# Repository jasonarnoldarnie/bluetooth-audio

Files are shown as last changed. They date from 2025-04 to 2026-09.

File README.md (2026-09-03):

# bluetooth-audio
Hardware and firmware for bluetooth audio adaptor

## Repo setup

Hooks live in `.githooks/` (version controlled), so each clone needs one command to enable them:

```bash
git config core.hooksPath .githooks
```

The `pre-commit` hook re-stamps the "Updated" date in [`docs/design-overview.tex`](docs/design-overview.tex)
and renders [`docs/design-overview.pdf`](docs/design-overview.pdf) into the same commit. It runs only
when that document is staged, never blocks a commit, and needs [Tectonic](https://tectonic-typesetting.github.io/)
(XeTeX) on `PATH` or in `%LOCALAPPDATA%\Programs\Tectonic` (Python is used only for the date stamp).
The diagrams render in the Consolas monospace font (a Windows system font); on other platforms swap it
for another mono font with box-drawing glyphs in the document preamble.

- `git config hooks.designpdf false` — disable without deleting the hook
- `git config hooks.designpdf.snapshot true` — also keep a dated copy under `docs/snapshots/`

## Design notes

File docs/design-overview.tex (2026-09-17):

% Bluetooth Audio Adaptor — Design Overview
% Rendered with Tectonic (XeTeX).  Build:  tectonic design-overview.tex
% The "Updated" date on the stamp line below is refreshed by the pre-commit hook.
\documentclass[11pt]{article}

\usepackage[a4paper,margin=2cm]{geometry}
\usepackage{fontspec}
% Latin Modern is served from Tectonic's bundle by filename (by-name lookup is unreliable here).
\setmainfont{lmroman10-regular.otf}[
  BoldFont       = lmroman10-bold.otf,
  ItalicFont     = lmroman10-italic.otf,
  BoldItalicFont = lmroman10-bolditalic.otf,
]
% Consolas is a Windows system font, resolved by name; it has the box-drawing glyphs the
% ASCII diagrams need (Latin Modern Mono does not).
\setmonofont{Consolas}[Scale=0.85]
\usepackage{textcomp}
\usepackage{amssymb}
\usepackage[table,dvipsnames]{xcolor}
\usepackage{tabularx}
\usepackage{booktabs}
\usepackage{longtable}
\usepackage{array}
\usepackage{enumitem}
\usepackage{fancyvrb}
\usepackage{newunicodechar}
\usepackage{parskip}
\usepackage[hidelinks]{hyperref}
\usepackage{underscore} % must load late: lets SIGNAL_NAMEs be typed with a literal _

\setcounter{secnumdepth}{2}
\setcounter{tocdepth}{2}
\fvset{fontsize=\footnotesize}
\newcolumntype{L}[1]{>{\raggedright\arraybackslash}p{#1}}

% --- Unicode glyphs used in prose/tables (verbatim blocks bypass these) ----------
\newunicodechar{≈}{\ensuremath{\approx}}
\newunicodechar{≤}{\ensuremath{\le}}
\newunicodechar{≥}{\ensuremath{\ge}}
\newunicodechar{→}{\ensuremath{\rightarrow}}
\newunicodechar{←}{\ensuremath{\leftarrow}}
\newunicodechar{↔}{\ensuremath{\leftrightarrow}}
\newunicodechar{×}{\ensuremath{\times}}
\newunicodechar{−}{\ensuremath{-}}
\newunicodechar{±}{\ensuremath{\pm}}
\newunicodechar{·}{\textperiodcentered}
\newunicodechar{°}{\textdegree}
\newunicodechar{µ}{\textmu}
\newunicodechar{μ}{\textmu}
\newunicodechar{Ω}{\ensuremath{\Omega}}
\newunicodechar{Ω}{\ensuremath{\Omega}} % U+2126 ohm sign
\newunicodechar{θ}{\ensuremath{\theta}}
\newunicodechar{Δ}{\ensuremath{\Delta}}
\newunicodechar{τ}{\ensuremath{\tau}}
\newunicodechar{π}{\ensuremath{\pi}}
\newunicodechar{‖}{\ensuremath{\|}}
\newunicodechar{∥}{\ensuremath{\|}}
\newunicodechar{✓}{\ensuremath{\checkmark}}
\newunicodechar{✅}{\ensuremath{\checkmark}}
\newunicodechar{⁴}{\textsuperscript{4}}
\newunicodechar{✗}{\ensuremath{\times}}

% Callout box for notes / accepted risks
\newenvironment{callout}
  {\par\medskip\noindent\begin{minipage}{\linewidth}\color{black}%
   \setlength{\parskip}{4pt}\leftskip=1.5em \rightskip=1em\relax}
  {\end{minipage}\par\medskip}

% Document stamp (hook updates the date)
\newcommand{\docrev}{Rev B (in design)}
\newcommand{\docdate}{2026-09-17}
\newcommand{\docauthor}{Jason}

\begin{document}

\begin{center}
  {\LARGE\bfseries Bluetooth Audio Adaptor — Design Overview}\\[6pt]
  {\large\textbf{\docrev} · Updated \docdate\ · \docauthor}
\end{center}

Describes the \textbf{target design}. Deltas from as-built Rev~A are listed in §10.

\begin{callout}
Living document. Every confirmed design change lands here. Planning, open questions and review
findings live in \texttt{requirements-design.md} and \texttt{design-review-v1.md} — not here.
\end{callout}

\hrule
\section{Function}

Bluetooth audio adaptor for a car AUX input. Powered from USB-C or an internal Li-ion cell.

\begin{tabularx}{\linewidth}{@{}l X l@{}}
\toprule
\textbf{Mode} & \textbf{Path} & \textbf{Status} \\
\midrule
\textbf{RX} (primary) & Phone → Bluetooth A2DP → codec DAC → 3.5 mm out & Rev A hardware complete \\
\textbf{TX}           & 3.5 mm in → codec ADC → Bluetooth → headphones/speaker & Rev B addition \\
\textbf{HFP} handsfree & On-board mic → codec ADC → BT; BT → DAC → jack & Rev B addition \\
\bottomrule
\end{tabularx}

\textbf{Key constraint:} must work with all phones, not just recent ones → \textbf{Bluetooth Classic
(A2DP/HFP), not BLE Audio}. This single requirement determines the MCU (§5).

\textbf{Out of scope:} amplified speaker output, multipoint pairing, app control.

\section{Architecture}

\textbf{Power tree}

\begin{Verbatim}
                      ┌──────────────────┐
                      │  Li-ion cell     │──── NTC ──► TS   temperature qualification
                      │  + 10 k NTC      │
                      └────────▲─────────┘
                               │ BAT ──[100k]──┬── BAT_ADC ──► ADC1
                               │               └──[100k]── GND
  USB-C ── VBUS 5 V ──► ┌──────┴───────┐
    ├─ USBLC6 (ESD)     │   BQ24074    │  power path · DPPM
    ├─ CC1/CC2 ──► ADC1 │   charger    │  SYS clamped ≤ 4.4 V
    └─ C47 10 µF        └──┬───────┬───┘
                           │       ├── EN1 / EN2  ◄── GPIO   input-limit select
       ILIM ISET ──────────┘       ├── /PGOOD, /CHG ──► GPIO
       ITERM TMR                   │
                               SYS │ 3.0 – 4.4 V
                     ┌─────────┴─────────┐
                     ▼                   ▼
              ┌─────────────┐     ┌─────────────┐
              │   LDO A     │     │   LDO B     │
              │  AP7361C    │     │  LP5907     │
              │  SOT-89 1 A │     │  low noise  │
              └──────┬──────┘     └──────┬──────┘
                     │ 3V3_A             │ 3V3_B
                     │                   │
         ESP32 · flash · CH340K       ES8388 · MEMS mic
              · LEDs  (280 mA pk)          (20 mA)
\end{Verbatim}

\textbf{Signal chain}

\begin{Verbatim}
   40 MHz XTAL ──┐        ┌── W25Q32JV 4 MB flash
                 │        │
   PCB antenna   │        │ SPI          USB-C ── USBLC6 ── CH340K
   + C-L-C match─┤        │                                    │
                 ▼        ▼                                    │ UART
              ┌──────────────────────────┐                     │ + DTR/RTS
              │     ESP32-D0WD-V3        │◄────────────────────┘
              │  BT Classic + BLE        │
              └──────┬────────────┬──────┘
                 I2C │        I2S │  (MCLK/SCLK/LRCK/DSDIN/ASDOUT)
                     ▼            ▼
              ┌──────────────────────────┐
              │   ES8388 stereo codec    │
              └───▲──────────┬───────▲───┘
             LIN1 │  LOUT1/  │       │ LIN2/RIN2
                  │  ROUT1   ▼       │
                  │      ┌───────────┴───────┐
                  │      │  TS5A23159 SPDT   │  TX / RX select
                  │      └─────────┬─────────┘
                  │                │ 47 µF coupling (jack side)
                  │                ▼
          on-board MEMS mic   3.5 mm TRS jack
          (ZTS6216 single-ended)
\end{Verbatim}

\textbf{Rails}

\begin{tabularx}{\linewidth}{@{}l l X X@{}}
\toprule
\textbf{Rail} & \textbf{Source} & \textbf{Loads} & \textbf{Why separate} \\
\midrule
SYS 3.0–4.4 V & BQ24074 & Both LDOs & Power path: USB when present, battery when not \\
3V3_A & LDO A & ESP32, flash, CH340K, LEDs & Carries RF current bursts \\
3V3_B & LDO B (LP5907) & ES8388, mic & Isolates a 96 dB codec from those bursts \\
\bottomrule
\end{tabularx}

\section{Power subsystem}

Linear regulation throughout. A switching converter was rejected: this is a mixed-signal audio
board and the efficiency gain does not pay for the noise.

\begin{tabularx}{\linewidth}{@{}l l X@{}}
\toprule
\textbf{Part} & \textbf{Function} & \textbf{Key spec} \\
\midrule
\textbf{BQ24074RGTR} (C54313) & Power-path charger & 1.5 A, SYS clamped ≤4.4 V, DPPM, NTC input, 10.5 V OVP \\
\textbf{AP7361C-33Y5-13} (C460397) & LDO A — digital/RF & SOT-89-5, 1 A, ultra-low dropout \\
\textbf{LP5907MFX-3.3} (C80670) & LDO B — codec analog & 6.5 µV\textsubscript{RMS}, high PSRR, no bypass cap needed \\
\textbf{USBLC6-2SC6} & USB ESD & In-line on D+/D−; its \texttt{VBUS} pin stays at the connector, upstream of the charger \\
Li-ion cell + 10 k NTC & Energy & Removable. NTC bonded to cell, not PCB \\
\bottomrule
\end{tabularx}

\textbf{VBUS reaches exactly three things:} the ESD array, the charger's \texttt{IN} pin, and
\texttt{C47}. Every other load in the system hangs off \texttt{SYS}, including both LDOs. That is what
makes the board behave identically on USB and on battery.

\subsection{Power path — the five loops}

In priority order. The system load always outranks the battery.

\begin{tabularx}{\linewidth}{@{}l l X@{}}
\toprule
\textbf{Loop} & \textbf{Trips at} & \textbf{Behaviour} \\
\midrule
Input current limit & \texttt{EN1}/\texttt{EN2} + \texttt{R_ILIM} & Hard ceiling on total current into \texttt{IN}. Everything else lives inside this budget \\
VIN-DPM & V\textsubscript{IN} falls to 4.5 V & Reduces input current so a weak source cannot be crashed. \textbf{Active only in USB100/USB500 modes} \\
DPPM & V\textsubscript{SYS} falls to V\textsubscript{O(REG)} − 100 mV ≈ 4.3 V & Cuts \textit{charge} current to hold SYS up. Charge termination is disabled while active \\
Battery supplement & V\textsubscript{SYS} < V\textsubscript{BAT} − 40 mV & Charge current already zero and the load still exceeds the input limit — BATFET turns fully on and the cell supplements. Exits above V\textsubscript{BAT} − 20 mV \\
Thermal regulation & T\textsubscript{J} ≥ 125 °C & Folds back charge current regardless of the above \\
\bottomrule
\end{tabularx}

The last three slow the safety timers \textbf{in proportion to the charge-current reduction}. A
deliberately low \texttt{R_ISET} gets no such slowdown — the timer would run at full speed while the
cell trickled. This is why \texttt{R_ISET} is set \textit{above} anything the input can deliver, and
DPPM is left to mediate (§3.3).

\subsection{Input current limit — mode strapping}

\texttt{EN2}/\texttt{EN1} select the limit. Datasheet Table 7-2 orders the columns EN2, EN1:

\begin{tabularx}{\linewidth}{@{}c c l X@{}}
\toprule
\textbf{EN2} & \textbf{EN1} & \textbf{Limit} & \textbf{When} \\
\midrule
0 & \textbf{1} & \textbf{475 mA (USB500)} & \textbf{Power-on default} — and any unknown or default-USB source \\
1 & 0 & 1.073 A (\texttt{R_ILIM}) & Firmware has confirmed a ≥1.5 A source (§3.4) \\
0 & 0 & 95 mA (USB100) & Strict compliance on an un-enumerated host port \\
1 & 1 & — & Standby / USB suspend \\
\bottomrule
\end{tabularx}

\textbf{The default must be USB500, not USB100.} Both pins floating gives USB100 through the chip's
285 kΩ internal pulldowns, and 100 mA cannot run a 171 mA system: with a flat cell the board would
brown out before firmware ran and could never raise the limit. USB500 boots the system, matches what
a PC port allows after enumeration, and is a mode that has VIN-DPM behind it.

\begin{Verbatim}
   SYS ──[R30 100k]──┬── EN1 ──► GPIO (drive open-drain)     default HIGH (3.26 V)
                     │
                (285k internal pulldown)

   GND ──[R31 100k]──┴── EN2 ──► GPIO (push-pull)            default LOW
\end{Verbatim}

\textbf{100 kΩ, not 0 Ω} — the GPIO must be able to override the resistor. Against the internal
285 kΩ, EN1 sits at 4.4 × 285/385 = 3.26 V, comfortably over the 1.4 V V\textsubscript{IH}.

\textbf{Pull up to \texttt{SYS}, not \texttt{3V3_A}} — \texttt{3V3_A} does not exist until the system
has booted, and the whole point of the default is to be defined before that. \texttt{SYS} is present
whenever either source is, and at 4.4 V max sits inside the EN pin's 1.4–6 V window (7 V absolute
max).

Drive \texttt{EN1} open-drain: the pull-up is to 4.4 V and the GPIO drives 3.3 V. Leave both pins
alone whenever \texttt{/PGOOD} is high-Z — the EN inputs are ignored in power-down mode, and driving
EN1 low would only burn cell current through R30.

\subsection{Charge programming}

\begin{tabularx}{\linewidth}{@{}l l X l@{}}
\toprule
\textbf{Resistor} & \textbf{Value} & \textbf{Formula} & \textbf{Result} \\
\midrule
\texttt{R_ISET} & 1.2 kΩ \textbf{1 \%} & I\textsubscript{CHG} = K\textsubscript{ISET}/R, K = 890 & \textbf{742 mA} (664–812 over spread) \\
\texttt{R_ILIM} & 1.5 kΩ & I\textsubscript{IN(max)} = K\textsubscript{ILIM}/R, K = 1610 & \textbf{1.073 A} \\
\texttt{R_ITERM} & 3.0 kΩ & I\textsubscript{TERM} = 0.03 × R\textsubscript{ITERM}/R\textsubscript{ISET} & \textbf{75 mA} (≈C/27 on a 2000 mAh cell) \\
\texttt{R_TMR} & 56 kΩ & t\textsubscript{MAXCHG} = 10 × K\textsubscript{TMR} × R, K = 48 s/kΩ & \textbf{7.5 h} (5.6 h worst case) \\
\bottomrule
\end{tabularx}

Pre-charge falls out of the same ISET resistor: K\textsubscript{PRECHG}/R\textsubscript{ISET} =
88/1200 = \textbf{73 mA}, the conventional 10 \% of fast charge.

742 mA is 0.37C on a 2000 mAh cell and 0.25C on a 3000 mAh one — safe for either, so this resistor
does not depend on the cell decision. Use 1 \% on \texttt{R_ISET}: TI calls this out specifically to
avoid tripping the internal RISET short-circuit test.

\textbf{\texttt{ILIM} must never be left open — an open \texttt{ILIM} pin disables all charging.}
Worth an explicit bring-up check.

\texttt{R_NTC_LIN} is fitted \textbf{DNP} by design: it stands in for the pack NTC if a cell without
one is used, or can be replaced by a high-value linearising resistor. It must not be populated
alongside a real NTC — see §3.6.

\subsection{Source capability detection}

The default is USB500, so detection only ever has to answer one question: \textbf{is this a ≥1.5 A
charger?} Everything else falls back safely.

\textbf{CC sensing (C-to-C only).} \texttt{R36}/\texttt{R37} tap CC1/CC2 through 1 kΩ into ADC1. With
Rd = 5.1 kΩ:

\begin{tabularx}{\linewidth}{@{}l l X@{}}
\toprule
\textbf{Source Rp} & \textbf{V\textsubscript{CC}} & \textbf{Advertised} \\
\midrule
56 kΩ & 0.42 V & Default USB \\
22 kΩ & 0.94 V & 1.5 A \\
10 kΩ & 1.69 V & 3.0 A \\
\bottomrule
\end{tabularx}

Thresholds: >0.2 V attached, >0.66 V ≥ 1.5 A, >1.23 V = 3.0 A. Read \textbf{both} pins — only one
carries the Rp, the other is open or is VCONN, and the pair also gives plug orientation. \textbf{No
filter capacitor on the CC nodes:} the spec caps sink CC capacitance at ≈200 pF. Multisample in
software instead. Re-read periodically; a source may change its advertisement at any time.

\textbf{The limitation that shapes the architecture:} a USB-A-to-C cable is \textit{required} by the
spec to contain a 56 kΩ Rp, so CC always reports Default USB no matter how large the charger behind
it. For the expected majority case — an A-to-C cable — CC sensing tells you nothing.

\textbf{BC1.2 (not fitted).} The only mechanism that unlocks a USB-A wall charger, by detecting that
D+ is shorted to D− through ≤200 Ω (a Dedicated Charging Port). Needs a detector IC — BQ24392 or
MAX14636 — whose integrated D+/D− isolation switch also solves the problem that the CH340K sits on
that bus. Deferred; the EN1/EN2 GPIO control above is what keeps it a firmware-plus-one-IC change
rather than a respin.

\textbf{Guard rail.} ILIM mode has no VIN-DPM, so a wrong detection has no graceful foldback.
\texttt{R38}/\texttt{R39} (100 k / 47 k) divide VBUS to \texttt{USB_VBUS_SENSE} — 5.0 V → 1.60 V,
5.5 V → 1.76 V — with \texttt{C53} 100 nF at the tap. Firmware reverts to USB500 if VBUS sags below
≈4.5 V. The divider only draws (34 µA) when USB is present, so it costs nothing on battery.

100 nF rather than the 1 µF used on \texttt{BAT_ADC}: this is a protection function with a deadline.
Against the divider's 32 kΩ Thévenin impedance it gives τ = 3.2 ms, so a 100 ms poll sees a collapse
≈30 τ after it happens. A larger cap would average over a third of the reaction window.

\textbf{Do not} probe adaptively — stepping up to ILIM mode and watching what happens. Without
VIN-DPM the failure mode is a brownout, not a graceful foldback.

\begin{callout}
\textbf{Accepted risk — CC pins have no ESD protection.} The USBLC6 covers D+/D− and VBUS only. CC1
and CC2 are exposed contacts in the receptacle and are directly touchable, so IEC 61000-4-2 contact
discharge is a live threat. The 1 kΩ series resistors (\texttt{R36}/\texttt{R37}) protect the ADC
pins but not \texttt{R4}/\texttt{R5} or the connector node itself. They also bound a VBUS-to-CC
short — which the USB-C spec requires sinks to survive — to (5 − 3.6)/1 k ≈ 1.4 mA of clamp injection
at the ESP32, which the pin tolerates; a faulty 20 V source would push 16 mA, which it does not.

\textbf{Decision (2026-08-30): not mitigated in Rev B.} The fix, if it is ever wanted, is a
low-capacitance TVS array on CC1/CC2 placed at the connector ahead of \texttt{R36}/\texttt{R37} —
sub-pF against the ≈200 pF sink CC budget, and low leakage so it does not corrupt the resistive
advertisement. TPD4E05U06 is the obvious candidate. Revisit if field units show USB-C detection
failures.
\end{callout}

\subsection{Safety timers}

\texttt{R_TMR} = 56 kΩ gives a 7.5 h fast-charge timer (5.6 h worst case) and a 45 min pre-charge
timer. Leaving \texttt{TMR} floating selects the internal default of 5 h typ / 4 h min; grounding it
disables the timers entirely.

The timer must outlast the slowest legitimate charge. Worst case is a 3000 mAh cell charging in
USB500 mode while playing: ≈304 mA of charge current against 742 mA programmed is a 0.41 reduction,
so the 5.6 h timer counts at 0.41× and covers 13.7 h of wall clock against an 8.9 h charge.

On expiry the part latches a fault and \textbf{\texttt{/CHG} flashes at ≈2 Hz}. Firmware should
decode that — it is also how a TS fault surfaces, and it is otherwise invisible.

\subsection{Battery temperature qualification}

Mandatory in hardware, not firmware. \texttt{TS} sources 75 µA into the pack thermistor and compares:

\begin{Verbatim}
V_HOT  = 300 mV   →  R_TS ≤ 4.0 kΩ   →  too hot    (≈50 °C on a 10 k 103AT-2)
V_COLD = 2100 mV  →  R_TS ≥ 28 kΩ    →  too cold   (≈ 0 °C)
\end{Verbatim}

The valid window is therefore \textbf{4.0 kΩ – 28 kΩ}, which a bare 10 k Type-2 NTC maps onto
0–50 °C with 3 °C hysteresis. Any added network shifts those trip points: a 10 kΩ resistor in
parallel with the NTC moves the hot trip to ≈33 °C, and a 1 kΩ resistor pins R\textsubscript{TS}
below 1 kΩ permanently, inhibiting all charging. \textbf{Fit the pack NTC or \texttt{R_NTC_LIN},
never both.}

\subsection{Status and state of charge}

\texttt{/PGOOD} and \texttt{/CHG} are open-drain, pulled up to \textbf{\texttt{3V3_A}} (not
\texttt{SYS}) so both nets are clean 3.3 V logic a GPIO can read directly — pulling them to the 4.4 V
SYS rail would exceed the ESP32's input rating.

\begin{tabularx}{\linewidth}{@{}l l X@{}}
\toprule
\textbf{/PGOOD} & \textbf{/CHG} & \textbf{State} \\
\midrule
Hi-Z & Hi-Z & Running on battery \\
Low & Low & Charging \\
Low & Hi-Z & Charge complete, or suspended \\
Low & \textbf{2 Hz flash} & Fault — safety timer expired, or TS out of range \\
\bottomrule
\end{tabularx}

\texttt{R28}/\texttt{R29} are 330 Ω, giving ≈2.7 mA per LED at 3.3 V — visible, and inside the 5 mA
the \texttt{/PGOOD} and \texttt{/CHG} open-drain outputs are specified to sink. Both LEDs are dark on
battery, since the pins go high-impedance with no input present.

\textbf{State of charge} is voltage-based: \texttt{R34}/\texttt{R35} form a 100 k / 100 k divider
from \texttt{BAT} to ground, tapped as \texttt{BAT_ADC} (4.2 V → 2.1 V, inside ADC1's usable
150–2450 mV window at 11 dB attenuation). It costs 21 µA continuously, ≈15 mAh/month — negligible
against the cell.

\textbf{\texttt{C52} 100 nF at the tap is not optional, and it is not impedance matching.} It does
two jobs:

\begin{itemize}[leftmargin=1.4em]
\item \textbf{Charge reservoir.} The ESP32's ADC is successive-approximation: closing the sampling
  switch requires an internal sample-and-hold capacitor of a few pF to charge to the input voltage
  \textit{through the external source impedance}, in a few microseconds. The divider's Thévenin
  impedance is 100 k ‖ 100 k = \textbf{50 kΩ}, five times Espressif's <10 kΩ guideline, so without a
  local cap each conversion drags the node down and the converter digitises the droop. At ≈10⁴ times
  the S/H capacitance, \texttt{C52} supplies that charge with no measurable sag and refills through
  the 50 kΩ between samples.
\item \textbf{Low-pass filter.} f_c = 1/(2π × 50 k × 100 nF) = \textbf{31.8 Hz}, τ = 5 ms.
  \texttt{BAT_ADC} is a high-impedance trace crossing the board — exactly the node that collects
  switching and RF noise — and cell voltage moves over minutes, so heavy filtering is free accuracy.
  Allow ≈25 ms after power-up before trusting a reading.
\end{itemize}

The alternative was a lower-impedance divider: 10 k / 10 k needs no cap but draws 210 µA from the
cell permanently instead of 21 µA. The capacitor is the cheaper trade.

Calibrate with \texttt{esp_adc_cal} and the eFuse Vref, and multisample; raw ADC error is ±6 \%,
which is ±250 mV of cell voltage and useless.

Two limits define what this can deliver. The reading is meaningless while charging — the charger is
driving V\textsubscript{BAT} toward 4.2 V — so firmware uses the \texttt{/PGOOD}+\texttt{/CHG} state
instead and snaps to 100 \% on termination. And the Li-ion OCV curve is flat from roughly 20 \% to
80 \% SoC, so voltage alone gives ±10–15 \% there. \textbf{This is a four-segment gauge and a
dependable low-battery warning, not a trustworthy percentage.} If a real percentage is ever needed
over AVRCP, add a MAX17048 to the existing I²C bus.

\subsection{ESP32 GPIO map (committed 2026-08-31, netlist-verified)}

Complete map. The budget is \textbf{full}: one spare (\texttt{GPIO33}). \textbf{S} marks an ESP32
strapping pin — its level is latched at reset, so anything on it must present the right level at boot
(see the implications list below). All analog is on \textbf{ADC1} because ADC2 is dead whenever the
radio is on.

\footnotesize
\begin{longtable}{@{}c c L{3.4cm} c c L{6.2cm}@{}}
\toprule
\textbf{GPIO} & \textbf{Pin} & \textbf{Signal} & \textbf{Dir} & \textbf{S} & \textbf{Boot level / notes} \\
\midrule
\endfirsthead
\toprule
\textbf{GPIO} & \textbf{Pin} & \textbf{Signal} & \textbf{Dir} & \textbf{S} & \textbf{Boot level / notes} \\
\midrule
\endhead
0 & 23 & \texttt{MCLK} (I²S) & out & \textbf{S} & Must be HIGH at boot. Internal PU; codec MCLK input is Hi-Z at reset. Auto-boot pulls it low for download. \\
1 & 41 & \texttt{UART_TX} (U0TXD → CH340 RXD) & out & & Boot-log UART. \\
2 & 22 & \texttt{CHARGE_EN} (→ charger \texttt{/CE}) & out & \textbf{S} & Must be LOW/float at boot — and \texttt{R32} (1 k→GND) holds it low, which also = \textbf{charging enabled}. FW drives HIGH to pause charging; any reset re-enables (fail-safe). Keeps TP4. \\
3 & 40 & \texttt{UART_RX} (U0RXD ← CH340 TXD) & in & & \\
4 & 24 & \texttt{AUDIO_VCC_EN} (→ LDO B EN) & out & & \texttt{R33} pulldown → codec rail \textbf{off at boot}; FW raises to power codec. \\
5 & 34 & \texttt{AUDIO_SW} (→ TS5A23159 IN1+IN2) & out & \textbf{S} & Internal PU → HIGH at boot = \textbf{TX} by default. \textbf{Do not add an external pull.} FW sets \textbf{LOW = RX}, HIGH = TX. \\
6–11 & 31,32,33,28,29,30 & SPI flash (\texttt{CLK}/\texttt{SD0-3}/\texttt{CMD}) & — & & Reserved for \texttt{VDD_SDIO} flash. Not available. \\
12 & 18 & \texttt{MTDI} (JTAG TDI) & I/O & \textbf{S} & \textbf{VDD_SDIO voltage select — must be LOW at boot for 3.3 V flash.} Pull-up \texttt{R26} is \textbf{DNP — do not populate.} A debugger driving TDI high across reset bricks boot. \\
13 & 20 & \texttt{MTCK} (JTAG) & I/O & & J4 DNP header. \\
14 & 17 & \texttt{MTMS} (JTAG) & I/O & & J4 DNP header. \\
15 & 21 & \texttt{MTDO} (JTAG TDO) & I/O & \textbf{S} & Must be HIGH at boot (enables boot log). Internal PU. \\
16 & 25 & \texttt{EN1} (charger limit) & out (OD) & & Drive \textbf{open-drain} (pull-up is to 4.4 V SYS). Ext 100 k→SYS = USB500 default at boot. \\
17 & 27 & \texttt{EN2} (charger limit) & out & & Ext 100 k→GND = default LOW at boot. \\
18 & 35 & \texttt{I2C_CLK} & I/O & & To ES8388 + codec bus. \\
19 & 38 & \texttt{LED_GREEN} & out & & \\
21 & 42 & \texttt{CH340_EN} (→ Q2 gate) & out & & \texttt{R40} pulldown → \textbf{default ON} so the bridge is powered for flashing; FW drives HIGH to disable on battery. \\
22 & 39 & \texttt{LED_BLUE} & out & & \\
23 & 36 & \texttt{I2C_DATA} & I/O & & \\
25 & 14 & \texttt{LRCK} (I²S) & I/O & & \\
26 & 15 & \texttt{DSDIN} (I²S) & out & & \\
27 & 16 & \texttt{SCLK} (I²S) & I/O & & \\
32 & 12 & \texttt{/CHG} (charger status) & in & & ADC1_CH4 used as digital in. \\
33 & 13 & \textbf{spare} & — & & ADC1_CH5. Fit a no-connect flag. \\
34 & 10 & \texttt{BAT_ADC} & in & & ADC1_CH6, input-only. \\
35 & 11 & \texttt{ASDOUT} (I²S data in) & in & & ADC1_CH7, input-only — correct home for an input-only signal. \\
36 & 5 & \texttt{USB_CC1} & in & & ADC1_CH0, input-only. \\
37 & 6 & \texttt{USB_CC2} & in & & ADC1_CH1, input-only. \\
38 & 7 & \texttt{/PGOOD} (charger status) & in & & ADC1_CH2, input-only. \\
39 & 8 & \texttt{USB_VBUS_SENSE} & in & & ADC1_CH3, input-only. \\
\bottomrule
\end{longtable}
\normalsize

\textbf{Strapping-pin implications (the ones that bite):}

\begin{itemize}[leftmargin=1.4em]
\item \textbf{GPIO0 / GPIO2} — the boot-mode pair. Normal boot needs GPIO0 high, GPIO2 low. GPIO0
  doubles as MCLK (codec input Hi-Z at reset, so safe) and the auto-boot circuit pulls it low to
  flash. GPIO2 = \texttt{CHARGE_EN}, held low by \texttt{R32} — which satisfies both "low at boot"
  \textit{and} "charging enabled by default." FW must only drive GPIO2 high (pause charge)
  \textit{after} boot.
\item \textbf{GPIO12 (MTDI)} — sets flash voltage at reset. It \textbf{must be low} (→ 3.3 V);
  \texttt{R26} is the 1.8 V pull-up and is \textbf{DNP by design}. HW: never populate \texttt{R26}.
  FW/bench: an attached JTAG debugger can drive TDI high across reset and select 1.8 V, bricking
  boot — either detach during power-up or burn the \texttt{XPD_SDIO_*} eFuses to force 3.3 V
  (irreversible).
\item \textbf{GPIO15 (MTDO)} must be high at reset (internal PU handles it); leave it undriven at
  boot.
\item \textbf{GPIO5 (AUDIO_SW)} samples high at reset (SDIO-timing strap, irrelevant here).
  Consequence: the audio switch defaults to \textbf{TX} at boot. Harmless (no audio yet); FW drives
  it \textbf{low = RX} on init. The only HW rule: \textbf{do not tie an external pull to GPIO5}, or
  it fights the strap.
\item General FW rule: every strapping pin used as an output must be left as an input (Hi-Z) through
  reset and only driven once the app starts — external pulls (or the internal strap pull) set the
  boot state.
\end{itemize}

\textbf{Safety.} Charging is inhibited outside the cell's temperature window in hardware via the NTC
on \texttt{TS} — not in firmware. Cell is removable; device is not stored in the vehicle.

\textbf{Why not LFP:} 3.2 V nominal sits below the 3.3 V rail for most of its discharge, forcing a
boost converter in front of the codec.

\section{Audio subsystem}

\textbf{ES8388} stereo codec — 24-bit, 96 dB DAC dynamic range, −83 dB THD+N. Chosen over the ESP32's
internal DAC for quality, and over a DAC-only part because HFP needs an ADC.

\begin{tabularx}{\linewidth}{@{}l X@{}}
\toprule
\textbf{Signal} & \textbf{Connection} \\
\midrule
Control & I²C, address \textbf{0x20} (\texttt{CE} pulled to DGND) \\
Audio & I²S, codec as \textbf{slave}; full duplex for HFP \\
Clocks & MCLK, SCLK, LRCK from ESP32 \\
Output (RX) & LOUT1/ROUT1 → analog switch → 47 µF → 10 Ω → jack \\
Input (TX) & Jack → 10 Ω → 47 µF → analog switch → LIN2/RIN2 \\
Input (mic) & ZTS6216 → 100 nF C0G (C41) → LIN1 (+). Pseudo-diff ready: RIN1 (−) → 100 nF C0G (C42) → GND, enabled by fitting R41 (DNP) + \texttt{LINSEL=11} \\
\bottomrule
\end{tabularx}

\textbf{All four codec rails run at 3.3 V.} DVDD/PVDD at 1.8 V would put the codec's I/O in a
different logic domain from the 3.3 V ESP32 — see §7.

\begin{tabularx}{\linewidth}{@{}l l X@{}}
\toprule
\textbf{Part} & \textbf{Function} & \textbf{Key spec} \\
\midrule
\textbf{ES8388} & Stereo codec & QFN-28, 0.4 mm; AVDD/HPVDD/DVDD/PVDD all 3V3 \\
\textbf{ZTS6216} (ZillTek) & MEMS microphone & LGA top-port, self-biased single-ended, 65 dB PSRR + EMI filter, SNR 65 dB(A), 1.5–3.6 V \\
\textbf{TS5A23159DGS} (C42751) & TX/RX path switch & Dual SPDT, ~1 Ω R\textsubscript{on}, break-before-make \\
\textbf{PJ-3537S} (C2689709) & 3.5 mm TRS jack & 3-pole (T/R/S) + detect switch \\
\textbf{EEEFT1E470AR} (C336270) & Coupling caps C1/C21 & Panasonic 47 µF 25 V, D5×5.8 mm electrolytic \\
\textbf{GRM31C5C1H104JA01L} (C97946) & Mic coupling C41/C42 & Murata 100 nF C0G 50 V 1206 — Class-1, non-microphonic (ZTS6216 requires it) \\
\bottomrule
\end{tabularx}

\textbf{Output coupling.} 47 µF electrolytic (C1/C21) blocks the VMID bias. \textbf{One pair sits on
the jack side of the switch and serves both directions} (RX out and TX in) — the switch stays on the
codec side where both throws are at VMID, inside its 0–VCC range. Into a ≈10 kΩ AUX load that is a
≈0.34 Hz corner. The \textbf{+ terminal faces the codec/VMID side}; R22/R23 (100 kΩ) bleed the jack
side to 0 V to suppress insertion pops. The large value lengthens VMID settling (τ ≈ 2 s), so
firmware mutes across power-up and TX/RX switching. \textbf{The mic coupling caps C41/C42 are C0G}
(Murata C97946) — the ZTS6216 forbids Class-2 dielectrics near the mic; sizing in §8.

\textbf{TX-input protection — removed (2026-09-17).} D7/D8 (2× BAT54S dual series Schottky) formerly
clamped LIN2/RIN2 to AVDD/GND. They were pulled: \texttt{LIN2}/\texttt{RIN2} are internal line-level
nets with no external connector, so the codec's own ESD structures suffice, and the BAT54S junction
capacitance ($\sim$10 pF) and reverse leakage only degraded the high-impedance analog input.
\textbf{TX input is line-level-only} (≤ ~1 V\textsubscript{RMS}, PGA at 0 dB): no attenuator is
fitted — cutting the level would only degrade the common quieter sources, and the codec clips softly
on an over-range source rather than faulting.

\textbf{Ground loop.} Chassis ground (USB charger) and head-unit audio ground form a loop →
alternator whine. R7/R8 are plain 10 Ω series resistors — \textbf{no transformer footprint is
provisioned} — so \textbf{battery-only playback (USB unplugged) is the ground-loop plan of record}.
Transformer isolation, if ever wanted, is a footprint change on a future spin.

\section{Microcontroller \& RF}

\textbf{ESP32-D0WD-V3.} QFN-48, 0.35 mm pitch, dual-core Xtensa LX6.

\textbf{Selected for firmware capability, not silicon features:} it is the only Espressif part whose
radio hardware supports \textbf{Bluetooth Classic}, and the only one whose SDK provides an \textbf{A2DP
sink} and \textbf{HFP}. ESP32-S3/C3/C6/H2 and the entire Nordic nRF range are BLE-only. This choice
follows directly from §1's compatibility requirement.

\begin{tabularx}{\linewidth}{@{}l l X@{}}
\toprule
\textbf{Part} & \textbf{Function} & \textbf{Key spec} \\
\midrule
\textbf{ESP32-D0WD-V3} & MCU + radio & BT Classic + BLE + Wi-Fi; needs external flash \\
\textbf{W25Q32JV} & Program store & 4 MB, 3.3 V (\texttt{JV} not \texttt{JW}), on VDD_SDIO \\
40 MHz crystal & Reference & ±10 ppm required; load caps per §7 \\
PCB inverted-F antenna + C-L-C match & 2.4 GHz & 50 Ω controlled impedance, 4-layer \\
\bottomrule
\end{tabularx}

\textbf{RF front end is a deliberate learning exercise.} A pre-certified module would remove the
matching network, crystal trim and impedance routing — that is precisely the work being kept.
Requires a NanoVNA (antenna S11) and a frequency-offset measurement to close.

\textbf{Stackup:} 4-layer. Signal / GND / PWR / Signal, with a solid ground plane under the RF
section.

\section{Programming \& debug}

No USB peripheral on this ESP32 variant, and no SWD (Xtensa, not ARM).

\begin{tabularx}{\linewidth}{@{}l l X@{}}
\toprule
\textbf{Path} & \textbf{Parts} & \textbf{Use} \\
\midrule
USB auto-program & CH340K + UMH3N dual transistor on DTR/RTS & Day-to-day flashing \\
Off-board serial & J3 header (DNP) & Fallback \\
JTAG & J4 2×5 header (DNP), ESP-PROG & Debugging \\
\bottomrule
\end{tabularx}

Headers are DNP — fit before a debug session. 13 test points cover I²C, mic, audio out, boot, GPIO
and rails.

\section{Key calculations}

\textbf{Power budget}

\begin{tabularx}{\linewidth}{@{}X l r@{}}
\toprule
\textbf{Load} & \textbf{Rail} & \textbf{Current} \\
\midrule
ESP32, BT Classic streaming (avg) & A & 130 mA \\
ESP32 transmit peak & A & 250 mA \\
SPI flash & A & 5 mA \\
CH340K (USB attached only) & A & 10 mA \\
2× LED @ 330 Ω & A & 8 mA \\
\textbf{Rail A} & & \textbf{155 mA avg · 280 mA peak} \\
ES8388 @ 3.3 V, playback + record & B & 18 mA \\
MEMS mic & B & 0.4 mA \\
\textbf{Rail B} & & \textbf{≈20 mA} \\
\bottomrule
\end{tabularx}

\textbf{LDO A thermal.} Bluetooth bursts last 1–2 ms; package time constant is seconds, so the
junction integrates to the average, not the peak.

\begin{Verbatim}
P_avg = (4.4 − 3.3) × 0.155 = 0.17 W
SOT-89, θJA ≈ 100 °C/W  →  ΔT = 17 °C  →  Tj ≈ 87 °C at 70 °C ambient      ✓
SOT-23-5, θJA ≈ 200 °C/W →  ΔT = 34 °C  →  Tj ≈ 104 °C                     ✓ but tight
\end{Verbatim}

\textbf{LDO A dropout → usable battery.} Dropout, not current, is the binding spec.

\begin{Verbatim}
Cutoff = 3.3 V + V_dropout(280 mA)

  150 mV → 3.45 V → ~87 % of cell
  250 mV → 3.55 V → ~83 %
  400 mV → 3.70 V → ~75 %
  1.2 V  → 4.50 V → will not run on battery       (NCP1117, Rev A — removed)
\end{Verbatim}

\textbf{Runtime} (LDO path, ≈83 \% usable): 1000 mAh ≈ 4.8 h · 2000 mAh ≈ 9.7 h · 3000 mAh ≈ 14.5 h.

\textbf{Charge current and time.} \texttt{R_ISET} programs 742 mA, but the input limit is what
actually binds in every mode except ILIM. CC delivers ≈85 \% of capacity; the CV tail to a 75 mA
termination adds ≈0.5 h.

\begin{tabularx}{\linewidth}{@{}l l l l l l@{}}
\toprule
\textbf{Mode} & \textbf{Input} & \textbf{System} & \textbf{Charge} & \textbf{2000 mAh} & \textbf{3000 mAh} \\
\midrule
USB500, idle & 475 mA & ≈20 mA & 455 mA & 4.2 h & 6.1 h \\
USB500, playing & 475 mA & 171 mA & 304 mA & 6.1 h & 8.9 h \\
ILIM, either & 1.073 A & 20–171 mA & \textbf{742 mA} (ISET binds) & 2.8 h & 3.9 h \\
\bottomrule
\end{tabularx}

\textbf{Charger thermal.} Linear, so the charger burns (V_IN − V_BAT) × I_CHG plus the pass-FET loss.
Worst case is the start of fast charge, V_BAT ≈ 3.0 V, in ILIM mode:

\begin{Verbatim}
P = (5.0 − 4.4) × 0.913  +  (4.4 − 3.0) × 0.742  =  0.55 + 1.04  =  1.59 W
VQFN-16 RGT, θJA = 44.5 °C/W  →  ΔT = 71 °C  →  Tj ≈ 96 °C at 25 °C ambient     ✓
                                                Tj ≈ 116 °C at 45 °C ambient    ✓ (reg. point 125 °C)
USB500 mode: P = 0.71 W  →  ΔT = 32 °C  →  Tj ≈ 57 °C                           ✓
\end{Verbatim}

The input current limit is what guarantees this — raising \texttt{R_ISET} cannot overheat the part,
because \texttt{ILIM} caps the current before it gets there.

\textbf{Crystal load capacitance.}

\begin{Verbatim}
CL = (C1 × C2)/(C1 + C2) + C_stray        C_stray ≈ 2–5 pF

Rev A: 18 pF ‖ 18 pF → 9 + 3 ≈ 12 pF against a 10 pF crystal → over-loaded, frequency low
Rev B: ≈ 15 pF ‖ 15 pF → 7.5 + 3 ≈ 10.5 pF, then trim on measured offset (±10 ppm required)
\end{Verbatim}

\textbf{Logic-level compatibility (why all codec rails are 3.3 V).}

\begin{Verbatim}
ESP32   VIH(min) = 0.75 × 3.3 = 2.475 V     VIL(max) = 0.825 V
Codec at PVDD 1.8 V: VOH ≈ 1.8 V  →  lands between VIL and VIH = undefined
Codec abs-max input = DVDD + 0.3 V = 2.1 V  →  3.3 V drive exceeds it
\end{Verbatim}

\textbf{Audio coupling-capacitor sizing.} Every audio path is AC-coupled around the codec's VMID
(≈1.65 V) bias; each blocking cap forms a high-pass with the impedance it works into,
f\textsubscript{−3dB} = 1/(2π R C). Two families:

\emph{Jack DC-blocking caps — C1/C21, 47 µF.} One shared pair on the jack side of the TX/RX switch
carries \textbf{both} directions, so it is sized for the \emph{lowest} impedance it ever sees:

\begin{Verbatim}
RX (codec → jack): load = car head-unit AUX/line input ~10–20 kΩ  (10 kΩ = worst case)
                   f = 1/(2π · 10 kΩ · 47 µF) = 0.34 Hz
TX (source → codec): load = ES8388 line input 20 kΩ (external source Z is low)
                   f = 1/(2π · 20 kΩ · 47 µF) = 0.17 Hz
   bleed R22/R23 = 100 kΩ ∥ load → negligible shift
\end{Verbatim}

The 10 kΩ AUX case binds; 47 µF puts even that at 0.34 Hz — no audible bass rolloff, with headroom
for a head unit nearer 5 kΩ. (1 µF would be ≈16 Hz into 10 kΩ — audibly thin; hence the
electrolytic.) + terminal to the codec/VMID side; slow settling → mute across mode switches.

\emph{Mic DC-blocking caps — C41/C42, 100 nF C0G.} These work into the \textbf{ES8388 ADC/PGA input
impedance of 20 kΩ} (datasheet §8.3, Analog Input):

\begin{Verbatim}
f = 1/(2π · 20 kΩ · 100 nF) = 79.6 Hz ≈ 80 Hz
\end{Verbatim}

80 Hz is well below the HFP voice band (300 Hz–3.4 kHz) — only ≈−0.3 dB at 300 Hz — so speech is
unaffected, with margin if the PGA input impedance falls below 20 kΩ at gain. Both legs (C41 on +,
C42 on −) use the \emph{same} 100 nF part so the pseudo-differential high-pass stays balanced.
Dielectric is \textbf{C0G} (Murata C97946): Class-1 ceramic is non-microphonic and voltage-linear,
as the ZTS6216 requires ("no Class-2 dielectrics near the microphone").

\section{Conceptual circuits}

\textbf{Microphone — single-ended default, pseudo-differential-ready (ZTS6216).} The ZTS6216 has one
internally self-biased output, 65 dB PSRR and an on-die RF/EMI filter, so even single-ended it is
defensible next to the radio (the old differential rationale was for a −45 dB-PSRR part). The board
also provisions a \textbf{pseudo-differential} option: the mic drives LIN1 (+) while a matched C0G
cap references RIN1 (−) to ground, so the ES8388's differential ADC (\texttt{LINSEL=11}; default
pair LINPUT1-RINPUT1) rejects common-mode supply/ground noise. SNR 65 dB(A) — adequate for HFP voice.

\begin{Verbatim}
   AVDD ──┬── MIC VDD (pin 4)        C41, C42 = 100 nF C0G (Class-1, non-microphonic;
   [100 nF‖10 µF] C43/C44             ZTS6216 forbids Class-2 near the mic). See §8 for sizing.
          │
         GND
   mic OUT ──╫ C41 ─────────────► LIN1 (+)

   GND ──╫ C42 ──[ R41 ]── RIN1 (−)   R41 (0 Ω) DNP → default single-ended (RIN1 open;
                                       keep right ADC powered down). Fit R41 + set
                                       LINSEL=11 → pseudo-differential. C54 = DNP
                                       alternate position for C42 (near codec).
\end{Verbatim}

\textbf{TX/RX switch — placement is critical.}

\begin{Verbatim}
              ┌──────────────┐
  LOUT1 ──────┤ NC (RX)      │
              │   TS5A23159  ├── COM ──╫ 47 µF ──► jack tip
  LIN2  ──────┤ NO (TX)      │
              └──────┬───────┘
                     │ IN ── ESP32 GPIO
\end{Verbatim}

Switch sits on the \textbf{codec side} of the coupling capacitor. Both throws are at VMID (≈1.65 V),
inside the switch's 0–3.3 V supply rails. On the jack side the signal is centred at 0 V and every
negative half-cycle would clip.

\textbf{RF match — C-L-C Pi, per Espressif.}

\begin{Verbatim}
  ESP32 LNA_IN ──┬──[ L series ]──┬────── PCB antenna
                 │                │
              [C shunt]        [C shunt]        Values tuned on measured S11.
                 │                │             50 Ω controlled-impedance trace.
                GND              GND
\end{Verbatim}

\section{Firmware dependencies}

Hardware choices that constrain firmware, or vice versa.

\footnotesize
\begin{longtable}{@{}L{3.2cm} L{\dimexpr\linewidth-3.9cm}@{}}
\toprule
\textbf{Item} & \textbf{Note} \\
\midrule
\endfirsthead
\toprule
\textbf{Item} & \textbf{Note} \\
\midrule
\endhead
\textbf{Bluetooth Classic} & Only the original ESP32 has Classic radio hardware. A2DP sink + HFP come from ESP-IDF/ESP-ADF. Drives the entire MCU selection. \\
\textbf{Pairing persistence} & Bluedroid writes bonding keys to \textbf{NVS in flash} automatically. Survives power-off with no battery. Requires an initialised NVS partition. \\
\textbf{MCLK pin} & ESP32 can emit MCLK only on GPIO0/1/3. GPIO1/3 are the UART, so \textbf{GPIO0} — which is also the BOOT strapping pin. Safe: the codec's MCLK input is high-Z at reset. \\
\textbf{ADC} & Use \textbf{ADC1 only} (battery sense). ADC2 is unusable while the radio is active. GPIO32–39 free. \\
\textbf{Flash mode} & Either works: IO2/IO3 uncrossed on the schematic 2026-08-31 (delta \#4 applied), so QIO is now safe. DIO remains a fine default. \\
\textbf{JTAG + GPIO12} & MTDI is the VDD_SDIO strapping pin. A debugger driving TDI high across reset selects 1.8 V and the 3.3 V flash fails. Fix: burn \texttt{XPD_SDIO_*} eFuses to force 3.3 V. \textbf{Irreversible.} \\
\textbf{Codec I²C address} & 0x20 (\texttt{CE} low). ESP-ADF's ES8388 driver default. \\
\textbf{I²S full duplex} & Required for HFP. Configure both TX and RX channels. \\
\textbf{TX/RX switch} & \texttt{AUDIO_SW} (GPIO5) drives both TS5A23159 control inputs (IN1+IN2 tied — the two switches are the L/R channels of one select). \textbf{LOW = RX} (jack ← LOUT1/ROUT1), \textbf{HIGH = TX} (jack → LIN2/RIN2). GPIO5 is a strapping pin: boot default is HIGH (=TX); FW must set LOW for playback on init. \\
\textbf{Charge enable} & \texttt{CHARGE_EN} (GPIO2) → charger \texttt{/CE}, active-low. \texttt{R32} holds it low = charging enabled at boot; FW drives HIGH to pause charging. GPIO2 is a strapping pin (must be low at boot) — the pulldown satisfies both. A reset re-enables charging (fail-safe); the NTC still guards temperature regardless. \\
\textbf{Deep sleep} & If used for battery standby, populate the CAP2 RC network. \\
\textbf{Charger limit sequencing} & Boot default is USB500 (§3.2). Firmware may raise to ILIM mode only after confirming a ≥1.5 A source. Drive \texttt{EN1} open-drain; leave both pins alone when \texttt{/PGOOD} is high-Z. \\
\textbf{CC read} & \texttt{USB_CC1}/\texttt{USB_CC2} on \textbf{ADC1}. Read both, take the one in a valid band. An A-to-C cable always reports Default USB — do not treat that as a fault. \\
\textbf{\texttt{/CHG} fault} & A ≈2 Hz flash is a latched fault (timer expiry or TS out of range), not "charging". Decode it; clear by toggling \texttt{CE} or the input. \\
\textbf{SoC blindness} & \texttt{BAT_ADC} is meaningless while charging. Report charger state instead, and snap to 100 \% when \texttt{/CHG} releases. \\
\textbf{Codec rail} & \texttt{AUDIO_VCC_EN} is pulled low, so LDO B is \textbf{off at reset}. Firmware must enable it before touching the codec on I²C/I²S, or the ESP32 will back-power the ES8388 through its ESD diodes. \\
\textbf{CH340K gate} & Bridge is on a GPIO-controlled switch. Keep it off when USB is absent (≈10 mA of battery budget) and during any BC1.2 detection. \\
\bottomrule
\end{longtable}
\normalsize

\section{Deltas from Rev A (as built)}

\footnotesize
\begin{longtable}{@{}c L{\dimexpr0.5\linewidth-1cm} L{\dimexpr0.5\linewidth-1cm}@{}}
\toprule
\textbf{\#} & \textbf{Change} & \textbf{Reason} \\
\midrule
\endfirsthead
\toprule
\textbf{\#} & \textbf{Change} & \textbf{Reason} \\
\midrule
\endhead
1 & Codec rails 1.8 V → 3.3 V; delete 1.8 V LDO, add dedicated codec LDO & Logic-level incompatibility + supply noise \\
2 & \texttt{CE} pulled to DGND & Was floating — indeterminate I²C address \\
3 & Add 10 nF on ESP32 \texttt{CAP1} & Required by datasheet; was absent \\
4 & Swap flash IO2/IO3 & Crossed; corrupts QIO reads \\
5 & Delete mic bias network (R21/R22/R23/C43/C44); add RC on mic VDD & Electret circuit on a self-biased part \\
6 & Mic → ZTS6216 (self-biased single-ended, top-port) & ICS-40720 discontinued; ZTS6216's 65 dB PSRR + on-die EMI filter makes a single-ended connection viable next to the radio \\
7 & LED resistors 1 kΩ → 330 Ω & ≈0.3 mA was invisible \\
8 & TRRS → 3-pole TRS jack (PJ-3537S, T/R/S + detect switch) & 4th pole unused \\
9 & Add TX input path + analog switch & TX mode now in scope \\
10 & Add battery charger, NTC, cell connector, VBAT sense & Battery in scope \\
11 & NCP1117 → low-dropout LDO in SOT-89 & 1.2 V dropout cannot run from a cell \\
12 & Crystal load caps 18 pF → ≈15 pF, then trim & Over-loaded; ±10 ppm required \\
13 & Charger input limit made firmware-selectable (\texttt{EN1}/\texttt{EN2} on GPIOs, 100 kΩ pulls) & Fixed strap cannot adapt to source capability; default USB500 boots on a flat cell \\
14 & \texttt{/PGOOD}, \texttt{/CHG} pull-ups moved SYS → 3V3_A and routed to GPIOs & 4.4 V exceeds the ESP32 input rating; status was LED-only \\
15 & Add \texttt{BAT_ADC} divider, CC1/CC2 sense taps & State of charge (REQ-PWR-10) and source detection \\
16 & Gate the CH340K on a GPIO & ≈10 mA of battery budget with USB absent \\
17 & Output coupling 1 µF MLCC → 47 µF electrolytic (C1/C21, Panasonic C336270) on the jack side; add 100 kΩ jack-side bleed (R22/R23) & Deep bass margin, one shared bidirectional cap, pop suppression \\
18 & TX-input clamps D7/D8 (2× BAT54S) added, then \textbf{removed 2026-09-17} & Net: no clamps (as Rev A). LIN2/RIN2 are internal line-level nets; the BAT54S capacitance/leakage degrade the input for no ESD benefit \\
19 & Mic coupling → 100 nF C0G (C41/C42, Murata C97946, 1206); provision pseudo-diff (R41 0 Ω + C54 alt, both DNP) & ZTS6216 forbids Class-2 near the mic; option to reject common-mode noise later \\
20 & ES8388 OUT2 → TP6 test-output couplers 1 µF MLCC → 47 µF electrolytic (C24/C26, Panasonic C336270), matching C1/C21; + terminal to the codec/VMID side & Removes Class-2 ceramic coupling distortion; one shared coupler part across the board \\
\bottomrule
\end{longtable}
\normalsize

\textbf{Still open:} cell choice (2000 mAh pouch vs 3000 mAh 18650) and therefore charge time; whether
to fit BC1.2 detection; ground-loop mitigation (transformers vs battery-only playback); crystal
offset measurement; RF match tuning; BOM line consolidation.

\textbf{Accepted risks:} CC pins carry no ESD protection (§3.4) — decided 2026-08-30, not mitigated
in Rev B.

\textbf{Micro-sheet status} (§3 describes the target). Tracking the 2026-08-31 micro-sheet review
(\texttt{design-review-micro.md}) and the fixes applied since.

\textit{Applied on the schematic (verified against netlist 2026-08-31):}
\begin{itemize}[leftmargin=1.4em]
\item ✅ \textbf{UART TX/RX crossover fixed} — \texttt{UART_RX} = \{ESP32 U0RXD, CH340 TXD\},
  \texttt{UART_TX} = \{U0TXD, CH340 RXD\}. Board can now be flashed. (was S1)
\item ✅ \textbf{Flash IO2/IO3 uncrossed} — SPIWP(GPIO9)→IO2, SPIHD(GPIO10)→IO3. QIO-safe now.
  (delta \#4, was S1)
\item ✅ \textbf{Digital rail unified} — micro \texttt{+3V3} renamed to \texttt{+3V3_SYS}, tied to the
  LDO A output (U7.5). The stray \texttt{+3V3} symbol on the ESP32 \texttt{EN} pull-up (R11) was also
  switched to \texttt{+3V3_SYS}, so \texttt{EN} is no longer floating.
\item ✅ \textbf{CH340K load switch drawn} (delta \#16) — \texttt{Q2} AO3401A (SOT-23, LCSC C15127)
  high-side P-FET: source \texttt{+3V3_SYS} → drain \texttt{CH340_VCC} → CH340 VCC/V3 + C19. Gate
  \texttt{CH340_EN} on \textbf{GPIO21}, with \texttt{R40} 100 kΩ \textbf{pull-down = default-ON} (so
  the ROM bootloader is powered for flashing with no firmware). Firmware drives GPIO21 \textbf{high to
  disable} the bridge on battery. Note: when off, the bridge's UART/DTR/RTS pins can still back-feed
  its dead VCC through clamp diodes — tristate the ESP32 UART pins when disabling, or accept the small
  leakage.
\item ✅ \textbf{Full ESP32 interface wired} (§3.8) — \texttt{EN1}/\texttt{EN2}/\texttt{/PGOOD}/%
  \texttt{/CHG}/\texttt{BAT_ADC}/\texttt{USB_CC1}/\texttt{USB_CC2}/\texttt{USB_VBUS_SENSE}/%
  \texttt{AUDIO_VCC_EN}/\texttt{CHARGE_EN} all land on GPIOs; all four analog senses on ADC1. The
  TX/RX switch (\texttt{AUDIO_SW}, GPIO5) drives both TS5A23159 control inputs (delta \#9 now
  controllable). Charge enable (\texttt{CHARGE_EN}, GPIO2) is now firmware-controllable.
\end{itemize}

\textit{Still to do on the micro sheet:}
\begin{itemize}[leftmargin=1.4em]
\item \textbf{Crystal load caps still 18 pF} (delta \#12 not applied; target ≈15 pF then trim).
\item \textbf{Firmware LEDs D1/D3 still 1 kΩ} (delta \#7 hit the power LEDs only; blue ≈ 0.3 mA,
  invisible).
\item \textbf{\texttt{GPIO33} spare} — fit a no-connect flag so it doesn't ERC.
\item \textbf{Schematic hygiene:} stale library-symbol caches, off-grid endpoints, annotation
  errors — ERC cleanup due.
\end{itemize}

\textbf{Rev A→B deltas still unapplied:} \#7 (LED resistors — micro sheet only), \#12 (crystal caps).
Deltas \#4, \#9, \#13–17 are now on the schematic.

\textbf{Audio-sheet status} (§6 describes the target). Tracking the 2026-09-07 audio review
(\texttt{design-review-audio.md}), re-audited from a fresh netlist 2026-09-08.

\textit{Applied on the schematic (verified against netlist 2026-09-08):}
\begin{itemize}[leftmargin=1.4em]
\item ✅ \textbf{I²C pull-ups moved to +3V3\_AUDIO}, dropped to 1 kΩ (R19/R20) — they die with the
  codec rail, so gating \texttt{AUDIO\_VCC\_EN} no longer back-powers the ES8388. (was S2)
\item ✅ \textbf{L/R un-swapped} — COM1→ROUT1/RIN2 (Right)→Ring, COM2→LOUT1/LIN2 (Left)→Tip, matching
  J1's \texttt{TIP\_LEFT}/\texttt{RING\_RIGHT}. Standard stereo orientation in both RX and TX. (was S2)
\item ✅ \textbf{Jack → PJ-3537S 3-pole TRS} with detect switch (delta \#8). (was S3)
\item ✅ \textbf{47 µF electrolytic couplers} (C1/C21) on the jack side of the switch, correct
  polarity (+ to VMID side), with 100 kΩ jack-side bleed (R22/R23) (delta \#17).
\item \textbf{TX-input clamps D7/D8 removed} (2026-09-17) — were added 2026-09-08 (series-clamp
  geometry, common→signal / anode→GND / cathode→AVDD) then pulled: LIN2/RIN2 are internal line-level
  nets, so the BAT54S capacitance/leakage bought no ESD benefit (delta \#18 reversed).
\item ✅ \textbf{Mic coupling → 100 nF C0G} (C41/C42, Murata C97946, 1206), sized in §8; pseudo-diff
  option provisioned with R41 (0 Ω) and C54 both DNP (delta \#19, \#6).
\end{itemize}

\textit{Open / notes on the audio sheet:}
\begin{itemize}[leftmargin=1.4em]
\item ✅ \textbf{TX input level — decided line-level-only} (2026-09-08). Expect ≤ ~1 V\textsubscript{RMS}
  with the PGA at 0 dB; ES8388 full-scale in = AVDD/3.3 ≈ 1.0 V\textsubscript{RMS}. No attenuator — it
  would halve the common quieter sources (0.316 V\textsubscript{RMS} line-out → 0.16 V) and cost SNR.
  An over-range source clips softly at the codec input rather than faulting. (A7 closed)
\item \textbf{RIN1 floats in the default build} — with R41 DNP, the mic − reference is unconnected.
  Benign as long as firmware keeps the right ADC powered down; fitting R41 (which also enables
  pseudo-diff) removes it. Deliberate provisioning choice, not a defect.
\item \textbf{Firmware mute} across power-up and TX/RX switching — the 47 µF couplers give slow
  ($\sim$1–5 s) VMID settling. (A8)
\end{itemize}

\section{Manufacturing}

\textbf{JLCPCB}, 4-layer, \textbf{Economic PCBA} with the ESP32 excluded from assembly and
hand-populated (it is the only Standard-Only part). All other parts verified Economic-tier.

Constraints: single-sided placement (satisfied — nothing on the back is assembled), 0402 minimum
passive, 0.4 mm minimum IC pitch.

Build: 5 assembled + 5 bare. Target \$20 USD landed per unit.

Hand assembly: 0.35 mm-pitch QFN requires a laser-cut stencil, plugged/capped via-in-pad on the
thermal pad (open vias wick solder and degrade the RF ground), and ≈50–70 \% paste coverage on the
exposed pad.

\section{References}

\textbf{Local} (\texttt{hw/datasheets/}, \texttt{hw/app notes/})
\begin{itemize}[leftmargin=1.4em]
\item ESP32 datasheet · ESP32 Hardware Design Guidelines · ESP32 Technical Reference Manual
\item ES8388 datasheet rev 5.0 · ES8388 User Guide
\item W25Q32JV datasheet rev G
\item WCH CH340 datasheet v3B (\texttt{WCH-CH340-datasheet-v3B.pdf}) — TXD=output, RXD=input; V3→VCC at 3.3 V
\item ESP32-LyraT v4.3 schematic — reference design for the codec section
\item AN043 2.4 GHz PCB Antenna · Antennas for IoT
\end{itemize}

\textbf{External}
\begin{itemize}[leftmargin=1.4em]
\item \href{https://jlcpcb.com/capabilities/pcb-assembly-capabilities}{JLCPCB PCB assembly capabilities}
\item \href{https://docs.espressif.com/projects/esp-adf/en/latest/api-reference/abstraction/es8388.html}{ESP-ADF ES8388 driver}
\item \href{https://docs.espressif.com/projects/esptool/en/latest/esp32/espefuse/set-flash-voltage-cmd.html}{esptool — set flash voltage eFuses}
\end{itemize}

\textbf{Project}
\begin{itemize}[leftmargin=1.4em]
\item \texttt{requirements-design.md} — requirements, constraints, traceability
\item \texttt{design-review-v1.md} — netlist audit and findings (initial)
\item \texttt{design-review-micro.md} — micro-sheet review, 2026-08-31
\item \texttt{battery-power-proposal.md} — battery architecture
\item \texttt{mems-microphone-primer.md} — mic theory and selection
\end{itemize}

\section{Revision history}

\footnotesize
\begin{longtable}{@{}c c L{\dimexpr\linewidth-4.2cm}@{}}
\toprule
\textbf{Rev} & \textbf{Date} & \textbf{Change} \\
\midrule
\endfirsthead
\toprule
\textbf{Rev} & \textbf{Date} & \textbf{Change} \\
\midrule
\endhead
A & 2025-04-05 & As-built schematic, commit \texttt{369c5f9} \\
B & 2026-08-24 & This document created. Scope decisions resolved; 12 deltas in §10 \\
B & 2026-08-30 & §3 expanded to cover the full charger configuration: power-path loops, EN1/EN2 strapping, charge programming, source detection, safety timers, TS qualification, SoC and GPIO map. Deltas 13–16 \\
B & 2026-08-30 & Power sheet complete: \texttt{R_ITERM}/\texttt{R_TMR} populated, LEDs to 330 Ω, ADC anti-droop caps and VBUS sense divider added. CC ESD recorded as an accepted risk \\
B & 2026-08-31 & Micro-sheet review (\texttt{design-review-micro.md}): found UART TX/RX swap (S1) and confirmed flash IO2/IO3 still crossed; corrected the §9 "flash fixed" claim and the §3.8 GPIO map (added TX/RX switch, fixed the free-output count); expanded §10 with the undrawn micro↔power interface and unapplied deltas \\
B & 2026-08-31 & Micro-sheet fixes landed: UART crossover, flash IO2/IO3, rail unified to \texttt{+3V3_SYS} (EN pull-up reconnected), and CH340K high-side load switch drawn (Q2 AO3401A + R40 100 kΩ pull-down, gate \texttt{CH340_EN} on GPIO21, default-ON). Netlist-verified. \\
B & 2026-08-31 & Full ESP32 GPIO map committed (§3.8) with strapping-pin FW/HW implications: interface signals wired to the ESP32 (EN1/EN2, /PGOOD, /CHG, ADC senses, AUDIO_VCC_EN, CHARGE_EN→GPIO2), \texttt{AUDIO_SW}→GPIO5 driving both TS5A23159 inputs (LOW=RX, HIGH=TX). Verified TS5A23159 pinout against TI datasheet — COM=jack/NC=codec-out/NO=codec-in, both channels symmetric (a prior review note claiming asymmetry was wrong, now withdrawn). \\
B & 2026-09-03 & Design overview converted from Markdown to LaTeX (Tectonic/XeTeX build) for easier manual editing. Content unchanged. \\
B & 2026-09-07 & Audio sheet re-reviewed from a fresh netlist (\texttt{design-review-audio.md}). Folded confirmed audio decisions into §2/§6/§8/§9/§10: single-ended ZTS6216 mic (was differential SPH8878), 47 µF electrolytic jack-side couplers C1/C21 + R22/R23 bleed (was 1 µF MLCC), PJ-3537S TRS jack, L/R and I²C-pull-up-rail fixes. Corrected the stale "isolation-transformer footprints provisioned" claim — R7/R8 are plain 10 Ω, battery-only is the ground-loop plan. Also recorded the earlier withdrawal of the ES8388 OUT1-vs-OUT2 line/headphone distinction (no such split in the datasheet). \\
B & 2026-09-08 & Audio caps + clamps finalized against the netlist: TX-input clamps to 2× BAT54S (D7/D8, common→signal / anode→GND / cathode→AVDD); mic DC-blocking caps to 100 nF C0G (Murata C97946, 1206) with a provisioned pseudo-differential option (R41 0 Ω + C54 alt, both DNP). Added §8 coupling-cap sizing calculations — jack couplers vs the car-AUX load (0.34 Hz into 10 kΩ) and mic caps vs the ES8388 20 kΩ ADC input (80 Hz). I²C pull-ups noted at 1 kΩ. TX input level decided \textbf{line-level-only} (PGA 0 dB, no attenuator; clamps = damage protection) — A7 closed. \\
B & 2026-09-16 & Pre-layout BOM pass on the audio sheet: ES8388 OUT2 → TP6 test-output couplers C24/C26 → 47 µF electrolytic (Panasonic C336270, matching C1/C21, + to codec/VMID side), removing Class-2 ceramic coupling distortion (delta \#20); \texttt{C53} VBUS-sense filter 1206 → 0402 (house part C1525); \texttt{C41}/\texttt{C42} mic couplers footprint aligned to plain \texttt{C\_1206\_3216Metric} (matching C54). Decided to remove the D7/D8 TX-input clamps (\texttt{LIN2}/\texttt{RIN2} are internal line-level nets, no external exposure). All PCB footprints now placed in initial positions; V1 routing pending. \\
B & 2026-09-17 & Removed the D7/D8 TX-input clamps (2× BAT54S) from the audio sheet — LIN2/RIN2 are internal line-level nets with no external exposure, so the codec's own ESD structures suffice and the Schottky capacitance/leakage were a net cost (delta \#18 reversed; §6/§9 clamp text removed). Library housekeeping: dropped the orphaned in-project symbol/footprint copies and re-based the project on the \texttt{kicad-library} submodule; verified every custom symbol and footprint reference resolves to it. \\
\bottomrule
\end{longtable}
\normalsize

\end{document}

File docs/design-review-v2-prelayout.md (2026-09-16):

# System Design Review — Bluetooth Audio Adaptor, Rev B (pre-layout)

**Date:** 2026-09-14
**Reviewer:** netlist-level audit against primary datasheets
**Scope:** Final schematic review before starting PCB layout.
**Verdict:** One blocking S1 (board cannot power up as drawn), plus a small cluster of
integration/value defects. **The three S1 defects from [`design-review-v1.md`](design-review-v1.md)
are all now correctly fixed.** Fix the items in §6 "before layout" and the board is ready.

---

## 0. How this review was done

Connectivity was taken from the **exported netlist**, not the schematic PDF or memory:
`bluetooth-audio.kicad_sch` (root + `micro`/`power`/`audio` sheets) exported to KiCad XML via the
IPC backend at commit `9141db3`, then parsed pin-by-pin. Every finding below is stated against a
net and, where a pin function was in doubt, verified against the datasheet in `hw/datasheets/`.

| Checked against | Document (local) | Used for |
|---|---|---|
| ESP32-D0WD-V3 | `esp32_datasheet_en.pdf` | Flash SDIO pin functions, strapping-pin internal pulls |
| W25Q32JV | referenced (Winbond rev G) | Flash IO0–IO3 pinout |
| ES8388 | `..._ES8388_C365736.pdf` | Codec supply pins, CE, I²S/I²C |
| TS5A23159 | `TI-TS5A23159-SCDS201H.pdf` | Dual-SPDT channel pin grouping |
| ERC | KiCad IPC `run_erc` | Corroboration (10 errors / 82 warnings) |

Confidence labels: **Confirmed** = verified against netlist + cited datasheet; **Estimated** =
calculated, arithmetic shown; **Needs bench/library check** = cannot be settled from the netlist.

**Not re-verified this pass** (trusted as-is): CH340K auto-program transistor network (Q1/Q2 detail),
exact RF match values (a known NanoVNA bring-up task), thermal figures (unchanged from the overview).

---

## 1. Corrections to previous reviews

**The old flash IO2/IO3 finding is fixed — and I nearly re-flagged it wrongly.** Reasoning from
memory, "SPIHD should go to the flash /HOLD pin" looks like a swap. It is not. Espressif's own
recommended flash connection table (ESP32 datasheet, Pin Definitions) maps `SD_DATA_2/SPIHD → IO2`
and `SD_DATA_3/SPIWP → IO3`, and the schematic now matches it exactly. Recorded as **confirmed
correct** in §3. The lesson the skill warns about held: the datasheet, not recall, settled it.

**WITHDRAWN — the audio L/R "swap" (this review's own finding #2). It was my error; the design is
correct.** I paired C1 with R8 by adjacent ref-des numbering instead of following the net. The
actual path is: codec **right** (ROUT1/RIN2) → U3 COM1 (pin10) → C1 → **R7** → jack RING (right);
codec **left** (LOUT1/LIN2) → U3 COM2 (pin6) → C21 → **R8** → jack TIP (left). Left↔left,
right↔right — correct in both directions, RX and TX. The trap: on a dual-SPDT the COM-to-jack
routing crosses the ref-des order (C1→R7→ring, not C1→R8→tip), so eyeballing the pairing inverts the
conclusion. Following the net, not the numbering, is the only reliable read.

---

## 2. Headline findings

| # | Sev | Finding | Affects | Status |
|---|-----|---|---|---|
| 1 | **S1** | **U9 (BQ24074) was marked DNP** and nothing else sources `+V_SYS` → whole board unpowered. Confirmed a stray flag. | REQ-PWR-01/02/03/04, all | ✅ **Fixed** — DNP cleared (owner confirmed) |
| 2 | ~~S2~~ | ~~Audio L/R swapped through the TX/RX switch.~~ | — | ❌ **WITHDRAWN** — reviewer error, design is correct (§1) |
| 3 | **S2** | `R39 = 100k`, should be **47k**: VBUS-sense tap = VBUS/2 = 2.5 V, above ADC1's 2.45 V ceiling. | source-detect guard-rail | ✅ **Fixed** — R39 → 47k |
| 4 | **S2** | Crystal load caps still **18 pF** (Rev A); overview's Rev B target is 15 pF → 10 pF crystal over-loaded. | REQ-MCU-06 | ⏳ Owner will recalc; not blocking |
| 5 | **S3** | **C53 pad 1 floating** — VBUS-sense filter not connected to `USB_VBUS_SENSE`. | source-detect guard-rail | ✅ **Fixed by owner** |
| 6 | **S3** | **D1 is a WHITE LED** on 3.3 V/330 Ω → ~0.3–0.9 mA, dim. | REQ-MCU-07 | ✔️ Accepted by owner |
| 7 | **S3** | ERC: U3 units had **different footprints** (TSSOP vs MSOP). Datasheet package is **VSSOP (DGS) = MSOP-10**, not TSSOP. | manufacturability | ✅ **Fixed** — all units → MSOP-10 |
| 8 | **S3** | ERC: `JACK_DET` sheet pin has no matching label inside its sheet (+ associated unconnected pin). | — | ⏳ Open — hierarchy cleanup |
| 9 | verify | **BAT54S (D7/D8) clamp orientation** — pin 3 is the series midpoint. | codec input protection | ✅ Confirmed correct by owner |
| 10 | — | 82 ERC "symbol doesn't match library" warnings (submodule consolidation). | ERC hygiene | ⏳ Run *Update Symbols from Library* |
| 11 | **S3** | **R1/R2 (10k) redundant** — Q1 (UMH3N) is a *pre-biased* digital transistor (LCSC C62892: "2 NPN pre-biased", DTC143-type dice with internal base + base-emitter resistors), so the external base resistors stack on the internal ones. Circuit still works. | REQ-DEV-01, BOM | ⏳ Owner to remove (wire DTR→Q1.2, RTS→Q1.5 direct) — *owner-found* |

---

## 3. Subsystem reviews

### 3.1 Power — one blocking defect, and a broken guard-rail

**What is right.** Two-LDO split is built as designed: U7 (AP7361C-33Y5, SOT-89) → `+3V3_SYS`
(digital/RF), U11 (LP5907, SOT-23-5) → `+3V3_AUDIO` (codec). U7's EN is tied to its own input
(always-on when SYS present); U11's EN is on `AUDIO_VCC_EN` (GPIO4, held low by R33 → codec off at
boot) — correct. Charge-programming resistors match the overview (R_ISET 1k2, R_ILIM 1k5, R_ITERM
3k, R_TMR 56k). EN1/EN2 strapping (R30 100k→SYS, R31 100k→GND) and the CC/BAT dividers are as
documented. **Confirmed.**

**① S1 — the board has no power source as drawn.** `+V_SYS` (which feeds both LDO inputs) connects
only to `U9` pins 10/11 (charger OUT), and **U9 is DNP**. `USB_VBUS` dead-ends at `U9` pin 13 (IN).
There is no 0 Ω link from VBUS to SYS — R3 and R14 (the only DNP 0 Ω parts) are the DTR/RTS
auto-program network, not power bypasses. So with the charger unpopulated, nothing reaches the LDOs
and the board is dead. **This is almost certainly a stray DNP flag** (every document treats the
BQ24074 as populated), but it must be resolved before layout — a DNP charger produces no `+V_SYS`
ratsnest, so the whole power path would go unplaced/unrouted. *Confirmed (netlist).* See §6 for the
decision.

**③ S2 — VBUS-sense divider out of range. [FIXED — R39 → 47k].** `R38/R39 = 100k/100k` gave
`USB_VBUS_SENSE = VBUS/2` = 2.50 V at 5.0 V (2.75 V at 5.5 V). Source: **ESP32 datasheet, ADC
Characteristics** — "Atten = 3, effective measurement range of 150–2450 mV", and the note "When
atten = 3 and the measurement result is above 3000 (voltage at approx. 2450 mV)… measurement errors
may be introduced." So the 2.50 V tap sits just past the atten-3 (11 dB) ceiling and the reading
clips/errors. Overview §3.4 specifies **100k/47k → 1.60 V**, well inside range. R39 changed to 47k.
*Confirmed (netlist + datasheet).*

**⑤ S3 — C53 filter floating.** `C53` pad 2 → GND, pad 1 → *unconnected*. The 100 nF VBUS-sense
filter (overview §3.4, τ = 3.2 ms) has no connection to `USB_VBUS_SENSE`. Pad 1 should tie to that
net. (This is ERC error "Pin not connected".) *Confirmed (netlist + ERC).*

### 3.2 Audio — one functional defect, placement otherwise excellent

**What is right.** The much-emphasised **TX/RX switch placement is correct**: the switch throws are
the codec's LOUT1/ROUT1 and LIN2/RIN2 (all biased at VMID ~1.65 V, inside the switch's 0–AVDD
window), with the 47 µF coupling caps (C1/C21) and 10 Ω (R7/R8) between the switch COM and the jack.
RX/TX selection polarity is right too (IN high = NO = LIN2/RIN2 = TX, matching the GPIO5 boot
strap). J1 is a 3-pole TRS as decided. Mic single-ended path (MK1 → C41 → LIN1) is correct; RIN1
open is the documented single-ended default (R41/C54 DNP). **Confirmed.**

**② WITHDRAWN — L/R is correct.** TS5A23159 channel grouping (datasheet §5):
Ch1 = COM1(10)/NO1(2)/NC1(9), Ch2 = COM2(6)/NO2(4)/NC2(7). Tracing the *nets* (not the ref-des
order):

- COM1 (pin 10) → C1 → **R7** → jack **RING (Right)**; throws NO1→RIN2, NC1→ROUT1 → **right codec**. ✓
- COM2 (pin 6) → C21 → **R8** → jack **TIP (Left)**; throws NO2→LIN2, NC2→LOUT1 → **left codec**. ✓

Left↔left, right↔right, both directions. My original finding paired C1 with R8 by adjacent
numbering instead of following the net — see §1. No change needed.

**⑨ Needs library check — BAT54S clamp orientation.** D7/D8 connect pin1(A)→GND, pin2(K)→AVDD,
pin3(K)→LIN2/RIN2. This is the correct BAT54S *series-clamp* topology **only if the KiCad symbol's
pin 3 is the series midpoint** (anode-D2/cathode-D1 junction). If the symbol is actually
common-anode, the upper clamp (signal→AVDD) is absent and only the negative excursion is clamped. No
rail-short risk either way. Confirm against the BAT54S datasheet before trusting the protection.
*Needs check.*

### 3.3 Microcontroller / RF — clean; one value carried over

**What is right (all confirmed against the ESP32 + Winbond datasheets):**
- **Flash IO0–IO3 exactly match Espressif's recommended connection** (SD_DATA0/SPIQ→IO1/DO,
  SD_DATA1/SPID→IO0/DI, SD_DATA2/SPIHD→IO2, SD_DATA3/SPIWP→IO3). Old S2 fixed correctly.
- **Strapping pins all safe:** MTDI (GPIO12) has an internal pull-down (datasheet: default 0 →
  3.3 V flash), so floating with R26 DNP is correct; GPIO2 held low by R32; GPIO0 internal PU +
  auto-boot; GPIO5 (AUDIO_SW) has no external pull; MCLK correctly on GPIO0 (codec input Hi-Z at
  reset). CAP2 correctly NC; spare GPIO33 flagged NC.
- **RF C-L-C pi match is present:** shunt C38 (3.3 pF) at antenna, series L1 (2.2 nH), shunt C37
  (3.3 pF) at the ESP32 LNA. Values to be tuned with the NanoVNA — a known bring-up task, not a
  defect.

**④ S2 — crystal load caps unchanged from Rev A.** C35/C36 = 18 pF against a 10 pF-CL crystal (Y1):
`CL = 9 pF + ~3 pF stray ≈ 12 pF` > 10 pF → over-loaded, frequency pulled low. The overview's own
Rev B target (§7) is **~15 pF**. Trimmable at bring-up, but it starts off-target and contradicts the
design doc. Move to 15 pF (then trim on measured offset to ±10 ppm). *Confirmed (netlist) + Estimated.*

**⑥ S3 — white LED under-driven.** D1 (LED_WHITE) is driven from GPIO22 through R12 = 330 Ω. With
white Vf ≈ 3.0–3.2 V on a 3.3 V rail, `I = (3.3 − 3.1)/330 ≈ 0.6 mA` (0.3 mA worst case) — dim, the
same headroom problem as the old blue-LED finding. Green (D3, ~3.6 mA) and the rail/charger
indicators are fine at 330 Ω. **Fix:** use a low-Vf colour (red/green/amber) for the user
indicator; white/blue on 3.3 V is fundamentally headroom-starved regardless of resistor. *Estimated.*

### 3.4 Cross-cutting

- **Always-on rail indicators.** D2 (`+3V3_SYS`) and D4 (`+3V3_AUDIO`) draw ~4 mA each continuously
  when lit — not in the power budget (which lists only 2 GPIO LEDs). On battery, an always-on power
  LED is a real drain; consider whether both are wanted, or gate them. *S3.*
- **ERC hygiene (⑦⑧ + warnings).** 10 errors / 82 warnings. Substantive: **U3B/U3C different
  footprints** (a multi-unit part must resolve to one footprint — fix before the PCB sync), and the
  `JACK_DET` sheet-pin/label mismatch. The 82 warnings are dominated by "symbol doesn't match copy
  in library" — fallout from the kicad-library submodule consolidation; run *Update Symbols from
  Library* so ERC is usable going forward. Cosmetic, but clear them before layout.

---

## 4. Part-by-part (key parts only)

| Part | Role | Verdict |
|---|---|---|
| U1 ESP32-D0WD-V3 | MCU + radio | Correct; forced by BT-Classic requirement. Flash + strapping verified. |
| U4 ES8388 | Codec | Correct: all 4 rails 3.3 V, CE→GND (0x20), 10 Ω on AVDD/HPVDD supplies. |
| U6 W25Q32JV | Flash | Correct part (JV/3.3 V) and correct IO mapping (datasheet-verified). |
| U7 AP7361C-33Y5 | LDO A | SOT-89, always-on, as designed. |
| U11 LP5907 | LDO B | Low-noise codec rail, EN on GPIO4. |
| U9 BQ24074 | Charger | **DNP — see S1.** Otherwise wired per overview. |
| U3 TS5A23159 | TX/RX switch | Right placement; **L/R swapped (S2)** + footprint ERC (S3). |
| Y1 40 MHz XTAL | Reference | OK; **load caps need 15 pF (S2)**. |

---

## 5. Requirements impact

- **REQ-PWR-01…04** are marked ✅ but the DNP charger means no rail is actually powered — status is
  currently false. Corrected by fixing S1.
- **REQ-AUD-03/07**: signal path exists and switch placement is right, but channels are reversed (S2).
- **REQ-MCU-06**: crystal loading still off the Rev B target (S2).
- No new requirement gaps surfaced — the overview already covers ambient (REQ-ENV-01, proposed),
  ground loop (REQ-AUD-05), and RF measurability (§2.9).

---

## 6. Prioritised action list

### Applied this pass (schematic files edited on disk — reload eeschema, then *Update PCB from Schematic*)
1. ✅ **U9 DNP cleared** (`power.kicad_sch`) — charger now populates and routes.
2. ✅ **R39 → 47k** (`power.kicad_sch`) — VBUS-sense tap back inside ADC range.
3. ✅ **U3 all units → MSOP-10** (`audio.kicad_sch`) — datasheet-correct (VSSOP/DGS), clears the ERC
   footprint conflict.

### Fixed by owner
- ✅ **C53 pad 1** wired to `USB_VBUS_SENSE` (verified in the re-pulled netlist).

### Still open before/around layout
- ⏳ **Crystal C35/C36** — owner to recalculate (target ~15 pF; not blocking).
- ⏳ **Run *Update Symbols from Library*** (Tools menu) to clear the 82 "doesn't match library"
  warnings, then re-pull the netlist and re-verify — a symbol update *can* move pins, so confirm the
  critical nets afterward.
- ⏳ **`JACK_DET` hierarchy error** — sheet pin with no matching label inside its sheet; clean up.

### Accepted / confirmed by owner (no change)
- ✔️ **D1 white LED** kept as-is.
- ✔️ **D2/D4 always-on** rail indicators — intentional for development, will be disabled for production.
- ✅ **BAT54S (D7/D8)** — pin 3 is the series midpoint; clamps to both AVDD and GND as intended.

---

## 7. Overall assessment

**The pattern: the design content is done and correct — the defects are the last-mile mechanical
ones.** Every hard integration question from v1 (codec logic domain, CE address, CAP1, the 10 Ω
supply resistors, flash IO mapping, strapping) is resolved and verified. What remains is a stray DNP
on the most important IC, a left/right pairing slip, two wrong/omitted passive connections in the
guard-rail, and a crystal value that didn't get updated to its own documented target. None is deep;
all are the kind that hide precisely because the surrounding design is finished and looks trustworthy.
Clear §6 and the board is ready to lay out.

*Confirmed fixes from [`design-review-v1.md`](design-review-v1.md) — recorded so they aren't undone:
codec on a dedicated 3.3 V LDO; ES8388 CE pull-down; ESP32 CAP1 10 nF; flash IO2/IO3; 10 Ω moved
from the codec outputs to between its supply pins.*

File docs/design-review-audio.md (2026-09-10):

# System Design Review — Audio Sheet (`audio.kicad_sch`)

**Reviewer:** Claude (acting as reviewing systems engineer)
**Date:** 2026-09-07
**Design under review:** `hw/bluetooth-audio/audio.kicad_sch` — working tree (uncommitted changes present), netlist re-exported 2026-09-07 from `bluetooth-audio.kicad_sch`.
**Scope:** the audio subsystem only — ES8388 codec (U4), TX/RX analog switch (U3), MEMS microphone (MK1), the 3.5 mm jack (J1) and their support circuitry.

This review **re-audits the sheet from a fresh netlist** and supersedes the 2026-09-04 audio review. The sheet has changed materially since then — the coupling capacitors, the microphone part, and the jack are all different — so every claim below is re-derived from the current netlist, not carried over.

> **Update 2026-09-08 (post-fix re-check).** The four BAT54W discretes were replaced with **2× BAT54S** (D7/D8) — wiring verified correct on the netlist: **common (pin 3) → signal, anode → GND, cathode → AVDD**, off at the VMID idle point, no rail short (§3.4a now describes this). Mic DC-blocking caps set to **100 nF C0G** (Murata **C97946**, 1206); the pseudo-differential − reference (R41 0 Ω / C54 alt) is **DNP by deliberate provisioning** — JLC places both C0G caps (C41 +, C42 −) and R41 is the hand-fit enable — so **A9 is resolved as a design choice**, the only residual being that RIN1 floats in the default build (benign while the right ADC is powered down; fitting R41 removes it). **A3 (mic-cap dielectric) is closed** (now C0G). Cap sizing is written into the design overview §8. **A7 is now decided — line-level-only, PGA 0 dB** (§3.4/§5). Remaining is firmware-only: **A8** (mute across power-up / mode switch).

---

## 0. How this review was done

Connectivity comes from the exported KiCad netlist (`export_netlist` → `parse_netlist.py`, per-component pin maps). Every device claim is checked against the primary datasheet, cited by page/line.

| Evidence source | Revision / location | Used for |
|---|---|---|
| KiCad netlist export | working tree, 2026-09-07 | all connectivity |
| **ES8388 datasheet** | Everest Semiconductor Rev 5.0 — `hw/datasheets/1912111437_…ES8388_C365736.pdf` | pin functions, supply/level, analog I/O |
| **TI TS5A23159 datasheet** | SCDS201H, Feb 2015 — `hw/datasheets/TI-TS5A23159-SCDS201H.pdf` | pinout (§5 Pin Functions), Ron, break-before-make, THD, analog range |
| **ZillTek ZTS6216 datasheet** | DS-1.4 — `hw/datasheets/ZillTek-ZTS6216-DS1.4.pdf` | supply range, self-bias, PSRR, SNR, dielectric note, top-port |
| **XKB PJ-3537S datasheet** | C2689709 — `hw/datasheets/XKB-PJ-3537S-SMT-C2689709.pdf` | jack pinout (T/R/S + switch) |

**Confidence labels:** *Confirmed* = verified against a cited datasheet + the netlist. *Estimated* = my calculation, arithmetic shown. *Needs bench check* = cannot be settled from documents.

**Errata:** ES8388, TS5A23159 and ZTS6216 are analog/fixed-function parts without published errata. Nothing to reconcile.

**Note on the TS5A23159 truth table:** the pin-function table (SCDS201H §5) was extracted cleanly; the IN→NO/NC state table is a figure that did not machine-extract, so the RX/TX direction below is stated *Confirmed* on the basis of the pin functions plus system self-consistency (RX routes the codec's NC-pin outputs to the jack), and matches the datasheet reading in the prior review.

---

## 1. Status of the previous review's findings — four of seven now fixed

The 2026-09-04 review raised A1–A7. Re-audited against the current netlist:

| # | 2026-09-04 finding | Status now | Evidence |
|---|---|---|---|
| **A1** | Codec-rail gating back-powers the ES8388 via I²C pull-ups to +3V3_SYS | **FIXED (HW)** | `R19`/`R20` (4k7) now pull `I2C_CLK`/`I2C_DATA` to **+3V3_AUDIO** — they die with the codec rail. FW tri-state rule for the I²S lines remains (documented in overview §8). |
| **A2** | L/R swapped at the jack | **FIXED** | Left → Tip, Right → Ring — see §3.2. |
| **A4** | `RIN1`/MIC− floating | **Improved** | `U4.23` now carries an explicit **no-connect flag** (ERC-clean). Electrically still an unused input in single-ended mode (acceptable); the net is cosmetically mislabelled `MIC-` — see A4′. |
| **A6** | Jack still 4-pole TRRS | **FIXED** | `J1` is now **PJ-3537S** — a 3-pole TRS with a switched (detect) contact; `SW_NC` NC-flagged. |
| **A3** | Mic coupling cap dielectric (Class-2) | **OPEN** | `C41` still 100 nF **0402** → Class-II MLCC. ZTS6216 forbids it (§3.3). |
| **A5** | Single-ended mic decision undocumented | **OPEN (doc)** | Overview still describes a *differential* SPH8878 mic — now factually wrong; this pass fixes it. |
| **A7** | TX input full-scale ~1.0 V_RMS, no attenuator | **OPEN (decision)** | No divider present; jack → 10 Ω → 47 µF → switch → LIN2/RIN2 (§3.4). |

**And the coupling-capacitor subsystem was redesigned** (1 µF MLCC → 47 µF electrolytic + jack-side bleed) — reviewed as correct in §3.2, because the topology is subtle and worth showing.

---

## 2. Headline findings (current)

| # | Sev | Finding | Requirement | Fix effort |
|---|---|---|---|---|
| A3 | **S3** | Mic coupling `C41` (100 nF 0402) is a Class-II MLCC; the ZTS6216 datasheet (DS-1.4, p.4) states plainly *"Capacitors near the microphone should not contain Class 2 dielectrics."* | REQ-AUD-01/04 | C0G in a larger case, or film |
| **A9** | **S2** | Pseudo-differential mic input: as *populated*, RIN1 (the −) is **floating** — C22 is fitted but the parts that would connect RIN1 to the reference (R41, C23) are both DNP (§3.3a). The intended noise-rejection benefit is absent and an input floats. | REQ-AUD-04 | Populate one of R41 / C23 |
| A7 | **Decided** | TX input is **line-level-only** (≤ ~1 V_RMS), PGA at 0 dB. No attenuator — it would halve the common quieter sources and cost SNR to rescue a rare hot one; the BAT54S clamps are damage protection only (a hotter source clips softly, not a fault). ES8388 full-scale in = AVDD/3.3 ≈ 1.0 V_RMS. | REQ-AUD-07 | ✅ closed 2026-09-08 |
| A5 | **S3 (doc)** | Overview mic description must track the hardware: single-ended (with the pseudo-diff option). Corrected this pass; re-confirm once A9's population is settled. | REQ-AUD-04 | Doc |
| A4′ | **S3 (cosmetic)** | Mic − net now `MIC_N`/`MIC_N_UC` (was `MIC-`). Fine, but see A9 for the population inconsistency. | — | — |
| A8 | **S3 (note)** | 47 µF couplers lengthen turn-on/mode-switch settling (τ ≈ R·C is ~10× the old 1 µF), so the mute-around-transitions rule matters more. Not a defect; a firmware/UX note. | REQ-AUD-06 | FW mute |

**One S2 remains (A9 — a DNP population slip, not an architecture fault).** The prior review's two S2 items (A1, A2) are both fixed. The sheet is layout-ready once A9 is populated correctly, A3 is re-specced and A7 is decided.

---

## 3. Subsystem detail

### 3.1 Codec supply, levels, references — right (unchanged, re-confirmed)

*Confirmed* against the netlist: `DVDD` (pin 2) and `PVDD` (pin 3) on **+3V3_AUDIO**; `AVDD` (17) via **R21 10 Ω**, `HPVDD` (16) via **R16 10 Ω**, both from +3V3_AUDIO (correct per-pin isolation off the shared LP5907 node). `CE` (26) → **R27 10 kΩ → GND** = I²C address **0x20**. Reference decoupling present as 10 µF + 100 nF pairs on VREF, ADCVREF, VMID (C27–C32). Logic levels agree in both directions (all rails 3.3 V). I²C pull-ups 4k7 to +3V3_AUDIO — still a deviation from the user guide's 1 kΩ suggestion, accepted as low-priority.

### 3.2 TX/RX switch + coupling caps (U3, C1/C21) — correct, and the redesign is good

*Confirmed* pinout (TS5A23159 SCDS201H §5): `1 IN1 · 2 NO1 · 3 GND · 4 NO2 · 5 IN2 · 6 COM2 · 7 NC2 · 8 V+ · 9 NC1 · 10 COM1`. Mapped to the netlist:

| Pin | Name | Net | Role |
|---|---|---|---|
| 1, 5 | IN1, IN2 | AUDIO_SW (GPIO5) | ganged L+R select |
| 10 | COM1 | → C1 (47 µF) → R7 → **J1 Ring (Right)** | channel-1 common |
| 9 | NC1 | ROUT1 | RX: right codec out |
| 2 | NO1 | RIN2 | TX: right codec in |
| 6 | COM2 | → C21 (47 µF) → R8 → **J1 Tip (Left)** | channel-2 common |
| 7 | NC2 | LOUT1 | RX: left codec out |
| 4 | NO2 | LIN2 | TX: left codec in |
| 8 | V+ | AVDD | supply |
| 3 | GND | GND | |

**A2 (L/R) is fixed.** RX (IN=LOW → COM–NC): COM1 carries **ROUT1 (Right)** → Ring; COM2 carries **LOUT1 (Left)** → Tip. J1 pins confirm `TIP_LEFT`/`RING_RIGHT`. **Left → Tip, Right → Ring** — standard TRS. TX (IN=HIGH → COM–NO) keeps the same channel-to-contact mapping (Right = RIN2, Left = LIN2). One mapping is correct in both directions. *Confirmed.*

**The coupling redesign is done well** (all *Confirmed* from the netlist):
- **Caps moved to 47 µF electrolytic** (`C1`/`C21`, footprint `CP_Elec_5x5.8`) on the **switch-common/jack side**, so the switch only ever passes VMID-biased signals (≈1.65 V, inside its 0–VCC range). One pair serves both directions.
- **Polarity correct:** `C1`/`C21` Pad 1 (+) → COM (VMID side); Pad 2 (−) → jack side (0 V). VMID > 0, so the + terminal is the more-positive side. ✓
- **Jack-side bleed added:** `R22`/`R23` (100 kΩ) tie the Pad-2/jack nodes to GND, defining them at 0 V when nothing is plugged in (kills insertion/removal pops). Correctly on the jack side, not the codec side.
- **High-pass corner:** *Estimated* 1/(2π·47 µF·10 kΩ) ≈ **0.34 Hz** into a car-AUX load — deep bass margin.

*Estimated / needs bench check (unchanged):* U3.V+ = AVDD ≈ 3.15–3.2 V after R21's drop; at full-scale codec output (VMID + ~1.4 V ≈ 3.0 V) the signal peak nears the switch rail where Ron/THD degrade. Ample margin at line level (~0.3–0.7 V_RMS). Keep the DAC at line level; verify full-scale THD on the bench.

### 3.3 Microphone (MK1, ZTS6216) — single-ended, self-biased, one open note

*Confirmed* from the netlist: `MK1` **ZTS6216**, output `OUT` (1) → **C41 (100 nF) → MIC_P → LIN1** (U4.24). `VDD` (4) on **AVDD**; `IDD` 120 µA typ / 150 µA max (DS-1.4 p.4) — negligible on the analog rail. Supply range **1.5–3.6 V** (abs-max 5 V), so 3.3 V AVDD is in spec. Self-biased single-ended analog output (DC 0.9 V @ VDD 1.5 V), AC-coupled through C41 — the correct front end. The board now wires **RIN1 as a pseudo-differential −** (§3.3a), which — populated correctly — turns the old floating-RIN1 concern (A4) into a used pin and buys common-mode rejection.

- **A3 — coupling-cap dielectric (S3, open).** DS-1.4 p.4: *"Capacitors near the microphone should not contain Class 2 dielectrics."* `C41` is 100 nF in **0402** — necessarily X7R/X5R (Class-II, piezoelectric, voltage-nonlinear). Use **C0G/NP0** (needs ≥0805) or film. *Estimated:* 100 nF into the codec's ~20 kΩ input is an ~80 Hz corner — fine for voice, so keep the value; only the dielectric changes.
- **A5 — single-ended vs differential (record the reasoning).** The ZTS6216's **65 dB PSRR** (DS-1.4 p.4, with internal RF/EMI filtering) is what makes a single-ended connection defensible next to the radio — unlike the older differential rationale in `mems-microphone-primer.md`, which was written for a −45 dB-PSRR part. SNR is **65 dB(A)** — ordinary, but adequate for HFP voice, the mic's only job. Sound trade; now written into the overview so it is not re-litigated.
- **Mechanical:** ZTS6216 is **top-ported** — the enclosure needs an acoustic hole above the part. LGA (do not wash the board). Check the custom footprint's land + port against the datasheet before layout.

### 3.3a Pseudo-differential mic option (MK1 → LIN1/RIN1) — sound idea, wrong population

**Concept — correct.** Driving the mic single-ended into LIN1 (+) while AC-coupling RIN1 (−) to the
mic's ground reference through a *matched* cap gives the ES8388's differential ADC a common-mode to
reject — supply/ground noise picked up between mic and codec cancels, the signal survives. With C41
and its counterpart both 100 nF the two legs high-pass together. This is the right way to get most of
a differential mic's noise rejection from a single-ended MEMS part, and it properly *uses* RIN1
(retiring A4). The pin choice is *confirmed* correct: the ES8388's L-R differential input is
**LINPUT1(+)/RINPUT1(−)** by default (Reg 10 `LINSEL=11`, `DS`/`DSR=0`, datasheet p.17) — exactly
LIN1/RIN1. Firmware dependency: set `LINSEL=11` (not the single-ended `LINSEL=00`).

**A9 — the populated set is inconsistent, so RIN1 floats (S2).** *Confirmed* from the netlist:

| Net | Nodes | Populated? |
|---|---|---|
| `MIC_P` | C41.2, **LIN1** (U4.24) | ✅ mic → C41 → LIN1 (+) |
| `MIC_N` | C22.2 (→GND), R41.1 | C22 ✅ fitted; R41 **DNP** |
| `MIC_N_UC` | **RIN1** (U4.23), C23.1, R41.2 | C23 **DNP**, R41 **DNP** |

RIN1 sits on `MIC_N_UC`, whose only neighbours are **C23 (DNP)** and **R41 (DNP)** — so **RIN1 is not
connected to anything populated. It floats.** Meanwhile the fitted cap C22 couples GND to `MIC_N`, a
stub that dead-ends at R41's unplaced pad — it does nothing. The design provisions three parts for a
one-part job and the fitted subset is the wrong one.

**Fix — populate exactly one reference path to GND, drop the rest:**
- **Simplest:** fit **C23** (100 nF, RIN1 → GND directly); leave C22 and R41 DNP. One cap, matched to C41.
- **Or:** fit **R41** (0 Ω) so RIN1 → MIC_N → C22 → GND; leave C23 DNP.
- Either way, verify C41 and the −-leg cap are the **same value** (100 nF) for a balanced high-pass.

### 3.4 Jack and TX level

- **J1 = PJ-3537S** (3-pole TRS + switch): Sleeve/GND → GND, `RING_RIGHT`, `TIP_LEFT`, `SW_NC` NC-flagged. TRS is the correct, unambiguous choice (A6 fixed).
- **A7 — TX input level: DECIDED line-level-only (2026-09-08).** Jack → R7/R8 (10 Ω) → C1/C21 → switch → LIN2/RIN2, no divider. ES8388 full-scale input = AVDD/3.3 ≈ **1.0 V_RMS**, and the PGA only adds gain (can't cut a hot source). **Decision: expect line level (≤ ~1 V_RMS), PGA at 0 dB.** No attenuator — it would halve the common quieter sources (a 0.316 V_RMS line-out → 0.16 V_RMS) and cost ~6 dB SNR just to rescue a rare over-range source. The BAT54S clamps are **damage protection only**: a source above full-scale clips softly (audible distortion the user fixes by lowering their source), not a fault. A divider is only worth it to cleanly capture a maxed ~2 V_RMS headphone-out — not a use case here.
- LOUT2/ROUT2 → C24/C26 (1 µF) → R9/R10 → TP6: intentional test-point taps. Fine.

### 3.4a TX-input Schottky clamps (D7–D10) — correct and complete

Added to protect the codec's LIN2/RIN2 inputs (and the electrolytic couplers) from a source hot
enough to drive past the rails. *Confirmed* from the netlist — a full clamp pair on each channel:

| Diode | Anode | Cathode | Fires when | Role |
|---|---|---|---|---|
| D7 | LIN2 | AVDD | LIN2 > AVDD + 0.3 V | LIN2 upper |
| D8 | GND | LIN2 | LIN2 < −0.3 V | LIN2 lower |
| D10 | RIN2 | AVDD | RIN2 > AVDD + 0.3 V | RIN2 upper |
| D9 | GND | RIN2 | RIN2 < −0.3 V | RIN2 lower |

**All four correctly oriented, and all reverse-biased at the VMID ≈ 1.65 V idle point** (uppers
because 1.65 < AVDD, lowers because 1.65 > −0.3), so there is **no DC loading of the input bias** —
the fault an earlier single-diode attempt had. Clamp window ≈ −0.3 … +3.5 V (≈ ±1.85 V, ~1.3 V_RMS
around VMID), safely above full-scale (1.0 V_RMS), so normal audio passes untouched and only gross
overdrive conducts. **Part assigned: BAT54W (LCSC C779673, ZRE), SOD-123**, ×4 — JLCPCB *Extended*
(one feeder fee for all four; junction capacitance is a non-issue at audio into 20 kΩ). Confirm
stock at BOM freeze (§2.3). This is protection, not level-setting — A7's attenuator question is
independent.

### 3.5 Cross-cutting

- **Ground loop (REQ-AUD-05):** with a battery in scope, unplugging USB breaks the chassis-ground path — the cleanest whine mitigation. **R7/R8 are plain 0402 10 Ω** — there is **no transformer/link footprint** provisioned (correcting the overview's stale "footprints accept either" claim). Battery-only playback is the plan of record; state it.
- **Settling/pop (A8):** 47 µF lengthens the VMID settling on power-up and on each TX/RX flip; mute the codec across those transitions.

---

## 4. Part-by-part

| Ref | Part | Verdict |
|---|---|---|
| U4 | ES8388 | **Keep.** Correctly supplied and levelled; 95 dB ADC / 96 dB DAC exceeds anything a car AUX resolves. |
| U3 | TS5A23159DGS | **Keep.** Correct dual-SPDT, ~1 Ω, break-before-make, THD 0.004%. Wiring verified pin-by-pin. VSSOP-10 0.5 mm clears the Economic floor. |
| MK1 | ZTS6216 | **Keep, with A3.** Self-biased single-ended, 65 dB PSRR + EMI filter, in spec on 3.3 V. SNR 65 dB(A) is the weakest spec — fine for HFP. Top-ported: needs an enclosure port. |
| J1 | PJ-3537S (TRS) | **Keep.** 3-pole TRS + detect switch; L/R correct. |
| C1, C21 | 47 µF electrolytic, `CP_Elec_5x5.8` | **Keep.** Matches Panasonic **EEEFT1E470AR (C336270)**, 25 V, D5×5.8 mm, in stock. Correct polarity/placement. Extended-tier (one feeder fee); ~6 mm tall — check enclosure height. |
| C41 | 100 nF 0402 | **Re-spec (A3)** — C0G/film. |
| D7–D10 | **BAT54W** (C779673, SOD-123) | **Keep.** Correct TX-input clamp pairs, no DC loading at VMID. Extended-tier, one feeder fee for all four. |
| MK1 − ref | C22 / C23 / R41 | **Fix population (A9)** — fit one of C23 or R41 so RIN1 is referenced, not floating; the fitted subset is currently inconsistent. |

---

## 5. Decisions — resolved

1. **A7 — TX input level:** ✅ **Decided line-level-only (2026-09-08).** Expect ≤ ~1 V_RMS, PGA at 0 dB; no attenuator; BAT54S clamps are damage protection. See §3.4.
2. **A3 — C41 dielectric:** ✅ **Resolved** — mic caps set to 100 nF C0G (Murata C97946, C41/C42).

No open decisions remain on the audio sheet.

## 6. Fix-before-layout list

**Status 2026-09-08 — all pre-layout items resolved:**
1. ~~A9 — mic − reference~~ → **deliberate DNP provisioning**: JLC places both C0G caps (C41 +, C42 −); hand-fit R41 (0 Ω) to enable pseudo-diff. RIN1 floats in the default build — benign while the right ADC is powered down.
2. ~~A3 — C41 dielectric~~ → **100 nF C0G** (Murata C97946) on C41/C42.
3. ~~A7 — TX input level~~ → **decided line-level-only**, PGA 0 dB (clamps = damage protection).

Remaining is firmware-only: **A8** (mute across power-up / TX-RX switch).

**Docs (this pass):** A5 single-ended-mic rationale and the battery-breaks-ground-loop plan folded into the design overview; ZTS6216 top-port enclosure hole flagged for mechanical.

---

## 7. Overall assessment

The audio sheet has closed out the previous review cleanly. **The prior two S2 defects (rail-gating back-power, L/R swap) are fixed, along with the TRRS→TRS jack** — and the coupling network was rebuilt into a genuinely good bidirectional design (47 µF electrolytics on the jack side, correct polarity, jack-side bleed), plus a correct four-diode TX-input clamp and a pseudo-differential mic upgrade. The remaining work is not architecture: **one population slip (A9 — the mic − reference is DNP, so RIN1 floats)**, one datasheet footnote (the mic cap's dielectric, A3), and one scope decision (TX input level, A7). Only A9 needs fixing before layout, and it's a one-part change. The pattern to watch: the audio circuits are now *right by design* but carry a couple of **DNP/population choices that must be made explicit** before the BOM is frozen — a clamp diode array and a mic reference that each provision more than they populate. This subsystem is otherwise the most complete on the board.

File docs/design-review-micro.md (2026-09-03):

# System Design Review — Micro Sheet (`micro.kicad_sch`), Rev B in progress

**Date:** 2026-08-31 · Reviewer: Claude (systems review) · Requested by: Jason

Scope: the microcontroller sheet — ESP32-D0WD-V3 (U1), SPI flash (U6), CH340K USB-UART (U2),
auto-boot transistor (Q1), 40 MHz crystal (Y1), RF match (ANT1/L1/C37/C38), boot strapping, EN/reset
network, I²C pull-ups, and the two firmware LEDs. This pass follows the completion of the power sheet,
so it pays special attention to the **micro↔power interface** the power work created.

---

## 0. How this review was done

Ground truth is the exported netlist, not the schematic PDF or memory.

| Checked | Against | How |
|---|---|---|
| Full-project connectivity | `bluetooth-audio.kicad_sch` → kicad-cli netlist | `kicad-cli sch export netlist --format kicadxml`, then `parse_netlist.py` (comp / nets / floating / bom) |
| ERC state | KiCad 10 ERC | `kicad-cli sch erc` → 92 violations, triaged below |
| ESP32 pin functions / strapping | `hw/datasheets/esp32_datasheet_en.pdf`; `hw/app notes/esp-hardware-design-guidelines-en-master-esp32.pdf` | pin-by-pin against the netlist map |
| Flash IO mapping | `hw/datasheets/...W25Q32JVZPIQ_C571260.pdf` (rev G) | SPIWP/SPIHD ↔ IO2/IO3 |
| CH340 TXD/RXD direction + 3.3 V supply | WCH CH340 datasheet v3B — downloaded to `hw/datasheets/WCH-CH340-datasheet-v3B.pdf` | pin direction and V3/VCC config |

**Confidence labels:** *Confirmed* = verified against netlist or a primary datasheet; *Estimated* =
calculated, arithmetic shown; *Needs bench check* = not settleable from documents.

**Errata:** the ESP32 has published errata (ECO/silicon anomalies). None of the findings below depend
on an erratum-sensitive area (they are connectivity, not silicon corner-cases), so a full errata pass
was deferred to the RF/bring-up review where it matters more. Flagged, not done.

**What I could not do:** local PDF page-rendering is unavailable in this environment, so ESP32/flash
pin-table citations are to the document and table by name, not page number. The connectivity claims do
not depend on that — they come from the netlist.

---

## 1. Corrections to previous conclusions

- **Design overview §9 and Delta #4 state the flash IO2/IO3 swap is "fixed in Rev B." It is not.**
  The netlist still has them crossed (Finding S1-2). The overview is describing an intended change
  that was never applied to the schematic. Corrected in the overview's "not yet on the schematic"
  list in this pass.
- **Session-log open question "what drives Rail A's `EN` pin?" is now answered by the schematic:**
  AP7361C `EN` (U7.1) is tied to `+V_SYS` — LDO A is always on. No firmware control. Recorded as
  resolved.

---

## 2. Headline findings

| # | Sev | Finding | Requirement / doc affected | Fix effort |
|---|---|---|---|---|
| S1-1 | **S1** | **CH340K UART wired straight-through, not crossed.** `UART_TX` ties ESP32 U0TXD (out) to CH340 TXD (out); `UART_RX` ties U0RXD (in) to CH340 RXD (in). Board cannot be flashed or use serial console. ERC misses it (ESP32 pin is bidirectional). | Programming/debug (§6) | Swap two nets |
| S1-2 | **S1**† | **Flash IO2/IO3 still crossed.** ESP32 SPIWP(GPIO9)→flash IO3; SPIHD(GPIO10)→flash IO2. Boots in DIO; corrupts every read in QIO/QOUT. Doc claims this was fixed. | Delta #4, §9 flash mode | Swap two nets |
| S1-3 | **S1** | **Digital rail orphaned.** ESP32/flash/CH340K sit on `+3V3`; LDO A output is `+3V3_SYS`. Two different global nets — the MCU has no regulator. (Known: overview §10.) | Power tree §2 | Rename/merge net |
| S1-4 | **S1** | **Whole micro↔power control/telemetry interface undrawn.** `EN1 EN2 /PGOOD /CHG BAT_ADC USB_CC1 USB_CC2 USB_VBUS_SENSE AUDIO_VCC_EN` and the CH340 gate reach no ESP32 pin. Charger uncontrollable, no SoC, no source detection, **codec rail can never turn on**. (Known: overview §10.) | §3.2–3.8, REQ-PWR-10 | Wire GPIOs; add labels |
| S2-1 | S2 | **TX/RX audio switch control undriven.** TS5A23159 `IN1`/`IN2` (U3.1/U3.5) float — no GPIO. TX mode (delta #9) has no way to select the path. GPIO map (§3.8) omits it. | REQ-AUD-07, §3.8 | 1 GPIO (tie IN1+IN2) |
| S2-2 | S2 | **Crystal load caps still 18 pF.** Delta #12 (→~15 pF) not applied. ~12 pF load on a 10 pF crystal → frequency pulled low, outside ±10 ppm before trim. | Delta #12, §7 | Change 2 values |
| S2-3 | S2 | **Firmware LED resistors still 1 kΩ.** D1 (blue, GPIO22/R12) and D3 (green, GPIO19/R18) at 1 kΩ. Blue draws ~0.3 mA → invisible. Delta #7 was applied to the power LEDs only. | Delta #7, §3.7 | Change 2 values |
| S3-1 | S3 | **Schematic hygiene:** 36 `lib_symbol_mismatch` (cached symbols ≠ library, from the library-repo move), 35 off-grid wire endpoints, 3 unconnected wire endpoints, annotation errors on export. Off-grid/dangling endpoints can silently drop connections. | — | ERC cleanup pass |
| S3-2 | S3 | **Rail naming is inconsistent across three schemes:** doc (`SYS`/`3V3_A`/`3V3_B`) vs schematic (`+V_SYS`/`+3V3_SYS`/`+3V3_AUDIO`) vs micro (`+3V3`). | §2 rails | Pick one; align doc |

† S1-2 is severity-S1 by *impact if QIO is enabled* but hides through bring-up in DIO — the dangerous
kind. Treat as fix-before-order.

---

## 3. Subsystem review

### 3.1 What is RIGHT (record so it is not "optimised" away)

- **ESP32 `CAP1` has its required 10 nF** (`C45`, to GND). Delta #3 / prior-review S1 fix — *applied*.
  Confirmed (netlist). `CAP2` correctly left open (deep-sleep only).
- **Strapping pins handled correctly.** MTDI/GPIO12 (VDD_SDIO select) carries a **DNP** pull-up
  (`R26` to +3V3) — the designer recognised that populating it would select 1.8 V and brick the 3.3 V
  flash. GPIO0/GPIO2/GPIO15 rely on the ESP32's internal pulls in the safe direction. GPIO0 doubles
  as MCLK; the codec's MCLK input is high-Z at reset, so the strap is not disturbed. Confirmed
  (netlist + ESP32 datasheet strapping table). **Recommend annotating `R26 = DNP – 1.8 V select, do
  not populate` on the schematic** so nobody fits it later.
- **Auto-boot circuit topology is the canonical cross-coupled one.** Q1A: collector→`EN`,
  emitter→`RTS`, base←`DTR` (via R1). Q1B: collector→`GPIO0`, emitter→`DTR`, base←`RTS` (via R2). This
  is the standard DTR/RTS reset/boot circuit that avoids the both-asserted deadlock. Confirmed
  (netlist). Exact polarity is a bench/firmware item, but the wiring is right.
- **Flash core SPI lines correct:** CS↔GPIO11, CLK↔GPIO6, IO0(DI)↔GPIO8(SPID), IO1(DO)↔GPIO7(SPIQ).
  Only IO2/IO3 are crossed (S1-2). Confirmed (netlist + W25Q32JV rev G pin table).
- **RF Pi-match topology correct:** LNA_IN — C37 (shunt) — L1 2.2 nH (series) — C38 (shunt) — antenna,
  all shunts to GND. Values are placeholders to be tuned on measured S11. Confirmed (netlist).
- **Codec ADC data (`ASDOUT`) correctly on input-only GPIO35.** Confirmed.
- **I²C:** 4.7 kΩ pull-ups to +3V3 on SDA(GPIO23)/SCL(GPIO18); test points present. Correct.
- **EN/reset:** 10 kΩ pull-up + 1 µF (≈10 ms), test point, DNP manual-reset resistor. Correct.
- **CH340K 3.3 V supply config correct:** V3 tied to VCC with external 3.3 V, per CH340 datasheet v3B.

### 3.2 The micro↔power interface (the seam the power work opened)

The power sheet is complete and internally correct — EN1 pulled to `+V_SYS` via 100 kΩ (`R30`), EN2 to
GND via 100 kΩ (`R31`), `/PGOOD`//`CHG` open-drain, the ADC dividers and VBUS-sense tap all built. But
**none of it lands on the ESP32.** Every one of these is a global label with a single node on the
micro side, or a GPIO left unconnected:

| Power-sheet signal | Netlist state | Intended ESP32 pin (§3.8) | ESP32 pin actual |
|---|---|---|---|
| `+3V3` (should be LDO A out) | separate net from `+3V3_SYS` | — | VDD pins on orphaned `+3V3` |
| `EN1` | R30 + U9.6 only | GPIO16 | GPIO16 unconnected |
| `EN2` | R31 + U9.5 only | GPIO17 | GPIO17 unconnected |
| `/PGOOD` | D5 + U9.7 only | any input | not present on U1 |
| `/CHG` | D6 + U9.9 only | any input | not present on U1 |
| `BAT_ADC` | R34/R35/C52 only | ADC1 | not present on U1 |
| `USB_CC1` | R36 only (1-node) | ADC1 | not present on U1 |
| `USB_CC2` | R37 only (1-node) | ADC1 | not present on U1 |
| `USB_VBUS_SENSE` | R38/R39/C53 only | ADC1 | not present on U1 |
| `AUDIO_VCC_EN` | R33 (pulldown) + U11.3 | any GPIO | **not driven → codec rail dead** |
| CH340 gate | *no switch drawn* | any GPIO | CH340 hard-wired to `+3V3` |

`AUDIO_VCC_EN` is the sharp one: it is pulled low by `R33` so the codec LDO is off at boot (correct
intent), but with no GPIO to raise it the codec rail **can never turn on**. Confirmed (netlist +
ERC `isolated_pin_label` on USB_CC1/CC2, `pin_not_driven` on the switch).
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

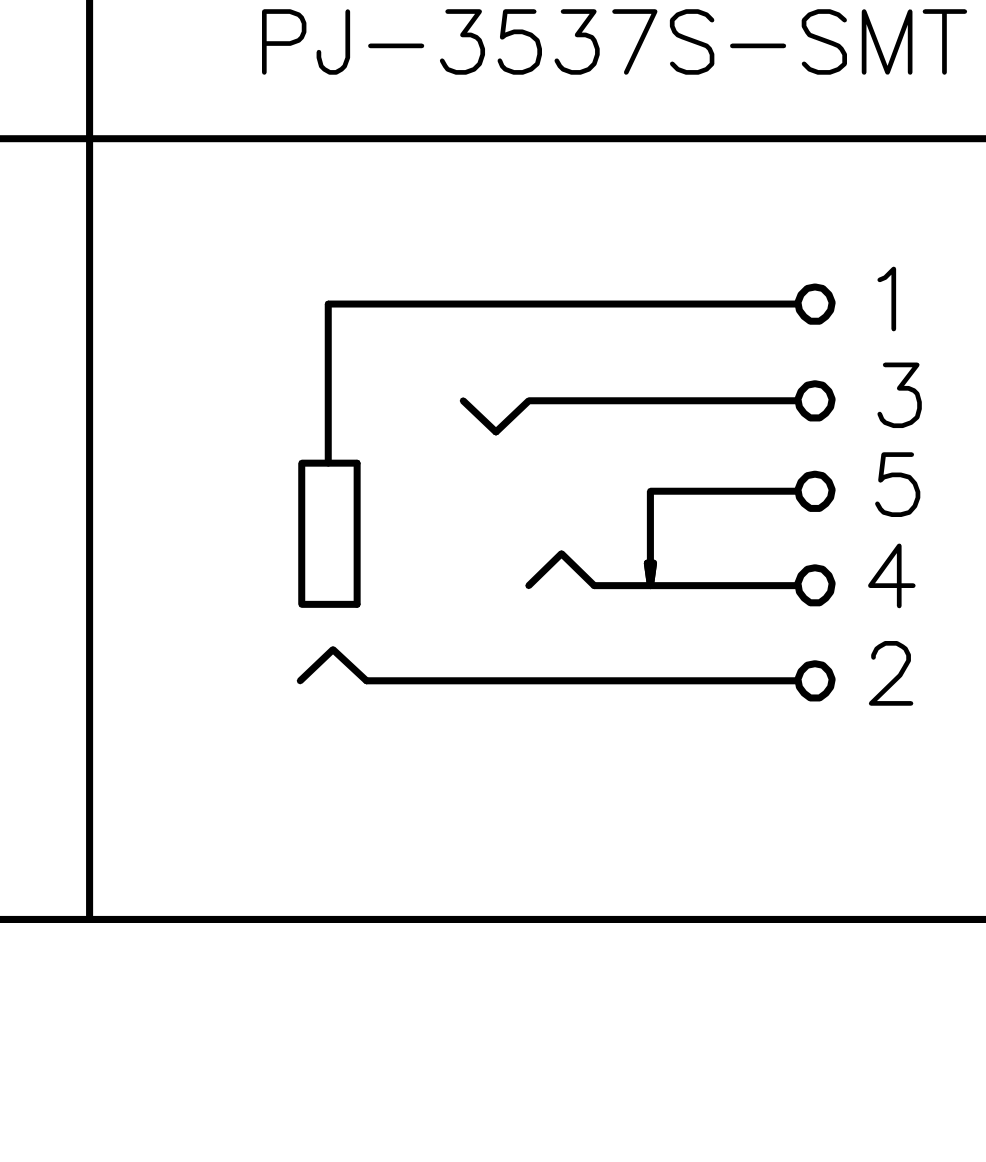
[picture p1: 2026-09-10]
hw/datasheets/schem_hi.png

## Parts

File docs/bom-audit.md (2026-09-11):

# BOM Audit & Cost — bluetooth-audio

**Date:** 2026-09-11 · **Scope:** power, audio, micro sheets · **Sourcing target:** JLCPCB / LCSC

Full footprint + part-number sanity check of the schematic BOM, the corrections applied, the
resulting priced BOM, and the open decisions. Every LCSC code was validated against the local
jlcparts snapshot (CH340K against jlcpcb.com).

## 1. Result summary

- **137 components** audited. Every non-testpoint / non-antenna part carries a consistent
  **Manufacturer + MPN + LCSC** field set. Post-edit verification: no missing LCSC/Manufacturer/MPN,
  no stale `Supplier Part Number` fields.
- Custom parts resolve from the **`kicad-library` git submodule** (`hw/bluetooth-audio/kicad-library`)
  via project-level lib tables using `${KIPRJMOD}` — the project is self-contained on a fresh
  `git clone --recurse-submodules`.
- A **Basic-parts pass** (below) cut JLCPCB Extended parts from 25 → **20** ($75 → $60 one-time).

## 2. Corrections applied

### 2.1 Critical — `C1849` mis-assignment (14 caps)
`C1849` (a 10 µF 16 V 1206 MLCC) had been pasted as a placeholder onto 14 capacitors of
unrelated values (1 µF, 4.7 µF, 47 µF, 4.7 nF, 100 nF, **18 pF crystal load**), several in the
wrong package. All reassigned to the correct part; stale supplier field cleared.

### 2.2 D1 LED
Originally `LED_BLUE` fitted with a **white** LED (`C34499`). Corrected to blue (`C2293`), then —
in the Basic-parts pass — changed to **white (`C34499`, Basic)** since no blue LED is a JLCPCB
Basic part (value relabelled `LED_WHITE`). *The GPIO net is still named `LED_BLUE`; rename in
firmware/schematic if desired. Pick green/yellow instead of white if you prefer — both are Basic.*

### 2.3 Missing passive PNs populated
All resistors, caps and L1 given JLCPCB parts — Basic where available. Dielectric chosen
deliberately: **C0G** for the 18 pF crystal-load caps (C35/C36) and the 3.3 pF RF-match caps
(C37/C38); **C0G preserved** on the audio 100 nF (C41/C42, `C97946`); X7R/X5R for decoupling.

### 2.4 Part / footprint changes
| Ref | Change | Part |
|-----|---|---|
| C48 | 47 µF SYS bulk: MLCC → **tantalum** (footprint `CP_EIA-3528-21_Kemet-B`) | `C22036` Kyocera AVX |
| C27 | 10 µF footprint **0402 → 0603** | `C19702` |
| C51 | USB-shield 4.7 nF: **1206 → 0402**, now **Basic** (generic filter) | `C1538` |
| R_TMR1 / R_ISET1 / R_ITERM1 | charger 56 k / 1.2 k / 3 k: **0402 → 0603** to get **Basic** at the *same values* (charger programming unchanged) | `C23206` / `C22765` / `C4211` |
| U3  | footprint **TSSOP-10 → MSOP-10** (DGS = VSSOP, no pad) | `C42751` |
| Q2  | PN added | `C15127` (Basic) |
| J2  | PN added | `C5143397` GCT USB4110-GF-A |
| J5  | Molex → **JST-PH 3-pin** battery connector | `C157929` JST S3B-PH-K-S |
| D6  | LED_CHG → **amber** | `C2296` |
| U9  | **DNP** (charger not populated) | `C54313` (kept for reference) |

### 2.5 Field normalisation
All ICs/LEDs/discretes migrated from `Supplier Part Number` to `LCSC` + `Manufacturer` + `MPN`
(incl. secondary units of multi-unit symbols D7/D8/Q1).

## 3. MLCC review (power rail)

Roles from the PCB netlist: C47 = VBUS input; C2/C3/C5 = SYS & LDO inputs; **C48 = +V_SYS bulk,
C49 = +BATT bulk**; C4/C20/C50 = 3V3 rails; C51 = USB-shield Y-cap; C52/C53 = ADC / VBUS-sense.

- **Decoupling + all three regulators → MLCC is correct** (low-ESR ceramic by design). Using 1206
  for the rail caps already limits DC-bias loss (50 V parts selected).
- **C48 (SYS bulk) → 47 µF/10 V tantalum** (`C22036`): a 10 V X5R 47 µF 1206 on a 3.0–4.4 V rail
  gives only ~50–65 % of nameplate under bias; the tantalum holds value.
- **C49 (+BATT bulk) left as MLCC** — revisit if battery-node hold-up matters.

## 4. Priced BOM (assembled parts; DNP excluded)

Unit price at the 100-board tier. Lib = JLCPCB Basic (free feeder) vs Extended ($3 one-time each).

| Qty | Value | Refs | Footprint | Manufacturer | MPN | LCSC | Lib | Unit(100) |
|----:|---|---|---|---|-----|---|-----|---:|
| 14 | 100nF | C9,C10,C11,C12,C13,C16,C18,C19,C28,C30,C32,C33,C43,C46 | C_0402_1005Metric | Samsung Electro Mechanics | CL05B104KO5NNNC | C1525 | Basic | $0.0051 |
| 10 | 100k | R17,R22,R23,R30,R31,R34,R35,R38,R39,R40 | R_0402_1005Metric | UNI ROYAL Uniroyal Elec | 0402WGF1003TCE | C25741 | Basic | $0.0033 |
| 8 | 10u | C8,C14,C15,C17,C27,C29,C31,C44 | C_0603_1608Metric | Samsung Electro Mechanics | CL10A106KP8NNNC | C19702 | Basic | $0.0723 |
| 6 | 1k | R19,R20,R32,R33,R36,R37 | R_0402_1005Metric | UNI ROYAL Uniroyal Elec | 0402WGF1001TCE | C11702 | Basic | $0.0011 |
| 6 | 10R | R7,R8,R9,R10,R16,R21 | R_0402_1005Metric | UNI ROYAL Uniroyal Elec | 0402WGF100JTCE | C25077 | Basic | $0.0009 |
| 6 | 330R | R6,R12,R15,R18,R28,R29 | R_0402_1005Metric | UNI ROYAL Uniroyal Elec | 0402WGF3300TCE | C25104 | Basic | $0.0012 |
| 5 | 1uF | C6,C7,C24,C26,C34 | C_0402_1005Metric | Samsung Electro Mechanics | CL05A105KA5NQNC | C52923 | Basic | $0.0122 |
| 4 | LED_PGOOD | D2,D3,D4,D5 | LED_0805_2012Metric | Hubei KENTO Elec | KT-0805G | C2297 | Basic | $0.0163 |
| 4 | 10k | R1,R2,R11,R27 | R_0402_1005Metric | UNI ROYAL Uniroyal Elec | 0402WGF1002TCE | C25744 | Basic | $0.0029 |
| 3 | 10uF | C5,C47,C50 | C_1206_3216Metric | Samsung Electro Mechanics | CL31A106KBHNNNE | C13585 | Basic | $0.1622 |
| 2 | 18pF | C35,C36 | C_0402_1005Metric | FH Guangdong Fenghua Advanced Tech | 0402CG180J500NT | C1549 | Basic | $0.0023 |
| 2 | 4.7uF | C4,C22 | C_0603_1608Metric | Samsung Electro Mechanics | CL10A475KO8NNNC | C19666 | Basic | $0.0209 |
| 2 | 100nF | C52,C53 | C_1206_3216Metric | Samsung Electro Mechanics | CL31B104KBCNNNC | C24497 | Basic | $0.0188 |
| 2 | 4k7 | R24,R25 | R_0402_1005Metric | UNI ROYAL Uniroyal Elec | 0402WGF4701TCE | C25900 | Basic | $0.0011 |
| 2 | 5k1 | R4,R5 | R_0402_1005Metric | UNI ROYAL Uniroyal Elec | 0402WGF5101TCE | C25905 | Basic | $0.0009 |
| 2 | 47uF | C1,C21 | CP_Elec_5x5.8 | PANASONIC | EEEFT1E470AR | C336270 | Ext | $0.3106 |
| 2 | D_Schottky_Dual_Series_AKC_Split | D7,D8 | SOT-23 | MDD Microdiode Semiconductor | BAT54S | C408389 | Ext | $0.0137 |
| 2 | 3.3pF | C37,C38 | C_0402_1005Metric | Murata Electronics | GJM1555C1H3R3BB01D | C76906 | Ext | $0.0318 |
| 2 | 100nF | C41,C42 | C_1206_3216Metric_Pad1.33x1.80mm_HandSolder | Murata Electronics | GRM31C5C1H104JA01L | C97946 | Ext | $0.1513 |
| 1 | AO3401A | Q2 | SOT-23 | Alpha Omega Semicon | AO3401A | C15127 | Basic | $0.0596 |
| 1 | 10nF | C45 | C_0402_1005Metric | Samsung Electro Mechanics | CL05B103KB5NNNC | C15195 | Basic | $0.0035 |
| 1 | 4.7nF | C51 | C_0402_1005Metric | FH Guangdong Fenghua Advanced Tech | 0402B472K500NT | C1538 | Basic | $0.0042 |
| 1 | Conn_01x03 | J5 | JST_PH_S3B-PH-K_1x03_P2.00mm_Horizontal | JST | S3B-PH-K-S(LF)(SN) | C157929 | Ext | $0.0402 |
| 1 | 1uF | C20 | C_0603_1608Metric | Samsung Electro Mechanics | CL10A105KB8NNNC | C15849 | Basic | $0.0297 |
| 1 | 0R | R13 | R_0402_1005Metric | UNI ROYAL Uniroyal Elec | 0402WGF0000TCE | C17168 | Basic | $0.0011 |
| 1 | 1uF | C2 | C_1206_3216Metric | Samsung Electro Mechanics | CL31B105KBHNNNE | C1848 | Basic | $0.0414 |
| 1 | 47uF | C48 | CP_EIA-3528-21_Kemet-B | Kyocera AVX | TAJB476K010RNJ | C22036 | Ext | $0.1847 |
| 1 | 1k2 | R_ISET1 | R_0603_1608Metric | UNI ROYAL Uniroyal Elec | 0603WAF1201T5E | C22765 | Basic | $0.0015 |
| 1 | LED_CHG | D6 | LED_0805_2012Metric | Hubei KENTO Elec | KT-0805Y | C2296 | Basic | $0.0153 |
| 1 | 56k | R_TMR1 | R_0603_1608Metric | UNI ROYAL Uniroyal Elec | 0603WAF5602T5E | C23206 | Basic | $0.0020 |
| 1 | Crystal 40 MHz 10pF | Y1 | Crystal_SMD_SeikoEpson_FA128-4Pin_2.0x1.6mm | Seiko Epson | Q22FA12800101 | C255898 | Ext | $0.2268 |
| 1 | 1k5 | R_ILIM1 | R_0402_1005Metric | UNI ROYAL Uniroyal Elec | 0402WGF1501TCE | C25867 | Basic | $0.0011 |
| 1 | PJ-3537S-SMT | J1 | PJ-3537S-SMT | XKB Connection | PJ-3537S-SMT | C2689709 | Ext | $0.2473 |
| 1 | 4.7uF | C3 | C_1206_3216Metric | FH Guangdong Fenghua Advanced Tech | 1206B475K500NT | C29823 | Basic | $0.0998 |
| 1 | LED_WHITE | D1 | LED_0805_2012Metric | Hubei KENTO Elec | KT-0805W | C34499 | Basic | $0.0202 |
| 1 | ES8388 | U4 | QFN-28-1EP_4x4mm_P0.4mm_EP2.3x2.3mm | Everest Semiconductor | ES8388 | C365736 | Ext | $0.7110 |
| 1 | 3k | R_ITERM1 | R_0603_1608Metric | UNI ROYAL Uniroyal Elec | 0603WAF3001T5E | C4211 | Basic | $0.0014 |
| 1 | TS5A23159DGS | U3 | MSOP-10_3x3mm_P0.5mm | Texas Instruments | TS5A23159DGSR | C42751 | Ext | $0.3531 |
| 1 | AP7361C-33Y5 | U7 | SOT-89-5 | Diodes Incorporated | AP7361C-33Y5-13 | C460397 | Ext | $0.2460 |
| 1 | ZTS6216 | MK1 | ZTS6216 | ZILLTEK | ZTS6216 | C481302 | Ext | $0.4572 |
| 1 | USB_C_Receptacle_USB2.0 | J2 | USB_C_Receptacle_GCT_USB4110 | Global Connector Technology | USB4110-GF-A | C5143397 | Ext | $0.8737 |
| 1 | W25Q32JVZP | U6 | WSON-8-1EP_6x5mm_P1.27mm_EP3.4x4.3mm | Winbond Elec | W25Q32JVZPIQ | C571260 | Ext | $1.3211 |
| 1 | UMH3N | Q1 | SOT-363_SC-70-6 | Jiangsu Changjing Electronics | UMH3N | C62892 | Ext | $0.0438 |
| 1 | USBLC6-2SC6 | U5 | SOT-23-6 | STMicroelectronics | USBLC6-2SC6 | C7519 | Ext | $0.1287 |
| 1 | LP5907MFX-3.3 | U11 | SOT-23-5 | Texas Instruments | LP5907MFX-3.3/NOPB | C80670 | Ext | $0.1102 |
| 1 | 2.2nH | L1 | L_0402_1005Metric | Murata Electronics | LQG15HS2N2S02D | C86061 | Ext | $0.0191 |
| 1 | ESP32D0WD-V3 | U1 | QFN-48-1EP_5x5mm_P0.35mm_EP3.7x3.7mm_ThermalVias | Espressif Systems | ESP32-D0WD-V3 | C967021 | Ext | $2.0515 |
| 1 | CH340K | U2 | SSOP-10-1EP_3.9x4.9mm_P1mm_EP2.1x3.3mm | WCH(Jiangsu Qin Heng) | CH340K | C968586 | Ext | $0.3200 |
*Also on the board but **DNP** (not assembled): U9 (BQ24074 charger), C54, R3/R14/R41 (0 Ω options), R26, R_NTC_LIN1, J3 (prog header), J4 (JTAG pads). ANT1 is a PCB trace antenna. Test points TPx carry no part.*

## 5. Cost

**Component (parts) cost** — from live LCSC tier pricing, DNP excluded, 113 SMT placements/board:

| Boards | Parts cost (order) | Per board | Extended-part setup (one-time) |
|---:|---:|---:|---:|
| 5 | \$66.49 | **\$13.30** | 20 × \$3 = \$60 |
| 30  | \$337.24 | **\$11.24** | \$60 |
| 100 | \$1,004.44 | **\$10.04** | \$60 |

**Main cost drivers / board:** U1 ESP32 \$2.05 · U6 W25Q32 \$1.32 · J2 USB-C (GCT) \$0.87 ·
U4 ES8388 \$0.71 · MK1 mic \$0.46 · 3× 10 µF 1206 \$0.49 · 2× 47 µF elec \$0.62.

**Not included:** BQ24074 charger (DNP — ~\$1.6–2.0/board if populated); battery (off-board,
~\$8–12); PCB fabrication + SMT assembly labour (needs final board dimensions — the `.kicad_pcb`
is stale vs the current schematic).

**Remaining cost-reduction options (optional):**
- **U6** `W25Q32JVZPIQ` (WSON, \$1.32) → `W25Q32JVSSIQ` SOIC-8 / plain W25Q32 (~\$0.30) ≈ −\$1/board.
- **J2** GCT USB4110 (\$0.87) → a JLCPCB-Basic USB-C (~\$0.15) ≈ −\$0.7/board (GCT is more robust).
- **Q1** UMH3N (Extended) — see open items.

## 6. Open items / decisions

1. **Q1 (UMH3N) is the last easily-removable Extended part, but has no Basic drop-in.** There is no
   Basic dual (or single) pre-biased digital transistor at JLCPCB. It is the CH340 auto-reset/boot
   circuit (RTS/DTR → EN/GPIO0). Options: **(a) keep UMH3N Extended** (\$3, proven — recommended), or
   **(b) redesign to 2× MMBT3904 (Basic, `C20526`) + external base resistors** — a change to the
   boot/programming path that needs care and re-verification. Not done pending your call.
2. **C37/C38 (RF antenna-match, 3.3 pF NP0) stay Extended** — no Basic 3.3 pF exists and RF match
   should stay NP0. (The actual crystal-load caps are C35/C36, already Basic C0G.)
3. **Battery (off-board):** removable Li-ion ≥1000 mAh, 3-wire JST-PH (BAT+/NTC/BAT−) with a 10 kΩ
   NTC for the BQ24074 TS pin (e.g. LP504050-class 1200 mAh with PCM + NTC). Confirm NTC β vs R_NTC.
4. **U9 = DNP** disables on-board charging — confirm intended.
5. **PCB is stale** vs the revised schematic (duplicate refs, a `+1V8` net) — re-sync
   schematic → PCB before fab; board dimensions needed to complete a full fab+assembly quote.

*Component pricing from the local jlcparts snapshot; verify live stock/price at order time.*

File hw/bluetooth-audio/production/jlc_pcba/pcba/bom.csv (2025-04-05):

Designator | Footprint | Quantity | Value | JLCPCB Part #
ANT1 | custom_footprints:Antenna 2.4GHz Inverted-F Meandered | 1 | 2.4 GHz
C1 | Capacitor_SMD:C_1206_3216Metric | 1 | 1uF | C1849
C2 | Capacitor_SMD:C_0603_1608Metric | 1 | 1uF | C1849
C3 | Capacitor_SMD:C_1206_3216Metric | 1 | 10uF | C1849
C4 | Capacitor_SMD:C_0603_1608Metric | 1 | 1uF | C1849
C5 | Capacitor_SMD:C_0603_1608Metric | 1 | 1uF | C1849
C6 | Capacitor_SMD:C_0402_1005Metric | 1 | 1uF | C1849
C7 | Capacitor_SMD:C_0402_1005Metric | 1 | 1uF | C1849
C8 | Capacitor_SMD:C_0603_1608Metric | 1 | 10uF | C1849
C9 | Capacitor_SMD:C_0402_1005Metric | 1 | 100nF
C10 | Capacitor_SMD:C_0402_1005Metric | 1 | 100nF
C11 | Capacitor_SMD:C_0402_1005Metric | 1 | 100nF
C12 | Capacitor_SMD:C_0402_1005Metric | 1 | 100nF
C13 | Capacitor_SMD:C_0402_1005Metric | 1 | 100nF
C14 | Capacitor_SMD:C_0603_1608Metric | 1 | 10u
C15 | Capacitor_SMD:C_0603_1608Metric | 1 | 10u
C16 | Capacitor_SMD:C_0402_1005Metric | 1 | 100nF
C17 | Capacitor_SMD:C_0603_1608Metric | 1 | 10u
C18 | Capacitor_SMD:C_0402_1005Metric | 1 | 100nF
C19 | Capacitor_SMD:C_0402_1005Metric | 1 | 100nF
C21 | Capacitor_SMD:C_0402_1005Metric | 1 | 1uF
C22 | Capacitor_SMD:C_0402_1005Metric | 1 | 1uF
C23 | Capacitor_SMD:C_0402_1005Metric | 1 | 1uF
C24 | Capacitor_SMD:C_0402_1005Metric | 1 | 1uF
C25 | Capacitor_SMD:C_0402_1005Metric | 1 | 1uF
C26 | Capacitor_SMD:C_0402_1005Metric | 1 | 1uF
C27 | Capacitor_SMD:C_0402_1005Metric | 1 | 10u
C28 | Capacitor_SMD:C_0402_1005Metric | 1 | 100nF
C29 | Capacitor_SMD:C_0603_1608Metric | 1 | 10u
C30 | Capacitor_SMD:C_0402_1005Metric | 1 | 100nF
C31 | Capacitor_SMD:C_0603_1608Metric | 1 | 10u
C32 | Capacitor_SMD:C_0402_1005Metric | 1 | 100nF
C33 | Capacitor_SMD:C_0402_1005Metric | 1 | 100nF
C34 | Capacitor_SMD:C_0402_1005Metric | 1 | 1uF | C1849
C35 | Capacitor_SMD:C_0402_1005Metric | 1 | 18pF | C1849
C36 | Capacitor_SMD:C_0402_1005Metric | 1 | 18pF
C37 | Capacitor_SMD:C_0402_1005Metric | 1 | 3.3pF
C38 | Capacitor_SMD:C_0402_1005Metric | 1 | 3.3pF
C39 | Capacitor_SMD:C_0402_1005Metric | 1 | 10nF
C40 | Capacitor_SMD:C_0402_1005Metric | 1 | 10nF
C41 | Capacitor_SMD:C_0402_1005Metric | 1 | 100nF
C42 | Capacitor_SMD:C_0402_1005Metric | 1 | 100nF
C43 | Capacitor_SMD:C_0402_1005Metric | 1 | 100nF
C44 | Capacitor_SMD:C_0603_1608Metric | 1 | 10u
D1 | LED_SMD:LED_0805_2012Metric | 1 | LED_BLUE | C34499
D2 | LED_SMD:LED_0805_2012Metric | 1 | LED_3V3 | C2297
D3 | LED_SMD:LED_0805_2012Metric | 1 | LED_GREEN | C2297
J1 | Connector_Audio:Jack_3.5mm_KoreanHropartsElec_PJ-320D-4A_Horizontal | 1 | AudioJack4_Ground | C95562
J2 | Connector_USB:USB_C_Receptacle_GCT_USB4110 | 1 | USB_C_Receptacle_USB2.0
L1 | Inductor_SMD:L_0402_1005Metric | 1 | 2.2nH
MK1 | custom_footprints:ICS40720 | 1 | ICS-40720 | C3171779
Q1 | Package_TO_SOT_SMD:SOT-363_SC-70-6 | 1 | UMH3N | C62892
R1 | Resistor_SMD:R_0402_1005Metric | 1 | 10k
R2 | Resistor_SMD:R_0402_1005Metric | 1 | 10k
R4 | Resistor_SMD:R_0402_1005Metric | 1 | 5k1
R5 | Resistor_SMD:R_0402_1005Metric | 1 | 5k1
R6 | Resistor_SMD:R_0402_1005Metric | 1 | 1k
R7 | Resistor_SMD:R_0402_1005Metric | 1 | 10R
R8 | Resistor_SMD:R_0402_1005Metric | 1 | 10R
R9 | Resistor_SMD:R_0402_1005Metric | 1 | 10R
R10 | Resistor_SMD:R_0402_1005Metric | 1 | 10R
R11 | Resistor_SMD:R_0402_1005Metric | 1 | 10k
R12 | Resistor_SMD:R_0402_1005Metric | 1 | 1k
R13 | Resistor_SMD:R_0402_1005Metric | 1 | 0R
R18 | Resistor_SMD:R_0402_1005Metric | 1 | 1k
R19 | Resistor_SMD:R_0402_1005Metric | 1 | 4k7
R20 | Resistor_SMD:R_0402_1005Metric | 1 | 4k7
R21 | Resistor_SMD:R_0402_1005Metric | 1 | 2k2
R22 | Resistor_SMD:R_0402_1005Metric | 1 | 2k2
R23 | Resistor_SMD:R_0402_1005Metric | 1 | 1k
R24 | Resistor_SMD:R_0402_1005Metric | 1 | 4k7
R25 | Resistor_SMD:R_0402_1005Metric | 1 | 4k7
TP1 | custom_footprints:TestPoint_Pad_2x1_D1.0mm | 1 | TEST_EN
TP2 | TestPoint:TestPoint_Pad_D1.0mm | 1 | TEST_3V3
TP3 | custom_footprints:TestPoint_Pad_2x1_D1.0mm | 1 | TEST_BOOT
TP4 | TestPoint:TestPoint_Pad_D1.0mm | 1 | TEST_GPIO2
TP5 | custom_footprints:TestPoint_Pad_2x1_D1.0mm | 1 | TEST_IN_2
TP6 | custom_footprints:TestPoint_Pad_2x1_D1.0mm | 1 | TEST_OUT_2
TP7 | custom_footprints:TestPoint_Pad_2x1_D1.0mm | 1 | TEST_MIC_1
TP8 | TestPoint:TestPoint_Pad_D1.0mm | 1 | TEST_I2C_DATA
TP9 | TestPoint:TestPoint_Pad_D1.0mm | 1 | TEST_VDD_SDIO
TP10 | TestPoint:TestPoint_Pad_D1.0mm | 1 | TEST_GND
TP11 | TestPoint:TestPoint_Pad_D1.0mm | 1 | TEST_GND
TP12 | TestPoint:TestPoint_Pad_D1.0mm | 1 | TEST_GND
TP13 | TestPoint:TestPoint_Pad_D1.0mm | 1 | TEST_1V8
TP14 | TestPoint:TestPoint_Pad_D1.0mm | 1 | TEST_I2C_AD
TP15 | TestPoint:TestPoint_Pad_D1.0mm | 1 | TEST_I2C_CLK
U1 | Package_DFN_QFN:QFN-48-1EP_5x5mm_P0.35mm_EP3.7x3.7mm_ThermalVias | 1 | ESP32D0WD-V3 | C967021
U2 | Package_SO:SSOP-10-1EP_3.9x4.9mm_P1mm_EP2.1x3.3mm | 1 | CH340K | C968586
U3 | Package_TO_SOT_SMD:SOT-23-5 | 1 | TLV71318PDBV | C2869099
U4 | Package_DFN_QFN:QFN-28-1EP_4x4mm_P0.4mm_EP2.3x2.3mm | 1 | ES8388 | C365736
U5 | Package_TO_SOT_SMD:SOT-23-6 | 1 | USBLC6-2SC6 | C7519
U6 | Package_SON:WSON-8-1EP_6x5mm_P1.27mm_EP3.4x4.3mm | 1 | W25Q32JVZP | C571260
U7 | Package_TO_SOT_SMD:SOT-223-3_TabPin2 | 1 | NCP1117-3.3_SOT223 | C26537
Y1 | Crystal:Crystal_SMD_SeikoEpson_FA128-4Pin_2.0x1.6mm | 1 | Crystal 40 MHz 10pF | C255898

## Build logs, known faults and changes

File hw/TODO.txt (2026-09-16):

Dual power path management - current limit decisions
3v3 regulator - use correct 5 pin step file
Choose molex footprint for battery connector
Fix JLCPCB kicad mcp database (battery connector chat)
Update design overview (change this to a pre-push hook?)

Change to basic parts:
C37,C38 - crystal load. Don't need to be C0G
c51 - this is just for ground loop filtering. can be generic
Blue LED - find a basic part, or change to a colour that can be in basic
R_TMR1, R_ISET1, R_ITERM1 - find basic parts. 
Q1 - find basic, or replace with 2x basic individual BJTs

R_ISET1, R_ITERM, R_TMR change to 0402
\
DONE
------------------------------------------------

C53 can be 0603. Doesn't need to be 1206
Does the 10R audio VDD join resistor need to be a bigger package?
Change caps for C26, C24 to electrolytic

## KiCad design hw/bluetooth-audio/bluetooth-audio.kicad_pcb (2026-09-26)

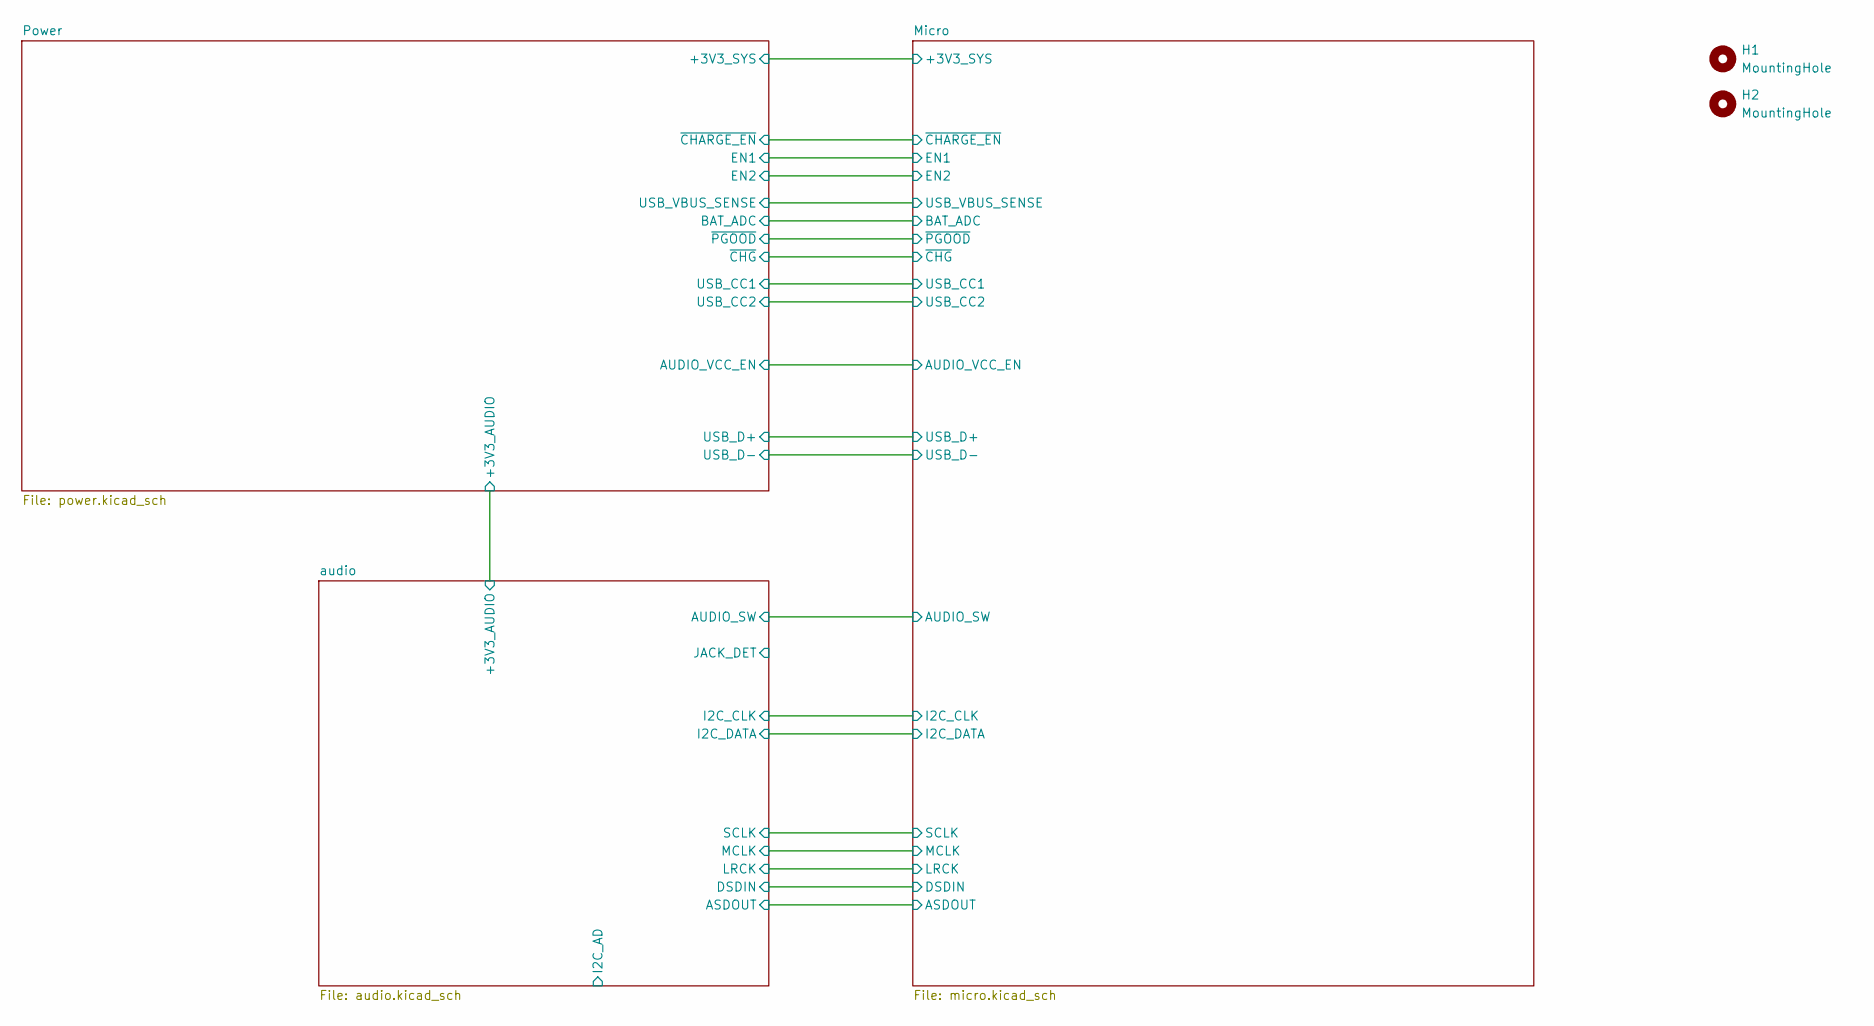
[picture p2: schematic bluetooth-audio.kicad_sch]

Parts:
H1, H2: MountingHole; MountingHole_2.2mm_M2_DIN965_Pad

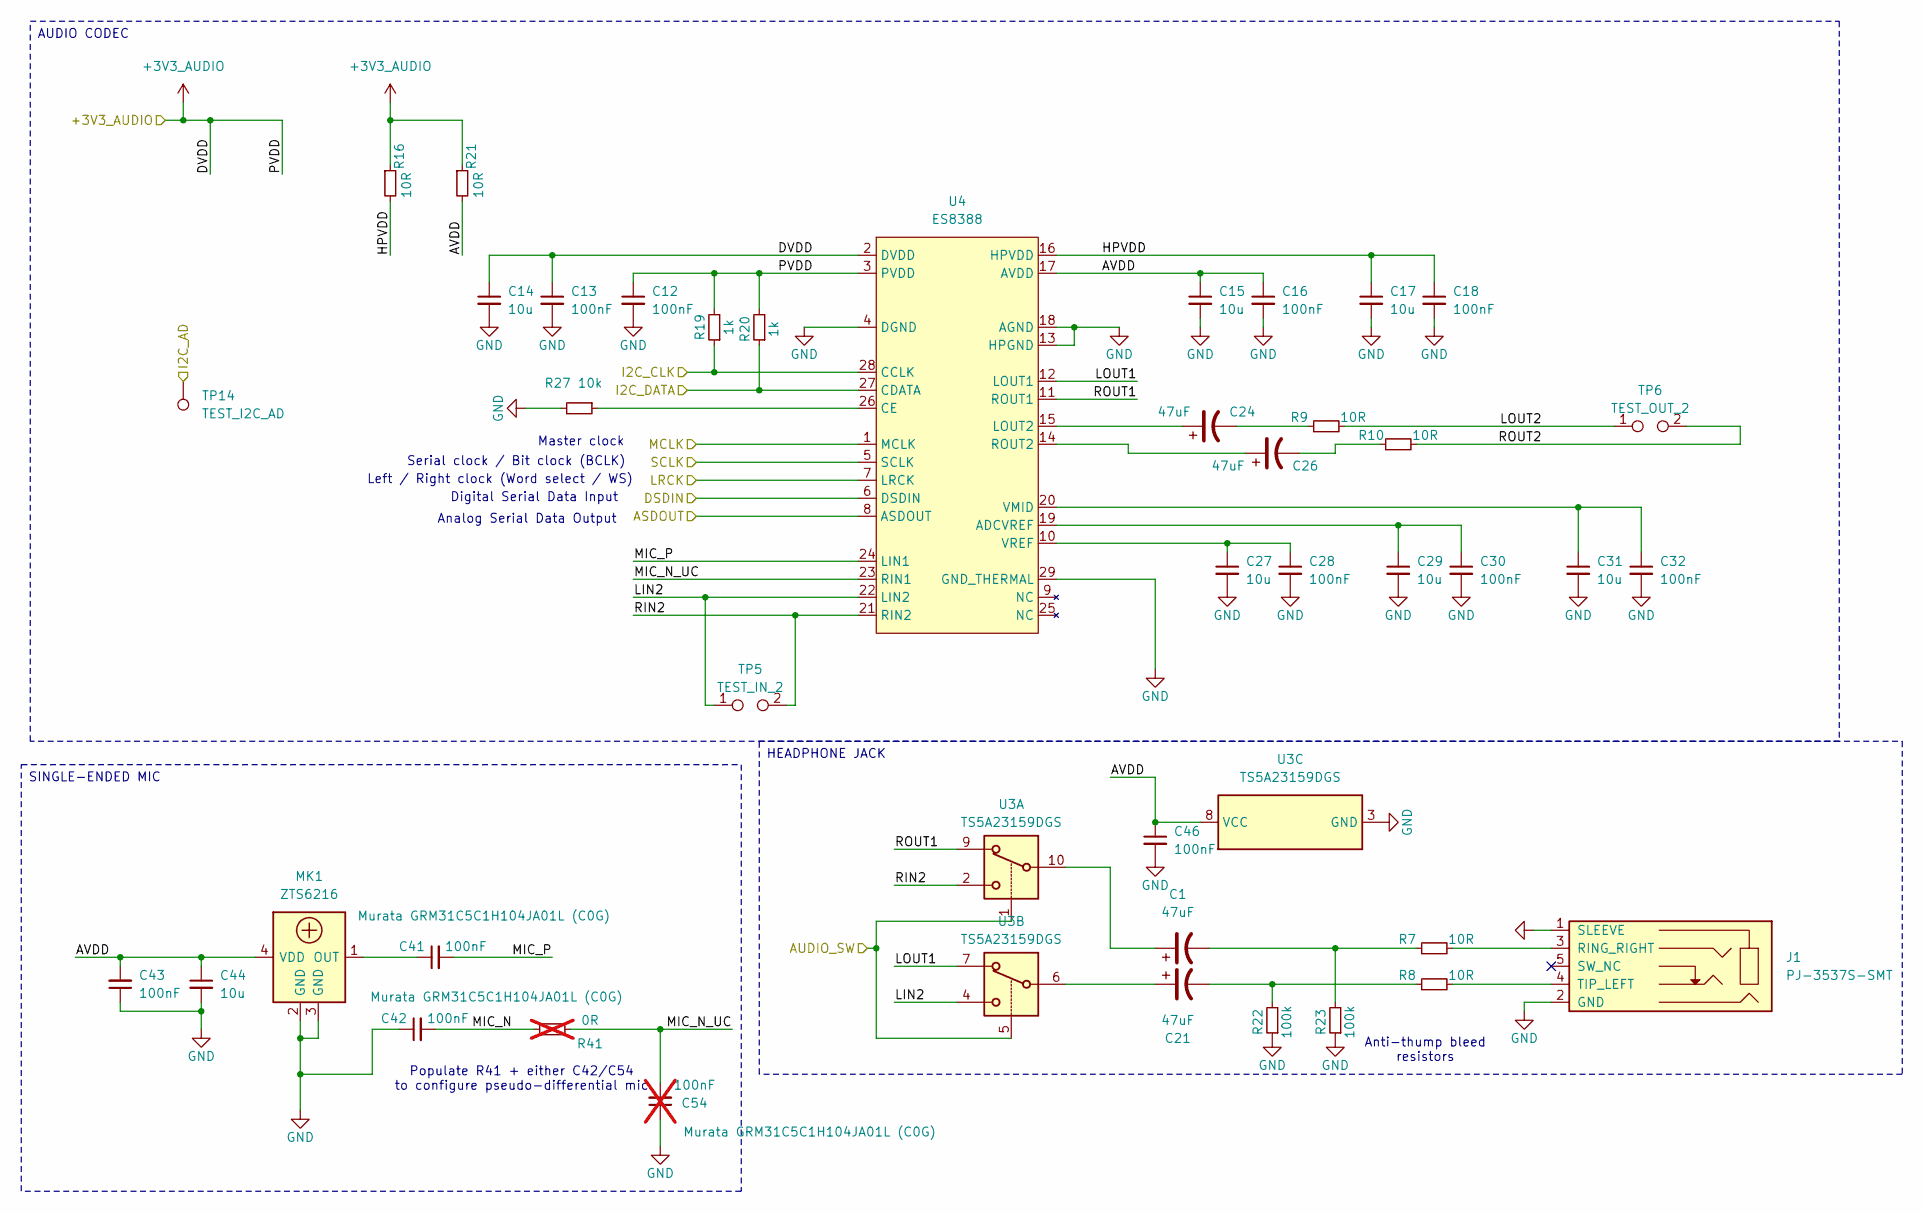
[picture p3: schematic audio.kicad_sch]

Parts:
C1, C21, C24, C26: 47uF; CP_Elec_5x5.8; MPN EEEFT1E470AR; LCSC C336270
C12, C13, C16, C18, C28, C30, C32, C43, C46: 100nF; C_0402_1005Metric; MPN CL05B104KO5NNNC; LCSC C1525
C14, C15, C17, C27, C29, C31, C44: 10u; C_0603_1608Metric; MPN CL10A106KP8NNNC; LCSC C19702
C41, C42: 100nF; C_1206_3216Metric; MPN GRM31C5C1H104JA01L; LCSC C97946
C54: 100nF; C_1206_3216Metric; MPN GRM31C5C1H104JA01L; LCSC C97946; not fitted
J1: PJ-3537S-SMT; MPN PJ-3537S-SMT; LCSC C2689709
MK1: ZTS6216; MPN ZTS6216; LCSC C481302
R7, R8, R9, R10, R16, R21: 10R; R_0402_1005Metric; MPN 0402WGF100JTCE; LCSC C25077
R19, R20: 1k; R_0402_1005Metric; MPN 0402WGF1001TCE; LCSC C11702
R22, R23: 100k; R_0402_1005Metric; MPN 0402WGF1003TCE; LCSC C25741
R27: 10k; R_0402_1005Metric; MPN 0402WGF1002TCE; LCSC C25744
R41: 0R; R_0402_1005Metric; MPN 0402WGF0000TCE; LCSC C17168; not fitted
TP5: TEST_IN_2; TestPoint_Pad_2x1_D1.0mm
TP6: TEST_OUT_2; TestPoint_Pad_2x1_D1.0mm
TP14: TEST_I2C_AD; TestPoint_Pad_D1.0mm
U3: TS5A23159DGS; MSOP-10_3x3mm_P0.5mm; MPN TS5A23159DGSR; LCSC C42751
U4: ES8388; QFN-28-1EP_4x4mm_P0.4mm_EP2.3x2.3mm; MPN ES8388; LCSC C365736

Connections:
+3V3_AUDIO: C12.1, C13.1, C14.1, R16.1, R19.2, R20.2, R21.1, U4.2 (DVDD), U4.3 (PVDD); also elsewhere on the board
/Micro/ASDOUT: U4.8 (ASDOUT); also elsewhere on the board
/Micro/AUDIO_SW: U3.1, U3.5; also elsewhere on the board
/Micro/DSDIN: U4.6 (DSDIN); also elsewhere on the board
/Micro/GPIO_0: U4.1 (MCLK); also elsewhere on the board
/Micro/I2C_CLK: R19.1, U4.28 (CCLK); also elsewhere on the board
/Micro/I2C_DATA: R20.1, U4.27 (CDATA); also elsewhere on the board
/Micro/LRCK: U4.7 (LRCK); also elsewhere on the board
/Micro/SCLK: U4.5 (SCLK); also elsewhere on the board
/audio/AVDD: C15.1, C16.1, C43.2, C44.1, C46.1, MK1.4 (VDD), R21.2, U3.8 (VCC), U4.17 (AVDD)
/audio/HPVDD: C17.1, C18.1, R16.2, U4.16 (HPVDD)
/audio/LIN2: TP5.1, U3.4, U4.22 (LIN2)
/audio/LOUT1: U3.7, U4.12 (LOUT1)
/audio/LOUT2: R9.2, TP6.1
/audio/MIC_N: C42.2, R41.1
/audio/MIC_N_UC: C54.2, R41.2, U4.23 (RIN1)
/audio/MIC_P: C41.2, U4.24 (LIN1)
/audio/RIN2: TP5.2, U3.2, U4.21 (RIN2)
/audio/ROUT1: U3.9, U4.11 (ROUT1)
/audio/ROUT2: R10.2, TP6.2
GND: C12.2, C13.2, C14.2, C15.2, C16.2, C17.2, C18.2, C27.2, C28.2, C29.2, C30.2, C31.2, C32.2, C42.1, C43.1, C44.2, C46.2, C54.1, J1.1 (SLEEVE), J1.2 (GND), MK1.2 (GND), MK1.3 (GND), R22.1, R23.1, R27.2, U3.3 (GND), U4.4 (DGND), U4.13 (HPGND), U4.18 (AGND), U4.29 (GND_THERMAL); also elsewhere on the board
unnamed: C1.1, U3.10
unnamed: C1.2, R7.1, R23.2
unnamed: C21.1, U3.6
unnamed: C21.2, R8.1, R22.2
unnamed: C24.2, R9.1
unnamed: C26.2, R10.1
unnamed: J1.3 (RING_RIGHT), R7.2
unnamed: J1.4 (TIP_LEFT), R8.2
unnamed: C41.1, MK1.1 (OUT)
unnamed: C29.1, C30.1, U4.19 (ADCVREF)
unnamed: R27.1, U4.26 (CE)
unnamed: C24.1, U4.15 (LOUT2)
unnamed: C26.1, U4.14 (ROUT2)
unnamed: C31.1, C32.1, U4.20 (VMID)
unnamed: C27.1, C28.1, U4.10 (VREF)

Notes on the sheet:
Anti-thump bleed resistors
Digital Serial Data Input
Left / Right clock (Word select / WS)
Populate R41 + either C42/C54 to configure pseudo-differential mic
Analog Serial Data Output
Master clock
Serial clock / Bit clock (BCLK)
SINGLE-ENDED MIC
HEADPHONE JACK
AUDIO CODEC

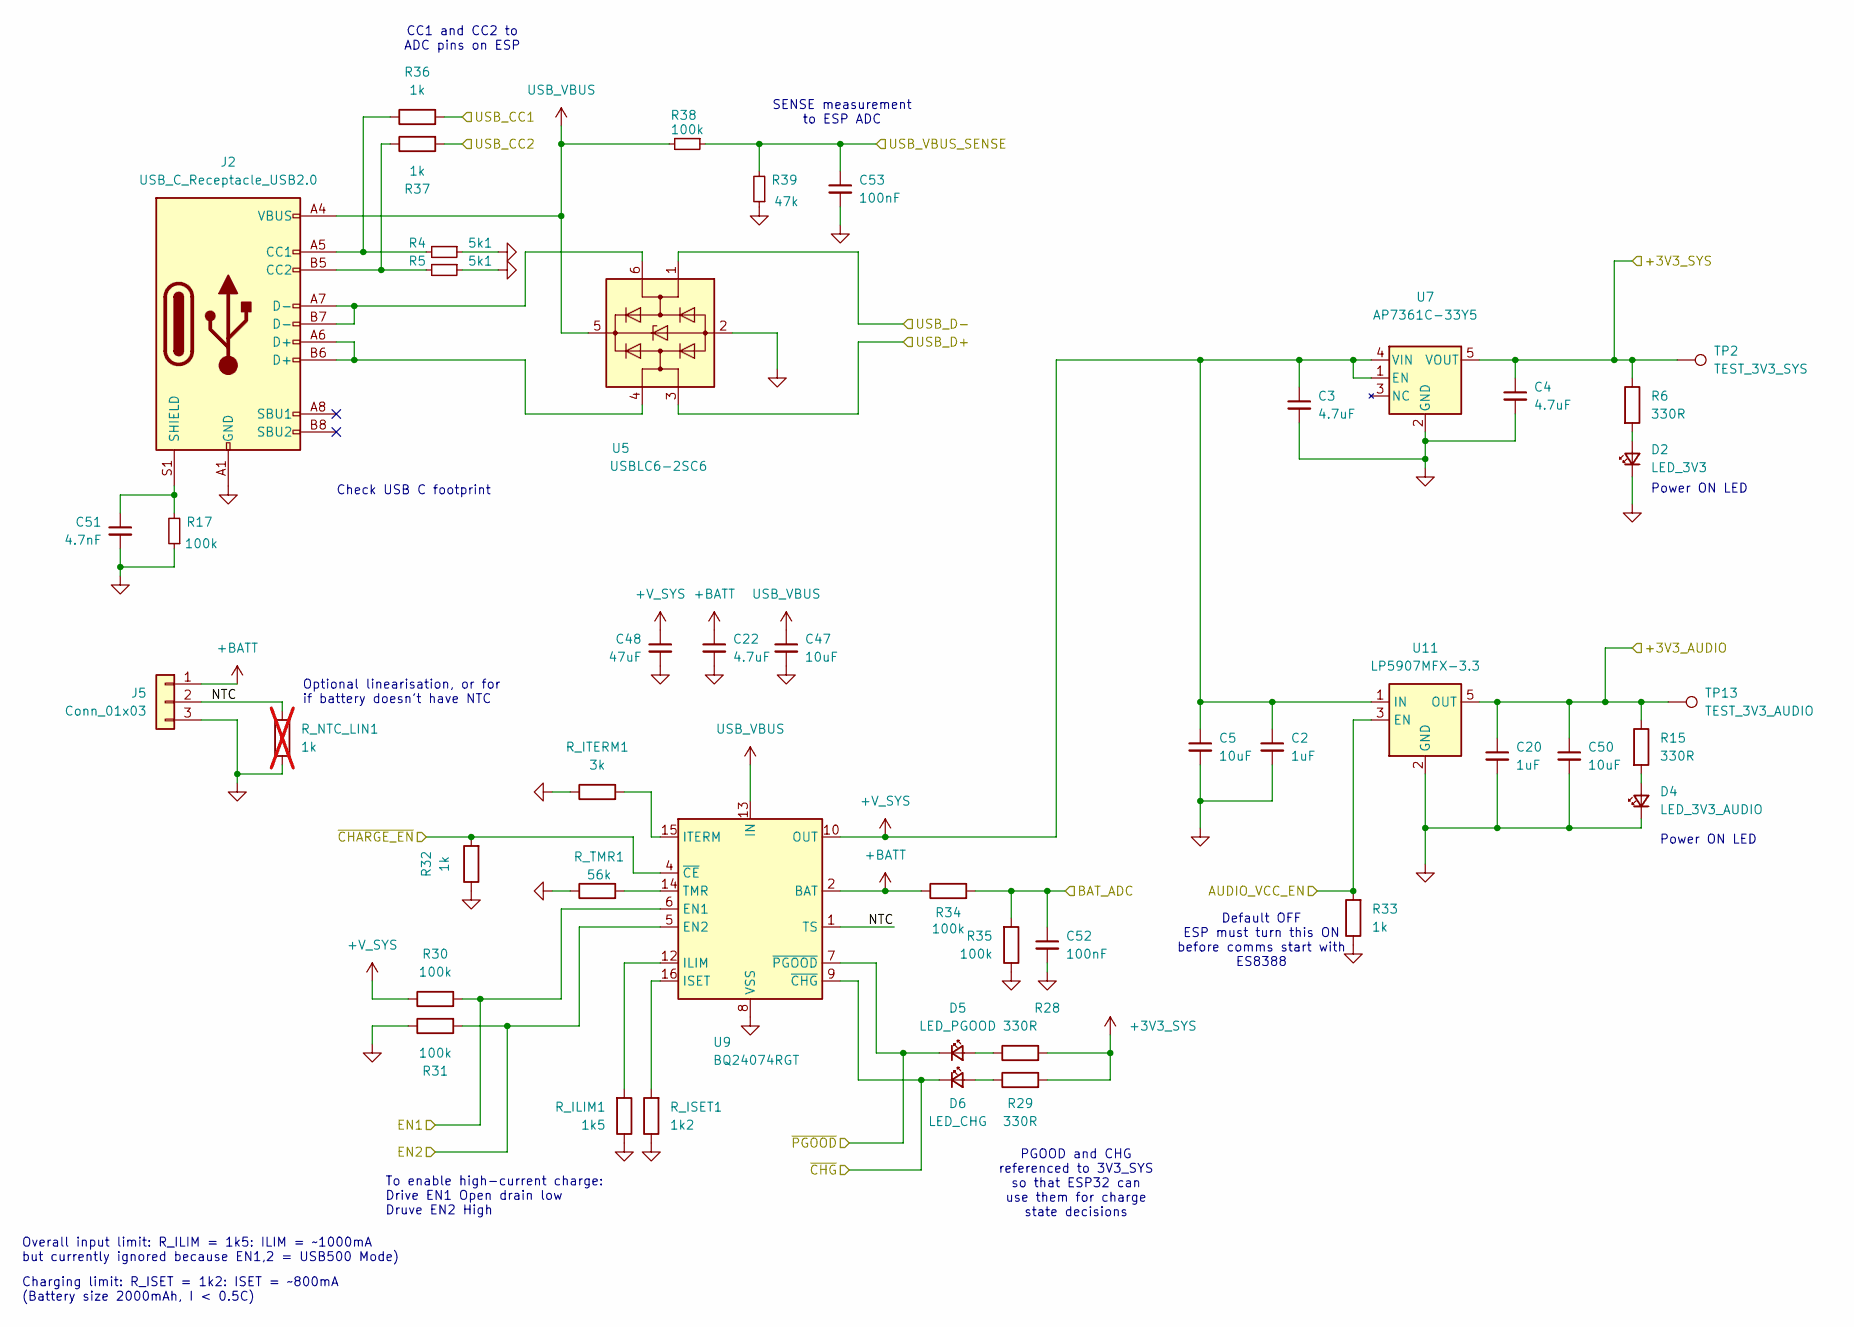
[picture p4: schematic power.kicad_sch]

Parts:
C2: 1uF; C_1206_3216Metric; MPN CL31B105KBHNNNE; LCSC C1848
C3: 4.7uF; C_1206_3216Metric; MPN 1206B475K500NT; LCSC C29823
C4, C22: 4.7uF; C_0603_1608Metric; MPN CL10A475KO8NNNC; LCSC C19666
C5, C47, C50: 10uF; C_1206_3216Metric; MPN CL31A106KBHNNNE; LCSC C13585
C20: 1uF; C_0603_1608Metric; MPN CL10A105KB8NNNC; LCSC C15849
C48: 47uF; CP_EIA-3528-21_Kemet-B; MPN TAJB476K010RNJ; LCSC C22036
C51: 4.7nF; C_0402_1005Metric; MPN 0402B472K500NT; LCSC C1538
C52: 100nF; C_1206_3216Metric; MPN CL31B104KBCNNNC; LCSC C24497
C53: 100nF; C_0402_1005Metric; MPN CL05B104KO5NNNC; LCSC C1525
D2: LED_3V3; LED_0805_2012Metric; MPN KT-0805G; LCSC C2297
D4: LED_3V3_AUDIO; LED_0805_2012Metric; MPN KT-0805G; LCSC C2297
D5: LED_PGOOD; LED_0805_2012Metric; MPN KT-0805G; LCSC C2297
D6: LED_CHG; LED_0805_2012Metric; MPN KT-0805Y; LCSC C2296
J2: USB_C_Receptacle_USB2.0; USB_C_Receptacle_GCT_USB4110; MPN USB4110-GF-A; LCSC C5143397
J5: Conn_01x03; JST_PH_S3B-PH-K_1x03_P2.00mm_Horizontal; MPN S3B-PH-K-S(LF)(SN); LCSC C157929
R4, R5: 5k1; R_0402_1005Metric; MPN 0402WGF5101TCE; LCSC C25905
R6, R15, R28, R29: 330R; R_0402_1005Metric; MPN 0402WGF3300TCE; LCSC C25104
R17, R30, R31, R34, R35, R38: 100k; R_0402_1005Metric; MPN 0402WGF1003TCE; LCSC C25741
R32, R33, R36, R37: 1k; R_0402_1005Metric; MPN 0402WGF1001TCE; LCSC C11702
R39: 47k; R_0402_1005Metric; MPN 0402WGF4702TCE; LCSC C25792
R_ILIM1: 1k5; R_0402_1005Metric; MPN 0402WGF1501TCE; LCSC C25867
R_ISET1: 1k2; R_0402_1005Metric; MPN 0402WGF1201TCE; LCSC C25862
R_ITERM1: 3k; R_0402_1005Metric; MPN 0402WGF3001TCE; LCSC C25784
R_NTC_LIN1: 1k; R_0402_1005Metric; MPN 0402WGF1001TCE; LCSC C11702; not fitted
R_TMR1: 56k; R_0402_1005Metric; MPN 0402WGF5602TCE; LCSC C25796
TP2: TEST_3V3_SYS; TestPoint_Pad_D1.0mm
TP13: TEST_3V3_AUDIO; TestPoint_Pad_D1.0mm
U5: USBLC6-2SC6; SOT-23-6; MPN USBLC6-2SC6; LCSC C7519
U7: AP7361C-33Y5; SOT-89-5; MPN AP7361C-33Y5-13; LCSC C460397
U9: BQ24074RGT; VQFN-16-1EP_3x3mm_P0.5mm_EP1.6x1.6mm; MPN BQ24074RGTR; LCSC C54313
U11: LP5907MFX-3.3; SOT-23-5; MPN LP5907MFX-3.3/NOPB; LCSC C80670

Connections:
+3V3_AUDIO: C20.1, C50.1, R15.1, TP13.1 (1_1), U11.5 (OUT); also elsewhere on the board
+3V3_SYS: C4.1, R6.1, R28.2, R29.2, TP2.1 (1_1), U7.5 (VOUT); also elsewhere on the board
+BATT: C22.1, J5.1, R34.1, U9.2 (BAT), U9.3 (BAT)
+V_SYS: C2.1, C3.1, C5.1, C48.1, R30.1, U7.1 (EN), U7.4 (VIN), U9.10 (OUT), U9.11 (OUT), U11.1 (IN)
/Micro/AUDIO_VCC_EN: R33.2, U11.3 (EN); also elsewhere on the board
/Micro/BAT_ADC: C52.1, R34.2, R35.2; also elsewhere on the board
/Micro/EN1: R30.2, U9.6 (EN1); also elsewhere on the board
/Micro/EN2: R31.2, U9.5 (EN2); also elsewhere on the board
/Micro/USB_CC1: R36.2; also elsewhere on the board
/Micro/USB_CC2: R37.2; also elsewhere on the board
/Micro/USB_D+: U5.3 (I/O2); also elsewhere on the board
/Micro/USB_D-: U5.1 (I/O1); also elsewhere on the board
/Micro/USB_VBUS_SENSE: C53.1, R38.1, R39.2; also elsewhere on the board
/Micro/~CHARGE_EN: R32.2, U9.4 (~CE); also elsewhere on the board
/Micro/~CHG: D6.1 (K), U9.9 (~CHG); also elsewhere on the board
/Micro/~PGOOD: D5.1 (K), U9.7 (~PGOOD); also elsewhere on the board
/Power/NTC: J5.2, R_NTC_LIN1.2, U9.1 (TS)
/Power/USB_CONN_D+: J2.A6 (D+), J2.B6 (D+), U5.4 (I/O2)
/Power/USB_CONN_D-: J2.A7 (D-), J2.B7 (D-), U5.6 (I/O1)
GND: C2.2, C3.2, C4.2, C5.2, C20.2, C22.2, C47.2, C48.2, C50.2, C51.2, C52.2, C53.2, D2.1 (K), D4.1 (K), J2.A1 (GND), J2.A12 (GND), J2.B1 (GND), J2.B12 (GND), J5.3, R4.1, R5.1, R17.1, R31.1, R32.1, R33.1, R35.1, R39.1, R_ILIM1.1, R_ISET1.1, R_ITERM1.1, R_NTC_LIN1.1, R_TMR1.1, U5.2 (GND), U7.2 (GND), U9.8 (VSS), U9.17 (VSS), U11.2 (GND); also elsewhere on the board
unnamed: D2.2 (A), R6.2
unnamed: D4.2 (A), R15.2
unnamed: D5.2 (A), R28.1
unnamed: D6.2 (A), R29.1
unnamed: J2.A5 (CC1), R4.2, R36.1
unnamed: J2.B5 (CC2), R5.2, R37.1
unnamed: C51.1, J2.S1 (SHIELD), R17.2
unnamed: R_ILIM1.2, U9.12 (ILIM)
unnamed: R_ISET1.2, U9.16 (ISET)
unnamed: R_ITERM1.2, U9.15 (ITERM)
unnamed: R_TMR1.2, U9.14 (TMR)
USB_VBUS: C47.1, J2.A4 (VBUS), J2.A9 (VBUS), J2.B4 (VBUS), J2.B9 (VBUS), R38.2, U5.5 (VBUS), U9.13 (IN)

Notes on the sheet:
Charging limit: R_ISET = 1k2: ISET = ~800mA (Battery size 2000mAh, I < 0.5C)
Check USB C footprint
CC1 and CC2 to ADC pins on ESP
To enable high-current charge: Drive EN1 Open drain low Druve EN2 High
Power ON LED
Overall input limit: R_ILIM = 1k5: ILIM = ~1000mA but currently ignored because EN1,2 = USB500 Mode)
SENSE measurement to ESP ADC
PGOOD and CHG referenced to 3V3_SYS so that ESP32 can use them for charge state decisions
Default OFF ESP must turn this ON before comms start with ES8388
Optional linearisation, or for if battery doesn't have NTC

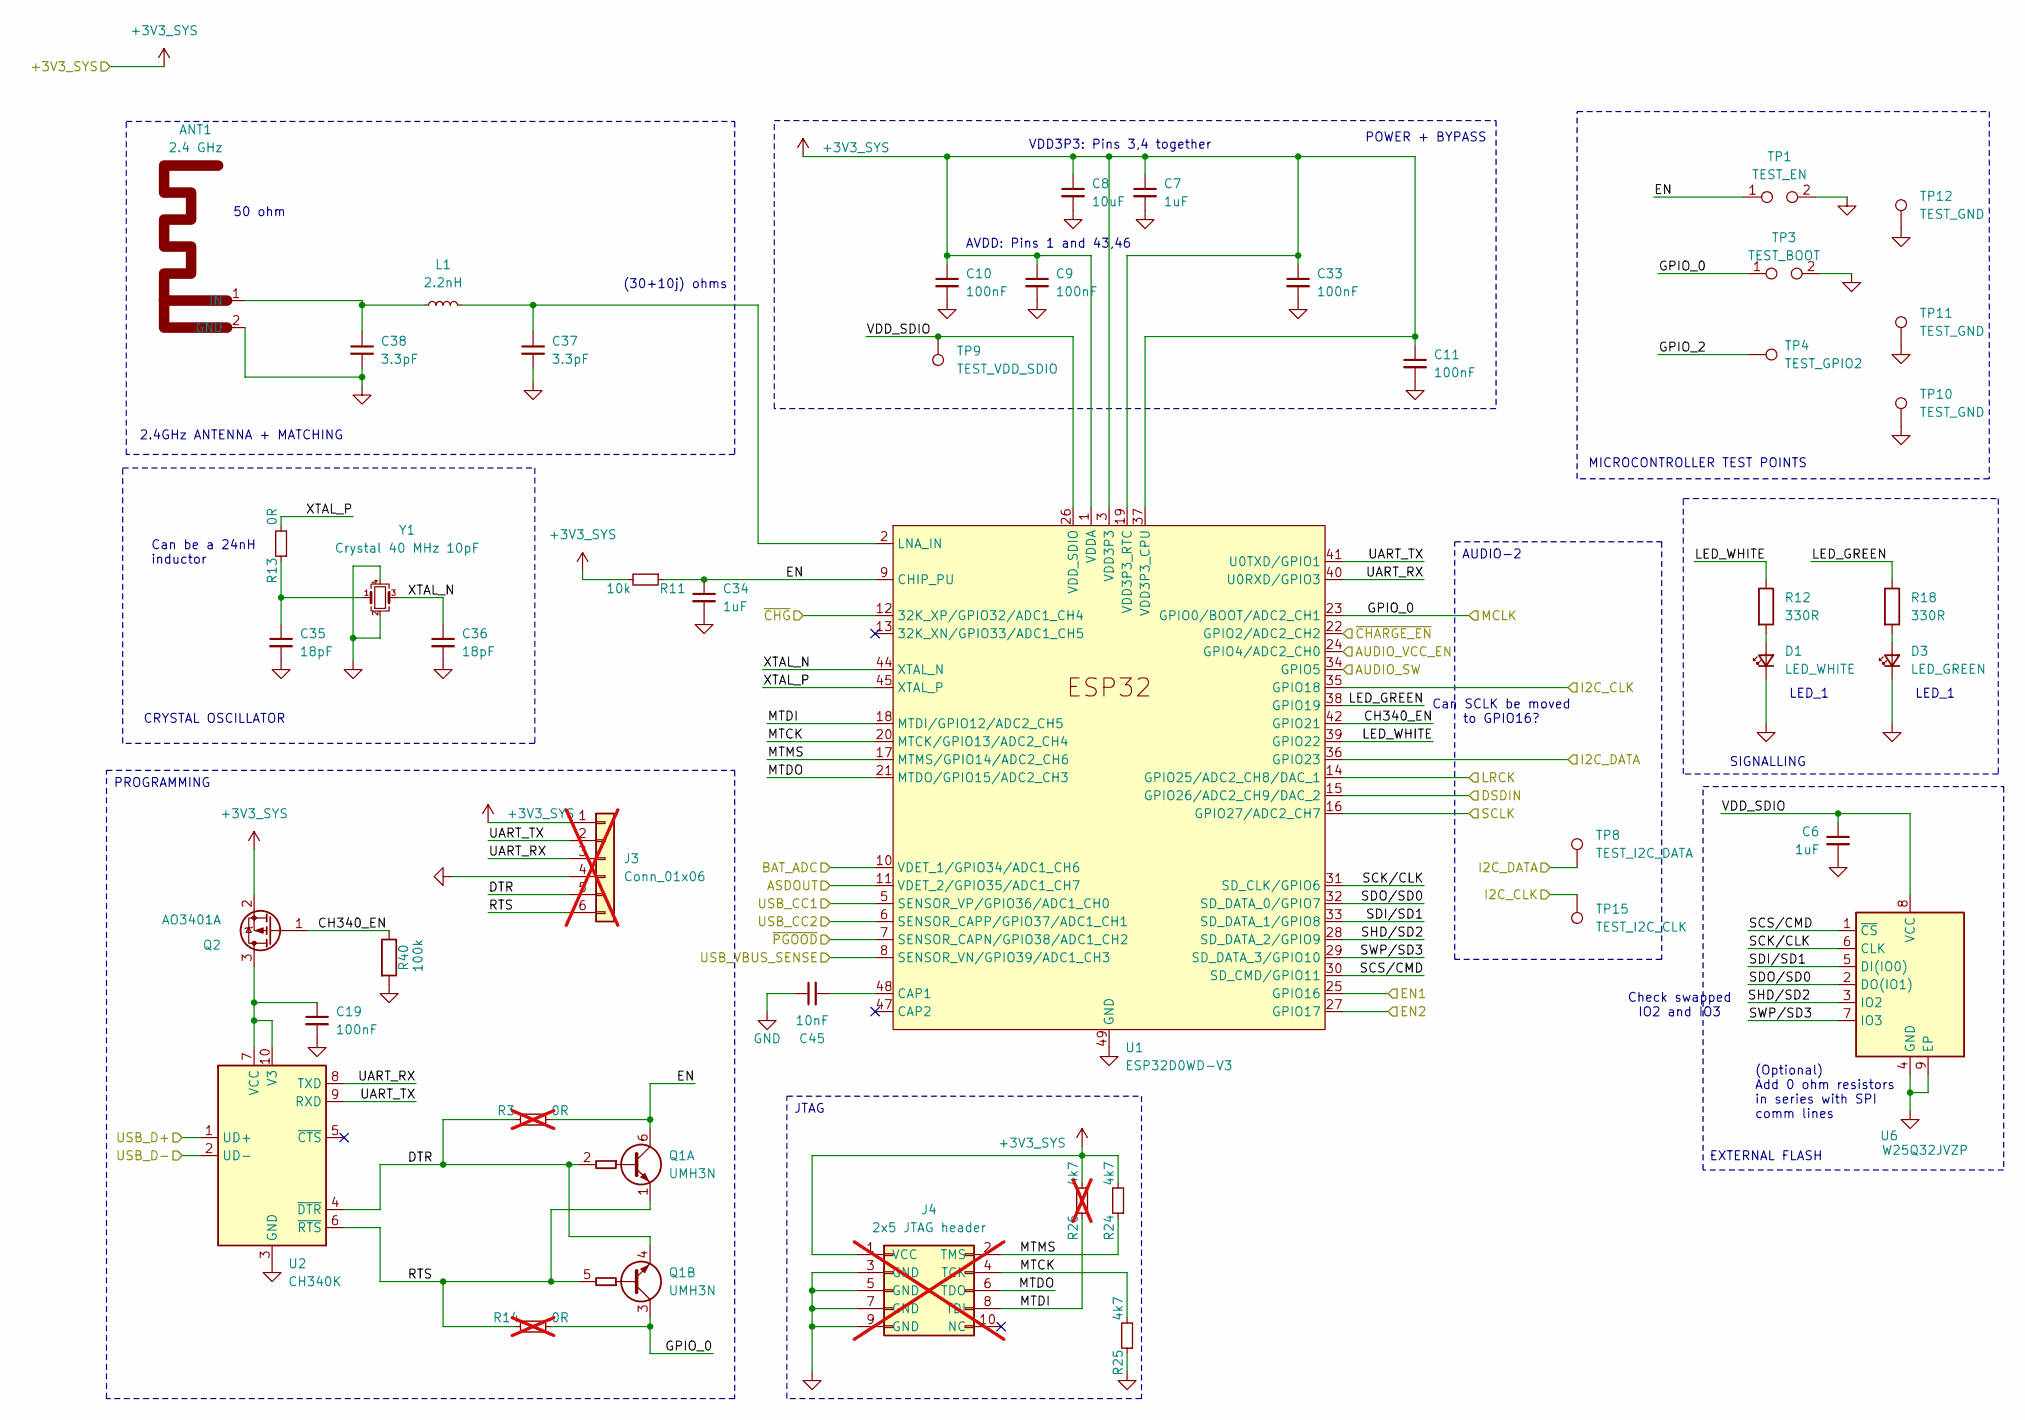
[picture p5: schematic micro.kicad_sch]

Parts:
ANT1: 2.4 GHz; Antenna 2.4GHz Inverted-F Meandered
C6, C7, C34: 1uF; C_0402_1005Metric; MPN CL05A105KA5NQNC; LCSC C52923
C8: 10uF; C_0603_1608Metric; MPN CL10A106KP8NNNC; LCSC C19702
C9, C10, C11, C19, C33: 100nF; C_0402_1005Metric; MPN CL05B104KO5NNNC; LCSC C1525
C35, C36: 18pF; C_0402_1005Metric; MPN 0402CG180J500NT; LCSC C1549
C37, C38: 3.3pF; C_0402_1005Metric; MPN GJM1555C1H3R3BB01D; LCSC C76906
C45: 10nF; C_0402_1005Metric; MPN CL05B103KB5NNNC; LCSC C15195
D1: LED_WHITE; LED_0805_2012Metric; MPN KT-0805W; LCSC C34499
D3: LED_GREEN; LED_0805_2012Metric; MPN KT-0805G; LCSC C2297
J3: Conn_01x06; PinHeader_1x06_P2.54mm_Vertical; not fitted
J4: 2x5 JTAG header; 2x5 2mm JTAG header pads only; not fitted
L1: 2.2nH; L_0402_1005Metric; MPN LQG15HS2N2S02D; LCSC C86061
Q1: UMH3N; SOT-363_SC-70-6; MPN UMH3N; LCSC C62892
Q2: AO3401A; SOT-23; MPN AO3401A; LCSC C15127
R3, R14: 0R; R_0402_1005Metric; MPN 0402WGF0000TCE; LCSC C17168; not fitted
R11: 10k; R_0402_1005Metric; MPN 0402WGF1002TCE; LCSC C25744
R12, R18: 330R; R_0402_1005Metric; MPN 0402WGF3300TCE; LCSC C25104
R13: 0R; R_0402_1005Metric; MPN 0402WGF0000TCE; LCSC C17168
R24, R25: 4k7; R_0402_1005Metric; MPN 0402WGF4701TCE; LCSC C25900
R26: 4k7; R_0402_1005Metric; MPN 0402WGF4701TCE; LCSC C25900; not fitted
R40: 100k; R_0402_1005Metric; MPN 0402WGF1003TCE; LCSC C25741
TP1: TEST_EN; TestPoint_Pad_2x1_D1.0mm
TP3: TEST_BOOT; TestPoint_Pad_2x1_D1.0mm
TP4: TEST_GPIO2; TestPoint_Pad_D1.0mm
TP8: TEST_I2C_DATA; TestPoint_Pad_D1.0mm
TP9: TEST_VDD_SDIO; TestPoint_Pad_D1.0mm
TP10, TP11, TP12: TEST_GND; TestPoint_Pad_D1.0mm
TP15: TEST_I2C_CLK; TestPoint_Pad_D1.0mm
U1: ESP32D0WD-V3; QFN-48-1EP_5x5mm_P0.35mm_EP3.7x3.7mm_ThermalVias; MPN ESP32-D0WD-V3; LCSC C967021
U2: CH340K; SSOP-10-1EP_3.9x4.9mm_P1mm_EP2.1x3.3mm; MPN CH340K; LCSC C968586
U6: W25Q32JVZP; WSON-8-1EP_6x5mm_P1.27mm_EP3.4x4.3mm; MPN W25Q32JVZPIQ; LCSC C571260
Y1: Crystal 40 MHz 10pF; Crystal_SMD_2520-4Pin_2.5x2.0mm; MPN E2SB40E000006E; LCSC C1021653

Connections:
+3V3_SYS: C7.1, C8.1, C9.1, C10.1, C11.1, C33.1, J3.1, J4.1 (VCC), Q2.2 (S), R11.2, R24.2, R26.2, U1.1 (VDDA), U1.3 (VDD3P3), U1.4 (VDD3P3), U1.19 (VDD3P3_RTC), U1.37 (VDD3P3_CPU), U1.43 (VDDA), U1.46 (VDDA); also elsewhere on the board
/Micro/ANT_FEED: ANT1.1 (IN), C38.1, L1.1
/Micro/ASDOUT: U1.11 (VDET_2/GPIO35/ADC1_CH7); also elsewhere on the board
/Micro/AUDIO_SW: U1.34 (GPIO5); also elsewhere on the board
/Micro/AUDIO_VCC_EN: U1.22 (GPIO2/ADC2_CH2); also elsewhere on the board
/Micro/BAT_ADC: U1.8 (SENSOR_VN/GPIO39/ADC1_CH3); also elsewhere on the board
/Micro/CH340_EN: Q2.1 (G), R40.1, U1.42 (GPIO21)
/Micro/DSDIN: U1.15 (GPIO26/ADC2_CH9/DAC_2); also elsewhere on the board
/Micro/DTR: J3.5, Q1.2 (B1), Q1.4 (E2), R3.1, U2.4 (~DTR)
/Micro/EN: C34.1, Q1.6 (C1), R3.2, R11.1, TP1.1, U1.9 (CHIP_PU)
/Micro/EN1: U1.27 (GPIO17); also elsewhere on the board
/Micro/EN2: U1.25 (GPIO16); also elsewhere on the board
/Micro/GPIO_0: Q1.3 (C2), R14.2, TP3.1, U1.23 (GPIO0/BOOT/ADC2_CH1); also elsewhere on the board
/Micro/GPIO_2: TP4.1 (1_1)
/Micro/I2C_CLK: TP15.1 (1_1), U1.35 (GPIO18); also elsewhere on the board
/Micro/I2C_DATA: TP8.1 (1_1), U1.36 (GPIO23); also elsewhere on the board
/Micro/LED_GREEN: R18.1, U1.38 (GPIO19)
/Micro/LED_WHITE: R12.1, U1.39 (GPIO22)
/Micro/LNA_IN: C37.1, L1.2, U1.2 (LNA_IN)
/Micro/LRCK: U1.14 (GPIO25/ADC2_CH8/DAC_1); also elsewhere on the board
/Micro/MTCK: J4.4 (TCK), R25.2, U1.20 (MTCK/GPIO13/ADC2_CH4)
/Micro/MTDI: J4.8 (TDI), R26.1, U1.18 (MTDI/GPIO12/ADC2_CH5)
/Micro/MTDO: J4.6 (TDO), U1.21 (MTDO/GPIO15/ADC2_CH3)
/Micro/MTMS: J4.2 (TMS), R24.1, U1.17 (MTMS/GPIO14/ADC2_CH6)
/Micro/RTS: J3.6, Q1.1 (E1), Q1.5 (B2), R14.1, U2.6 (~RTS)
/Micro/SCK/CLK: U1.31 (SD_CLK/GPIO6), U6.6 (CLK)
/Micro/SCLK: U1.16 (GPIO27/ADC2_CH7); also elsewhere on the board
/Micro/SCS/CMD: U1.30 (SD_CMD/GPIO11), U6.1 (~CS)
/Micro/SDI/SD1: U1.33 (SD_DATA_1/GPIO8), U6.5 (DI(IO0))
/Micro/SDO/SD0: U1.32 (SD_DATA_0/GPIO7), U6.2 (DO(IO1))
/Micro/SHD/SD2: U1.28 (SD_DATA_2/GPIO9), U6.3 (IO2)
/Micro/SWP/SD3: U1.29 (SD_DATA_3/GPIO10), U6.7 (IO3)
/Micro/UART_RX: J3.3, U1.40 (U0RXD/GPIO3), U2.8 (TXD)
/Micro/UART_TX: J3.2, U1.41 (U0TXD/GPIO1), U2.9 (RXD)
/Micro/USB_CC1: U1.6 (SENSOR_CAPP/GPIO37/ADC1_CH1); also elsewhere on the board
/Micro/USB_CC2: U1.5 (SENSOR_VP/GPIO36/ADC1_CH0); also elsewhere on the board
/Micro/USB_D+: U2.1 (UD+); also elsewhere on the board
/Micro/USB_D-: U2.2 (UD-); also elsewhere on the board
/Micro/USB_VBUS_SENSE: U1.10 (VDET_1/GPIO34/ADC1_CH6); also elsewhere on the board
/Micro/VDD_SDIO: C6.1, TP9.1 (1_1), U1.26 (VDD_SDIO), U6.8 (VCC)
/Micro/XTAL_N: C36.1, U1.44 (XTAL_N), Y1.3
/Micro/XTAL_P: R13.2, U1.45 (XTAL_P)
/Micro/~CHARGE_EN: U1.24 (GPIO4/ADC2_CH0); also elsewhere on the board
/Micro/~CHG: U1.12 (32K_XP/GPIO32/ADC1_CH4); also elsewhere on the board
/Micro/~PGOOD: U1.7 (SENSOR_CAPN/GPIO38/ADC1_CH2); also elsewhere on the board
GND: ANT1.2 (GND), C6.2, C7.2, C8.2, C9.2, C10.2, C11.2, C19.2, C33.2, C34.2, C35.2, C36.2, C37.2, C38.2, C45.1, D1.1 (K), D3.1 (K), J3.4, J4.3 (GND), J4.5 (GND), J4.7 (GND), J4.9 (GND), R25.1, R40.2, TP1.2, TP3.2, TP10.1 (1_1), TP11.1 (1_1), TP12.1 (1_1), U1.49 (GND), U2.3 (GND), U2.11 (GND), U6.4 (GND), U6.9 (EP), Y1.2, Y1.4; also elsewhere on the board
unnamed: C35.1, R13.1, Y1.1
unnamed: D1.2 (A), R12.2
unnamed: D3.2 (A), R18.2
unnamed: C19.1, Q2.3 (D), U2.7 (VCC), U2.10 (V3)
unnamed: C45.2, U1.48 (CAP1)

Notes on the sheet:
MICROCONTROLLER TEST POINTS
LED_1
(30+10j) ohms
50 ohm
SIGNALLING
2.4GHz ANTENNA + MATCHING
(Optional) Add 0 ohm resistors in series with SPI comm lines
VDD3P3: Pins 3,4 together
EXTERNAL FLASH
AVDD: Pins 1 and 43,46
Check swapped IO2 and IO3
POWER + BYPASS
CRYSTAL OSCILLATOR
Can be a 24nH inductor
Can SCLK be moved to GPIO16?
AUDIO-2
JTAG
PROGRAMMING

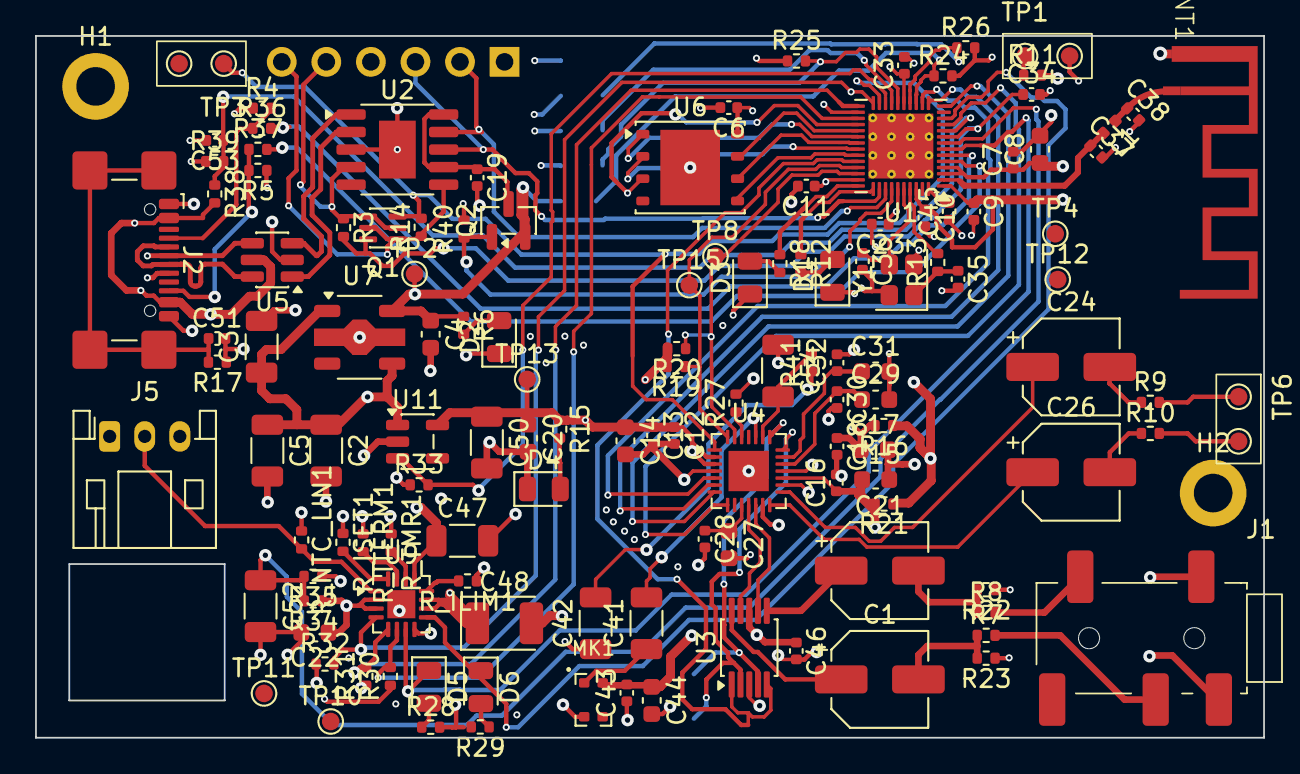
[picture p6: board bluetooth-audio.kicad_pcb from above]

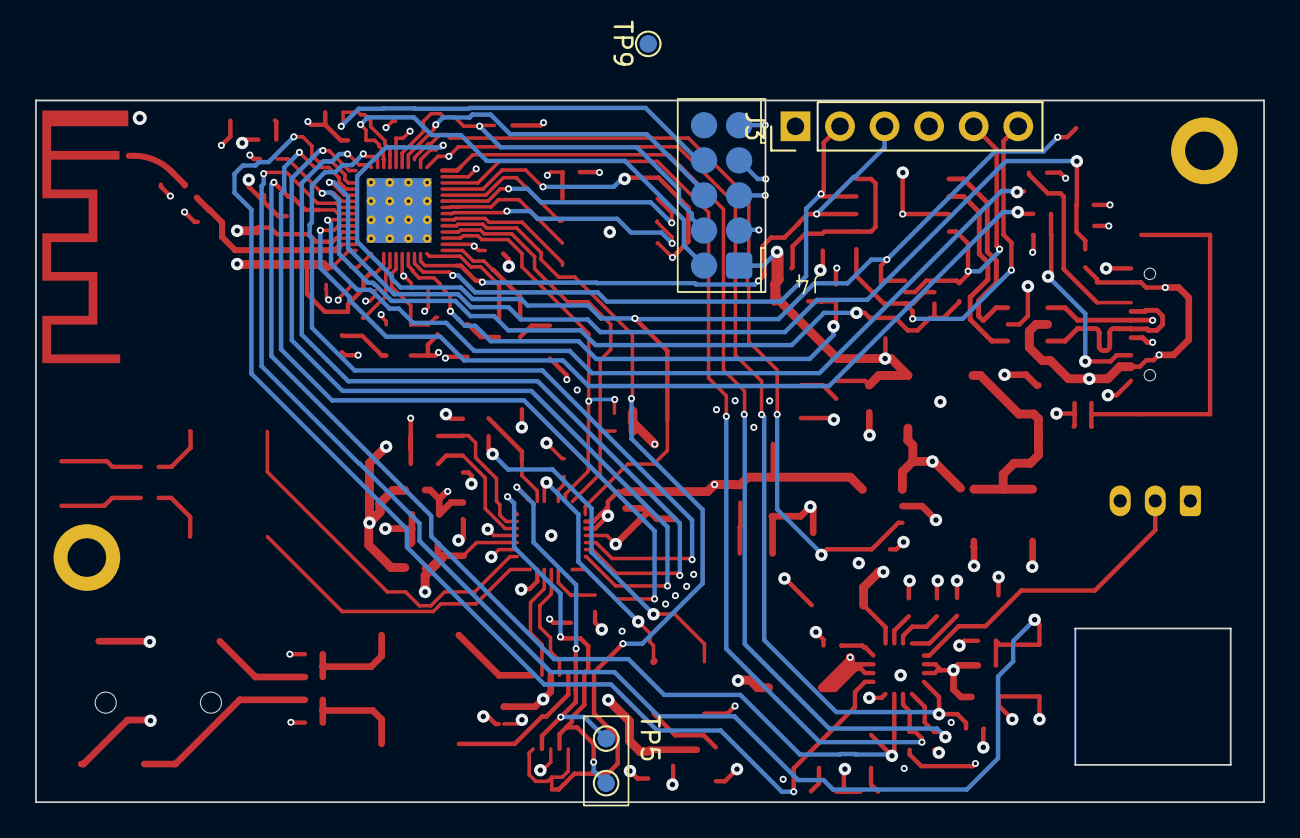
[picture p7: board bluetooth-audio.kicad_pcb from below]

Board: 4 copper layers, 70.0 x 40.0 mm, 135 parts (4 on the bottom side), 94 nets.

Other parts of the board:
C23: 100nF; C_0402_1005Metric

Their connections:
+3V3_SYS: C23.1; also elsewhere on the board
GND: C23.2; also elsewhere on the board

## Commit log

2024-10-28 Adding blank Kicad project
    [bluetooth-audio.kicad_pcb, bluetooth-audio.kicad_sch]
2024-10-30 Created power schematic with buck converter and LDO. Including calculations and datasheets
    [bluetooth-audio.kicad_sch, calculations.xlsx, power.kicad_sch]
2024-10-31 Microcontroller schematic sheet with decoupling, crystals, RF matching etc. Various app notes
    [DLF162500LT-5028A1.STEP, bluetooth-audio.kicad_sch, calculations.xlsx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]
2025-04-05 Custom footprints for microphone, jtag header, antenna and dual testpoint
2025-04-05 Updated design doc
    [calculations.xlsx]
2025-04-05 Completed design with ESP32D0WD-v3, and JLC production files. High production cost due to req of PCBA standard, due to ESP32 pin pitch.
    [audio.kicad_sch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]
2026-08-28 Add repo tooling: gitignore, gitattributes, design-doc pre-commit hook
    Repo hygiene, none of which existed before.
    - .gitattributes pins KiCad sources to LF. Without it a Windows checkout
    rewrites every line on clone and the next save reads as a whole-file diff,
    which makes schematic history unreadable. Also marks PDF/STEP/xlsx/zip
    binary so they are never diffed or merged.
    - .gitignore covers what hw/.gitignore does not: *.kicad_prl (per-user window
    state, changes on every open), *-bak, .history/ and Office lock files.
    - .githooks/pre-commit re-stamps the date on docs/design-overview.md and
    regenerates its PDF from the staged content, so the snapshot can never drift
    from the ma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
2026-08-28 Schematic: split supply into separate audio and system 3V3 rails
    First design work since the April 2025 production release. Sixteen months of
    edits had accumulated uncommitted; this captures the schematic and board state.
    Power topology change: the single 3.3 V supply is now two independent rails,
    +3V3_SYS and +3V3_AUDIO, each with its own regulator (U7, U8) and test point
    (TEST_3V3_SYS, TEST_3V3_AUDIO). This isolates the ES8388 and the mic from the
    ~250 mA Bluetooth TX bursts on the ESP32 rail, which design-review-v1 flagged
    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
    [audio.kicad_sch, bluetooth-audio.kicad_sch, calculations.xlsx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]
2026-08-28 Move custom libraries out to a shared repo
    Symbols, footprints and 3D models now live in jasonarnoldarnie/kicad-library,
    registered globally in KiCad via a KICAD_USER_LIB environment variable, so
    every project picks them up with no per-project setup.
    Library nicknames are unchanged (custom_symbols, custom_footprints), so every
    lib_id in the schematics and every footprint reference in the board resolves
    exactly as before. Verified: all four symbols and all four footprints the
    design actually uses resolve from the new location. No schematic or board edit
    was needed.
    Context: both project library tables pointed at ${KIPRJMOD}/symbols/ and
    ${KIPRJMOD}/footprints/, neither of which ever existed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
    [DLF162500LT-5028A1.STEP]
2026-08-28 Add design documentation and record the review round trip
    None of this had ever been committed. Six documents covering requirements,
    review findings and the decisions taken since, written between 2026-08-20 and
    today and previously existing only in the working tree.
    - requirements-design.md requirements with traceability to schematic refs,
    the cost model, and the part shortlists for both
    regulator rails
    - design-overview.md the target design (Rev B), power tree, signal chain
    and thermal analysis. Deltas from as-built Rev A in
    its section 10
    - design-review-v1.md netlist-l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
2026-08-28 Correct the session log: the rail split was already done
    Two errors in the entry written earlier today.
    The claim that power.kicad_sch had NCP1117 as "its only regulator, the split is
    not started" came from reading a `sort -u` of lib_ids, which collapses two
    instances of the same part into one line. There are two regulators, U7 and U8,
    feeding +3V3_SYS and +3V3_AUDIO. What actually remains is the part swap to
    AP7361C-33Y5 and LP5907MFX-3.3, not the topology work.
    Also records that the fab package under production/jlc_pcba/ is byte-identical
    to the April 2025 commit and therefore stale, and replaces the note blaming
    Google Drive for the dirty working tree: the schematics had genuinely chang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
2026-08-30 Power sheet: charger configuration, mode strapping and telemetry
    Schematic (power sheet):
    - R_ISET 4k7 -> 1k2 (742 mA fast charge), R_ILIM 3k -> 1k5 (1.073 A)
    - EN1/EN2 strapping inverted and made overridable: R30 100k pulls EN1
    up to SYS, R31 100k pulls EN2 down. Default is now USB500, not the
    fixed ILIM strap -- 100 mA of USB100 cannot boot a 171 mA system on a
    flat cell, and USB500 is the mode that has VIN-DPM behind it.
    - EN1, EN2, /PGOOD, /CHG, BAT_ADC, USB_CC1, USB_CC2 promoted to global
    labels, ready for the micro sheet.
    - Status LED pull-ups R28/R29 moved SYS -> 3V3_A so /PGOOD and /CHG are
    3.3 V logic a GPIO can read; 4.4 V exceeds the ESP32 input rating.
    - Add R34/R35 100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
    [audio.kicad_sch, power.kicad_sch]
2026-08-30 Power sheet complete: ADC anti-droop caps, VBUS sense, LED brightness
    - R_ITERM 3k and R_TMR 56k populated (were DNP; R_TMR also still carried
    a 0R value, which grounds TMR and disables the safety timers rather
    than programming them).
    - R28/R29 1k -> 330R. With the pull-ups now on 3V3_A instead of the
    4.4 V SYS rail, 1k gave ~0.9 mA and the LEDs were invisible again.
    - C52 100nF on BAT_ADC, C53 100nF on USB_VBUS_SENSE. Both dividers sit
    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
    [power.kicad_sch]
2026-09-03 Rev B micro sheet: correctness fixes, CH340 load switch, full ESP32 GPIO map
    Micro-sheet fixes (netlist-verified):
    - UART TX/RX crossover corrected (U0RXD<->CH340 TXD, U0TXD<->CH340 RXD)
    - Flash IO2/IO3 uncrossed (GPIO9/SPIWP->IO2, GPIO10/SPIHD->IO3)
    - Digital rail unified to +3V3_SYS; EN pull-up (R11) reconnected
    CH340K high-side load switch (delta #16):
    - Q2 AO3401A (SOT-23, LCSC C15127) + R40 100k gate pull-down = default-ON
    so the ROM bootloader is powered for USB flashing; gate CH340_EN on GPIO21,
    firmware drives high to disable the bridge on battery
    Full ESP32 interface wired (see design-overview.md 3.8):
    - EN1->16, EN2->17, AUDIO_VCC_EN->4, AUDIO_SW->5, CH340_EN->21, CHARGE_EN->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
    [audio.kicad_sch, bluetooth-audio.kicad_pcb, bluetooth-audio.kicad_sch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]
2026-09-10 Audio sheet redesign: ZTS6216 mic, PJ-3537S jack, shared 47 uF coupling
    Rework the audio subsystem and record the rationale.
    - Microphone: switch to ZillTek ZTS6216 (self-biased single-ended, C0G
    mic coupling C41/C42 per datasheet); pseudo-diff RIN1 provisioned DNP.
    - Jack: PJ-3537S 3-pole TRS + detect switch (custom symbol + footprint).
    - Coupling: single shared 47 uF electrolytic pair (C1/C21) on the jack
    side of the TX/RX switch, serving both RX and TX; R22/R23 bleed.
    - TX input: BAT54S series-Schottky clamps (D7/D8) to AVDD/GND,
    line-level-only, PGA 0 dB.
    - Ground loop: battery-only playback is the plan of record (no
    transformer footprint).
    - Add TS5A23159 switch, ZTS6216 and PJ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
    [audio.kicad_sch, bluetooth-audio.kicad_pcb, bluetooth-audio.kicad_sch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]
2026-09-10 gitignore: ignore *.bak symbol/footprint editor backups
2026-09-11 BOM sanity check: fix part numbers, populate passives, normalise fields
    Full footprint + LCSC audit across power/audio/micro sheets (see
    docs/bom-audit.md). Every part now carries Manufacturer + MPN + LCSC in one
    consistent field set, validated against the jlcparts snapshot.
    Corrections:
    - Fix C1849 mis-assignment: it is a 10uF 1206 MLCC that had been pasted onto
    14 caps of unrelated values (incl. the 18pF crystal load caps); each
    reassigned to the correct part, stale Supplier Part Number cleared.
    - D1 LED_BLUE was a white LED (C34499) -> C2293 (KT-0805B, blue).
    - Populate all resistors/caps/L1 with JLCPCB parts (Basic where available;
    C0G for crystal-load 18pF, RF 3.3pF, and preserve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
    [audio.kicad_sch, micro.kicad_sch, power.kicad_sch]
2026-09-11 Remove redundant in-project custom library copies
    Custom symbols/footprints now live in the shared repo at
    C:\Users\jason\electronics\kicad-library, resolved via the global KiCad lib
    tables + ${KICAD_USER_LIB}. The project's own sym-lib-table/fp-lib-table are
    empty and it references parts by nickname (custom_symbols:*, custom_footprints:*),
    so these in-project copies were dead weight — the local custom_symbols.kicad_sym
    held only PJ-3537S-SMT while the schematic already resolves ES8388/ZTS6216 etc.
    from the consolidated library.
2026-09-11 Add kicad-library as a submodule; point project lib tables at it
    Makes the project self-contained: custom parts now come from the pinned
    kicad-library submodule at hw/bluetooth-audio/kicad-library instead of
    depending on the global lib table + ${KICAD_USER_LIB}.
    - Submodule pinned to kicad-library b52c421 (includes ZTS6216, PJ-3537S, etc.).
    - Project sym-lib-table/fp-lib-table register custom_symbols/custom_footprints
    via ${KIPRJMOD}/kicad-library/... so a fresh `git clone --recurse-submodules`
    resolves every custom part with no machine-specific setup.
    - Un-ignore the two lib-table files in hw/.gitignore now that they carry content.
    Clone with: git clone --recurse-submodules, or run
    `g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
2026-09-11 BOM: move C51, charger resistors and D1 to JLCPCB Basic parts
    Cuts Extended (paid-setup) parts from 25 to 20 without changing any circuit
    values:
    - C51 USB-shield filter 4.7nF: 1206 -> 0402, Basic C1538 (generic filter cap).
    - R_TMR1/R_ISET1/R_ITERM1 (56k/1.2k/3k charger programming): 0402 -> 0603 to
    get Basic parts at the SAME values (C23206/C22765/C4211) - charger behaviour
    unchanged; no Basic exists at these values in 0402.
    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
    [micro.kicad_sch, power.kicad_sch]
2026-09-16 Audio BOM: OUT2 couplers to electrolytic, C53 0402, C41/C42 land; place PCB
    Schematic (audio + power sheets):
    - C24/C26 (ES8388 OUT2 -> TP6 test-output couplers): 1uF MLCC -> 47uF
    electrolytic (Panasonic EEEFT1E470AR / C336270), matching C1/C21. Polarity
    verified against the netlist: + terminal to the codec/VMID side.
    - C53 (USB_VBUS_SENSE divider filter): 1206 -> 0402 (house part
    CL05B104KO5NNNC / C1525).
    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
    [audio.kicad_sch, bluetooth-audio.kicad_pcb, bluetooth-audio.kicad_sch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]
2026-09-17 Docs: D7/D8 clamps now removed; re-base project on kicad-library submodule
    D7/D8 (2x BAT54S) TX-input clamps were removed from the audio sheet (already
    committed in 4d0fc39; my earlier "pending" note was wrong). This brings the
    design overview in line: delta #18 reversed, §6 BOM row and §9 clamp paragraph
    dropped, audio-sheet status corrected, 2026-09-17 revision entry added.
    Rationale: LIN2/RIN2 are internal line-level nets with no external exposure, so
    the codec's own ESD structures suffice and the Schottky capacitance/leakage were
    a net cost.
    Library housekeeping:
    - Removed the orphaned in-project library copies (custom_symbols.kicad_sym,
    symbols/, footprints/, custom_footprints.pret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
    [power.kicad_sch]
2026-09-26 PCB: 4-layer SIG-GND-PWR/GND-SIG stackup
    In1.Cu is a solid GND plane; In2.Cu carries the +3V3_SYS pour with GND
    fill, so both outer signal layers sit over an adjacent uninterrupted
    reference plane. Board setup (design rules, via sizes, netclasses) and
    the JLCPCB custom DRU updated alongside the layout.
    [bluetooth-audio.kicad_pcb]
2026-09-26 Add kicad-tools submodule for the return-path checker
    The return-path checker now lives in its own repo, kicad-tools, pinned
    here at hw/kicad-tools. Unlike kicad-library it sits outside the KiCad
    project folder, since nothing resolves it through ${KIPRJMOD}.
    Also adds hw/bluetooth-audio/return_path_classes.json, the per-board
    net-class overrides the checker picks up next to the board. Without it
    GPIO_0, which is really the ES8388 MCLK, would be classed as a static
    net and its failures capped to INFO. The crystal and output
    coupling-cap nets likewise have no descriptive names.
    Run from the repo root with KiCad's bundled Python:
    "$LOCALAPPDATA/Programs/KiCad/10.0/bin/python.exe" \
    h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
